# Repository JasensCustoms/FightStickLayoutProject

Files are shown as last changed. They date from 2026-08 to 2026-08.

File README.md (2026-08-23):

# Arcade Control Panel Layouts, SVG and DXF Cut Files

**Arcade control panel layouts as true scale vector cut files, ready for CAD and CAM.**

The founding set is converted from [slagcoin.com](https://www.slagcoin.com/joystick/layout.html). More layouts get added over time, from other sources and drawn fresh, and every one carries its own credit.






Everything is drawn 1:1 in millimeters, ready to send to a laser, router or CNC. Three groups:

- **[Lever Based Layouts](#lever-based-layouts)**, anything with a joystick. The 21 Slagcoin arrangements, each supplied at 3 different lever positions and in both 30 mm and 24 mm button sizes, plus panels taken from commercial sticks, real cabinets and the community.
- **[Leverless / All Button Layouts](#leverless--all-button-layouts)**, 8 panels with no joystick, drawn as designed with their native mix of 24 mm and 30 mm holes.
- **[WASD Layouts](#wasd-layouts)**, every one of those lever layouts again with a four button directional cluster where the joystick was. The action buttons do not move.

There is also a **[case](case/README.md)**: a laser cut acrylic enclosure with 3D printed corner and center supports, 451 x 303 mm inside a 62.2 mm stack, which has room for any layout here several times over. **The case files have not been physically validated yet**, so read the disclaimer at the top of that page before cutting.

And a folder of **[support hardware](support%20hardware/README.md)**: cut files for the hardware that goes around a panel rather than in it. Connectors, pass throughs and anything else that needs a hole in a case wall or a plate, drawn 1:1 in DXF and SVG on the same conventions as everything else, with the origin on the main bore so placing one is a single translation. Drop them straight into a case wall or a panel file.

Every one of those also ships in an **inner support** version, where each button hole is merged with a relief slot for Sanwa OBSF snap in button ears. That comes to 584 layouts per format, 1168 files.

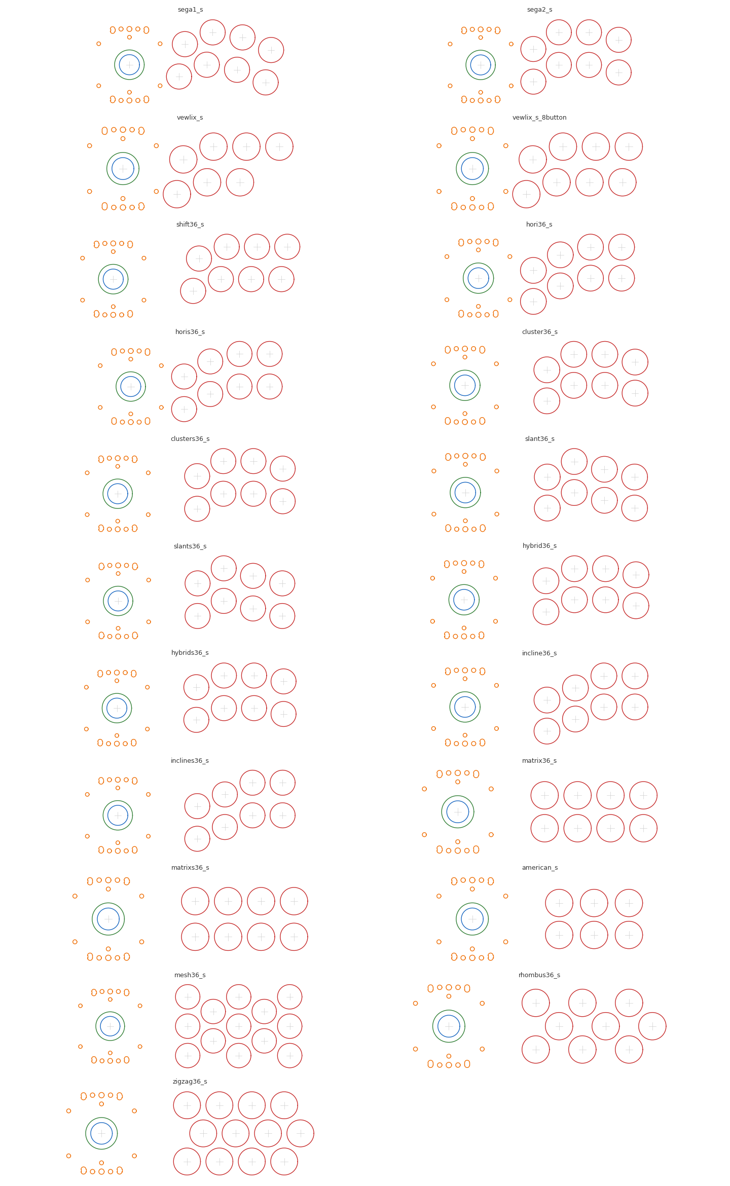
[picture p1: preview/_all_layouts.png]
The 21 Slagcoin joystick arrangements


*The 21 Slagcoin joystick arrangements at their stock lever position. Everything else, including the cabinet, commercial and community panels, is on the [contact sheets](preview/_sheet_lever_1.png) linked from each group below.*

---

## Credit where it belongs

> This repository started with **slagcoin.com**, and would not exist without it.
>
> That site has been the reference for arcade stick building for well over fifteen years. The panel layout page, the button and joystick measurement pages, the drilling and wiring guides. It is still the most careful and most useful writeup on the subject that anyone has put on the internet, and it was given away for free.
>
> Every layout in the founding set is traced from Slagcoin's own to scale diagrams, and each of those catalog entries quotes his description. If you build anything from these files, go read [the original pages](https://www.slagcoin.com/joystick/layout.html) first. There is a lot of reasoning there about *why* the layouts are shaped the way they are, and it will make you better at picking one.

The all button layouts come from a different place. They were created by [JasensCustoms.com](https://www.jasenscustoms.com) and members of the Panzer user community, and are credited in [their own section](#leverless--all-button-layouts). The S24, S30 and B30 layouts belong to [ASI](#asi-s24). The Mortal Kombat 3 panel, and its Japanese hardware variant, are traced from a dimensioned drawing by **Twistedsymphony**, hosted at [classicarcadecabinets.com](https://www.classicarcadecabinets.com/mortal-kombat-3.html). The Neo Geo MVS Type 1 panel comes from a drilling template by **Crowquilll**. The other four Neo Geo panels, Type 2, the Mini, the MVS-U4 and the SC19-4, were requested and researched by **KidGamer77** on [issue 3](https://github.com/JasensCustoms/FightStickLayoutProject/issues/3) and measured from the reference art found there. The two IST MakeStick layouts were requested by **lasagnasf** on [issue 4](https://github.com/JasensCustoms/FightStickLayoutProject/issues/4) and recreated from the product photographs supplied with it; the layout is IST Mall's.

**Where a layout came from is recorded with the layout.** Every catalog entry names its origin, and [NOTICE.md](NOTICE.md) is the full register of sources. Nothing in here silently claims someone else's design work.

---

## Contents

- [Quick start](#quick-start)
- [What is in the box](#what-is-in-the-box)
- [Reading the file names](#reading-the-file-names)
- [What is in every file](#what-is-in-every-file)
- [Joystick spacing](#joystick-spacing)
- [24 mm button versions](#24-mm-button-versions)
- [Inner support versions](#inner-support-versions)
- [Lever Based Layouts](#lever-based-layouts)
  - [Sega Astro City / Blast City P1](#sega-astro-city--blast-city-p1)
  - [Sega P2, non slanted](#sega-p2-non-slanted)
  - [Vewlix, 7 button as drawn](#vewlix-7-button-as-drawn)
  - [Vewlix 4+4, 8 button](#vewlix-44-8-button)
  - [Generic shift](#generic-shift)
  - [Hori transitioning](#hori-transitioning)
  - [Hori transitioning, spaced rows](#hori-transitioning-spaced-rows)
  - [Clustered arcade](#clustered-arcade)
  - [Clustered arcade, spaced rows](#clustered-arcade-spaced-rows)
  - [Direct slant](#direct-slant)
  - [Direct slant, spaced rows](#direct-slant-spaced-rows)
  - [Moderate / hybrid](#moderate--hybrid)
  - [Moderate / hybrid, spaced rows](#moderate--hybrid-spaced-rows)
  - [Straight incline](#straight-incline)
  - [Straight incline, spaced rows](#straight-incline-spaced-rows)
  - [Square grid](#square-grid)
  - [Square grid, spaced rows](#square-grid-spaced-rows)
  - [Capcom USA Street Fighter](#capcom-usa-street-fighter)
  - [Capcom USA Street Fighter, American Parts](#capcom-usa-street-fighter-american-parts)
  - [Mesh template](#mesh-template)
  - [Rhombus template](#rhombus-template)
  - [Zigzag template](#zigzag-template)
  - [ASI S24](#asi-s24)
  - [ASI S30](#asi-s30)
  - [JasensCustoms Sega 2P IMPACT](#jasenscustoms-sega-2p-impact)
  - [Mortal Kombat 3 / Ultimate MK3](#mortal-kombat-3--ultimate-mk3)
  - [Mortal Kombat 3, Japanese hardware](#mortal-kombat-3-japanese-hardware)
  - [Neo Geo MVS Type 1](#neo-geo-mvs-type-1)
  - [Neo Geo MVS Type 1, American hardware](#neo-geo-mvs-type-1-american-hardware)
  - [Neo Geo MVS Type 2](#neo-geo-mvs-type-2)
  - [Neo Geo MVS Type 2, American hardware](#neo-geo-mvs-type-2-american-hardware)
  - [Neo Geo Mini](#neo-geo-mini)
  - [Neo Geo Mini, American hardware](#neo-geo-mini-american-hardware)
  - [Neo Geo MVS-U4](#neo-geo-mvs-u4)
  - [Neo Geo SC19-4](#neo-geo-sc19-4)
  - [IST MakeStick Type 1](#ist-makestick-type-1)
  - [IST MakeStick Type 3](#ist-makestick-type-3)
  - [Vewlix 4+4 plus four, modern](#vewlix-44-plus-four-modern)
  - [Vewlix 10 button, two 30 mm](#vewlix-10-button-two-30-mm)
  - [Full index](#full-index)
- [Leverless / All Button Layouts](#leverless--all-button-layouts)
  - [Traditional](#traditional)
  - [Modern](#modern)
  - [Tomahawk](#tomahawk)
  - [Aegis](#aegis)
  - [Shiokenstar](#shiokenstar)
  - [Slab Split](#slab-split)
  - [Split Modern](#split-modern)
  - [ASI B30](#asi-b30)
  - [All button index](#all-button-index)
- [WASD Layouts](#wasd-layouts)
  - [WASD directional cluster](#wasd-directional-cluster)
  - [Sega Astro City / Blast City P1, WASD](#sega-astro-city--blast-city-p1-wasd)
  - [Sega P2, non slanted, WASD](#sega-p2-non-slanted-wasd)
  - [Vewlix, 7 button as drawn, WASD](#vewlix-7-button-as-drawn-wasd)
  - [Vewlix 4+4, 8 button, WASD](#vewlix-44-8-button-wasd)
  - [Generic shift, WASD](#generic-shift-wasd)
  - [Hori transitioning, WASD](#hori-transitioning-wasd)
  - [Hori transitioning, spaced rows, WASD](#hori-transitioning-spaced-rows-wasd)
  - [Clustered arcade, WASD](#clustered-arcade-wasd)
  - [Clustered arcade, spaced rows, WASD](#clustered-arcade-spaced-rows-wasd)
  - [Direct slant, WASD](#direct-slant-wasd)
  - [Direct slant, spaced rows, WASD](#direct-slant-spaced-rows-wasd)
  - [Moderate / hybrid, WASD](#moderate--hybrid-wasd)
  - [Moderate / hybrid, spaced rows, WASD](#moderate--hybrid-spaced-rows-wasd)
  - [Straight incline, WASD](#straight-incline-wasd)
  - [Straight incline, spaced rows, WASD](#straight-incline-spaced-rows-wasd)
  - [Square grid, WASD](#square-grid-wasd)
  - [Square grid, spaced rows, WASD](#square-grid-spaced-rows-wasd)
  - [Capcom USA Street Fighter, WASD](#capcom-usa-street-fighter-wasd)
  - [Mesh template, WASD](#mesh-template-wasd)
  - [Rhombus template, WASD](#rhombus-template-wasd)
  - [Zigzag template, WASD](#zigzag-template-wasd)
  - [ASI S24, WASD](#asi-s24-wasd)
  - [ASI S30, WASD](#asi-s30-wasd)
  - [JasensCustoms Sega 2P IMPACT, WASD](#jasenscustoms-sega-2p-impact-wasd)
  - [Mortal Kombat 3, Japanese hardware, WASD](#mortal-kombat-3-japanese-hardware-wasd)
  - [Neo Geo MVS Type 1, WASD](#neo-geo-mvs-type-1-wasd)
  - [Vewlix 4+4 plus four, modern, WASD](#vewlix-44-plus-four-modern-wasd)
  - [Vewlix 10 button, two 30 mm, WASD](#vewlix-10-button-two-30-mm-wasd)
  - [WASD index](#wasd-index)
- [Before you cut](#before-you-cut)
- [Screw in buttons and nut clearance](#screw-in-buttons-and-nut-clearance)
- [How these were made](#how-these-were-made)
- [License and attribution](#license-and-attribution)

---

## Quick start

**If you just want the popular one:** grab [`vewlix_s_8button.dxf`](dxf/vewlix_s_8button.dxf). That is the modern 8 button tournament layout, 30 mm buttons, at the stock Japanese lever position. Running 24 mm buttons? Take [`vewlix_s_8button_24mm_buttons.dxf`](dxf/vewlix_s_8button_24mm_buttons.dxf) instead.

**If you are not sure which layout suits you:** print a few SVGs at 100 percent scale, lay your hand on them, and pick the one that feels right. This costs a sheet of paper and will save you a ruined panel.

**Three things to do before sending anything to a machine:**

1. Delete whichever of the two joystick bore layers you are not using.
2. Delete the `REFERENCE` layer. Those crosshairs are alignment aids, not cuts.
3. Cut one in scrap first.

---

## What is in the box

```
dxf/        584 layouts as .dxf   (R2010, millimeters, $INSUNITS = 4)
svg/        the same 584 layouts as .svg  (1 user unit = 1 mm)
preview/    per layout PNG previews plus contact sheets and diagrams
case/       a laser cut acrylic case with 3D printed supports, DXF, STL and STEP
support hardware/   connector and pass through cutouts, DXF and SVG
README.md   this file
```

Joystick arrangements are built out to 6 files per format: 3 lever positions, each at 30 mm and 24 mm button sizes. The 21 of them come to 126 per format. All button layouts ship as a single file each, adding 7 more, manufacturer layouts likewise, adding 3, and the cabinet layouts add 4, two Mortal Kombat hardware sets and two Neo Geo MVS Type 1, for 140. The Capcom layout also ships an American Parts cut, and the Vewlix has two community variants at two lever spacings each, a twelve button and a ten button, making 145. The JasensCustoms Sega 2P IMPACT plate adds a 30 mm and a 24 mm cut, for 147, and the WASD directional cluster adds one more, for 148. Every one of the 136 Japanese Parts lever layouts then gets a WASD version, for 284. The four Neo Geo panels added from issue 3 bring six more files, two of them American Parts cuts, and the two IST MakeStick layouts bring two, for 292; none of those eight gets a WASD version, because none was asked for. Each of the 292 has an inner support twin, doubling the count to 584 per format and 1168 in total.

New layouts follow the same naming and layer conventions, so anything you script against the current set keeps working.

---

## Reading the file names

```
sega1_s                    the layout as Slagcoin drew it
       ^ "_s" is Slagcoin's own suffix for the 72 PPI source image

cluster36_s                the "36" means 36 mm button spacing

clusters36_s               the extra "s" before the "36" means Spaced rows.
                           Same layout, more gap between the two rows.
                           Standard rows sit 36 mm apart, spaced rows 39 mm.

vewlix_s_82mm_spacing      joystick moved to 82 mm from the first button column
vewlix_s_95mm_spacing      joystick moved to 95 mm from the first button column

vewlix_s_24mm_buttons                24 mm buttons instead of 30 mm
vewlix_s_82mm_spacing_24mm_buttons   both at once

traditional_all_button     a leverless layout. No lever, so no spacing or
                           button size variants, just the one file.

<name>_japanese_parts      GL mounting system, 30 mm or 24 mm snap in buttons,
                           inner support panel with ear relief tabs.

<name>_american_parts      IL Eurojoystick 2 lever, 1.125 in nut mount buttons,
                           inner support panel that is a plain copy.

                           Where a layout ships both fits, BOTH carry a suffix
                           and the button centers are identical between them.
                           One panel drilling pattern, two sets of hardware.
                           Anything without a parts suffix is Japanese Parts,
                           which is the default throughout the library.

inner_support_traditional_all_button       any file, with Sanwa OBSF ear
inner_support_vewlix_s_82mm_spacing        relief slots added on every button
```

The `inner_support_` prefix goes on the front. Every other suffix keeps its meaning and its order.

---

## What is in every file

Millimeters throughout. In the SVG, 1 user unit equals 1 mm and the width and height are declared in mm, so it imports at true size without scaling. The origin (0,0) is the center of the joystick shaft hole, with +X toward the buttons and +Y toward the back of the panel.

There is no text, no title block and no border. Cut geometry only.

### Layers

| Layer | DXF color | Contents |
|---|---|---|
| `BUTTONS` | 1, red | 30 mm button holes |
| `JOYSTICK_BORE_24` | 5, blue | 24 mm shaft clearance hole |
| `JOYSTICK_BORE_35.25` | 3, green | 35.25 mm bore matching the mounting plate |
| `GL_PLATE_HOLES` | 2, yellow | Lever mounting holes and slots |
| `REFERENCE` | 8, gray | Center crosshairs only, do not cut |

On inner support files the button layers carry closed profiles rather than plain circles. No extra layer is added.

All button layouts use a different set, since they have no lever and mix hole sizes: `BUTTONS_24`, `BUTTONS_30` and `REFERENCE`. See [Leverless / All Button Layouts](#leverless--all-button-layouts).

The Mortal Kombat cabinet panel runs different lever hardware again, so it carries `JOYSTICK_BORE_35` and `IL_PLATE_HOLES` in place of the two bores and `GL_PLATE_HOLES`. Its `_jp` twin uses the standard five layers like everything else. See [Mortal Kombat 3 / Ultimate MK3](#mortal-kombat-3--ultimate-mk3).

### The two joystick bores

They sit concentrically on top of each other. **Pick one and delete the other.**

| Bore | Use it when |
|---|---|
| **24 mm** | The mounting plate bolts flat to the underside of the panel and only the shaft comes through. This is the classic shaft clearance hole. |
| **35.25 mm** | You want a recess or pocket, or the plate sitting up inside the opening. Matches the bore of the universal mounting plate. |

### Lever mounting holes

`GL_PLATE_HOLES` carries the universal mounting plate pattern, so a single panel will accept a range of different levers. You get two ear holes and two slots at the top and bottom, a pair on the centerline, and four corner holes. Drill only the ones your lever actually needs and ignore the rest.

The plate runs tall rather than wide, so rotate that layer 90 degrees if your lever mounts sideways.

Button holes are 30 mm unless the file name says `_24mm_buttons`. See [24 mm button versions](#24-mm-button-versions).

---

## Joystick spacing

This section applies to the joystick layouts. All button layouts have no lever, so they have no spacing variants.

Slagcoin dimensions every diagram from the centerline of the first (left most) button column. That is the reference point. When the original drawings put "59mm / 63mm / 95mm" next to the stick, that is the horizontal distance from the stick center back to that column.

> A horizontal distance of about 5.9, 6.3, or 9.5 centimeters between the middle of the joystick and the middle of the leftmost button are common standards.
>
> *Slagcoin*

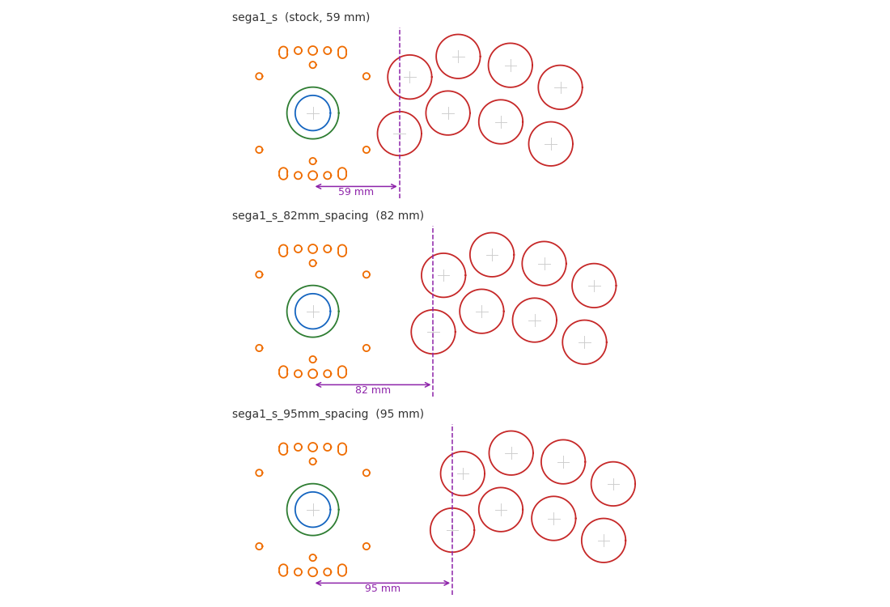
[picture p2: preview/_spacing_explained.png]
Joystick spacing explained


Every layout ships three times:

| Suffix | Joystick position |
|---|---|
| *(none)* | Exactly as Slagcoin drew it |
| `_82mm_spacing` | 82 mm from the first button column |
| `_95mm_spacing` | 95 mm from the first button column |

Only the horizontal distance changes. Everything vertical stays put, including how high the stick sits relative to the rows. The button cluster, both bores and the plate holes are identical across all three.

Stock spacing is not the same on every layout:

| Stock spacing | Layouts |
|---|---|
| 59 mm | `sega1_s`, `vewlix_s`, `vewlix_s_8button` |
| 63 mm | `sega2_s` |
| 63.75 mm | `hori36_s`, `horis36_s` |
| 95 mm | the other 15 |

### Which one do you want

| Spacing | Feel |
|---|---|
| **59 to 63 mm** | Japanese arcade standard. Hands close together, elbows fairly straight. This is what an Astro City or a Vewlix actually feels like. |
| **82 mm** | The middle ground. Good for big hands, a wider stance, or a bat top or tall shaft where your left hand needs more room. |
| **95 mm** | American and Capcom style roomy spacing. Also useful for a large lever, a Korean lever with a big plate, or clearing a taller dust washer. |

Two honest caveats:

1. Fifteen layouts are already drawn at 95 mm, so for those the `_95mm_spacing` file is identical to the stock file. It exists so the naming stays predictable across the whole set.
2. For those same fifteen, the `_82mm_spacing` file pulls the lever closer to the buttons rather than further away.

---

## 24 mm button versions

Every joystick layout also comes in a 24 mm button version, marked `_24mm_buttons` in the file name. All button layouts are drawn with their native mix of 24 mm and 30 mm holes and do not need this treatment.

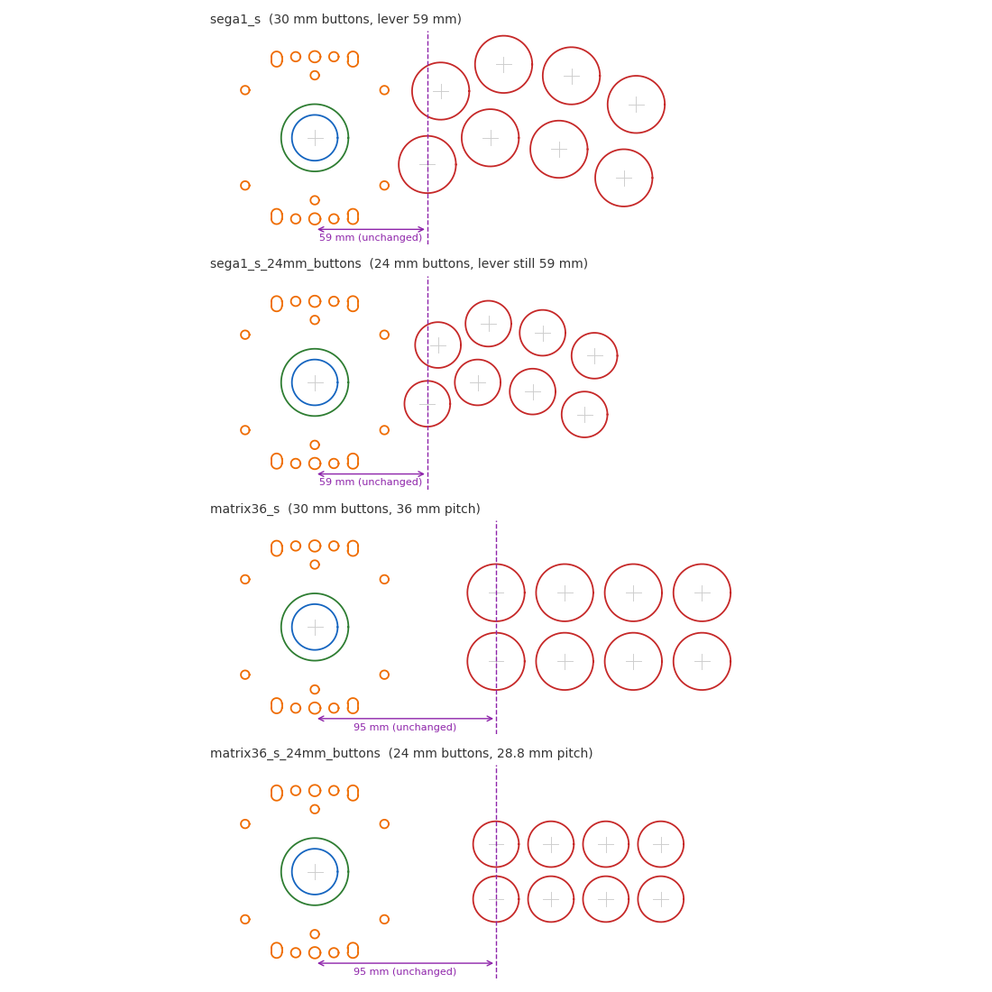
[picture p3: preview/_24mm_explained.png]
24 mm button versions


These are not simply the same drawing with smaller holes punched in it. The whole button cluster is scaled down by the same factor as the holes, so the layout keeps its proportions:

| | 30 mm files | 24 mm files |
|---|---|---|
| Button hole | 30.00 mm | 24.00 mm |
| Button to button spacing | as drawn | scaled by 0.8, horizontally and vertically |
| Typical pitch | 36 mm | 28.8 mm |
| Joystick position | unchanged | **unchanged** |
| Lever spacing (59 / 63 / 82 / 95 mm) | unchanged | **unchanged** |
| Mounting hardware | unchanged | **unchanged** |

**What stays fixed.** The joystick sits at the origin in both versions, the mounting plate holes and both bores are byte for byte identical, and the distance from the lever to the first button column does not move. A `_95mm_spacing_24mm_buttons` file still has its lever at exactly 95 mm.

**How the shrink is anchored.** Horizontally the cluster is scaled about the first button column, which is the datum the lever spacing is measured to, so that distance is preserved exactly. Vertically it is scaled about the joystick centerline, which is the datum Slagcoin's own vertical callouts use, so the lever keeps the same proportional position relative to the rows.

> **Check your button clearance before cutting.** A 36 mm pitch becomes 28.8 mm, and on the tighter layouts the closest pair lands around 28.4 mm. Snap in 24 mm buttons are usually fine at that spacing. Screw in 24 mm buttons have wider nuts and may not be, so measure yours first. Each layout below lists its closest pitch at both sizes.

---

## Inner support versions

Every layout in the repository has an inner support twin, named by putting `inner_support_` in front of the ordinary file name.

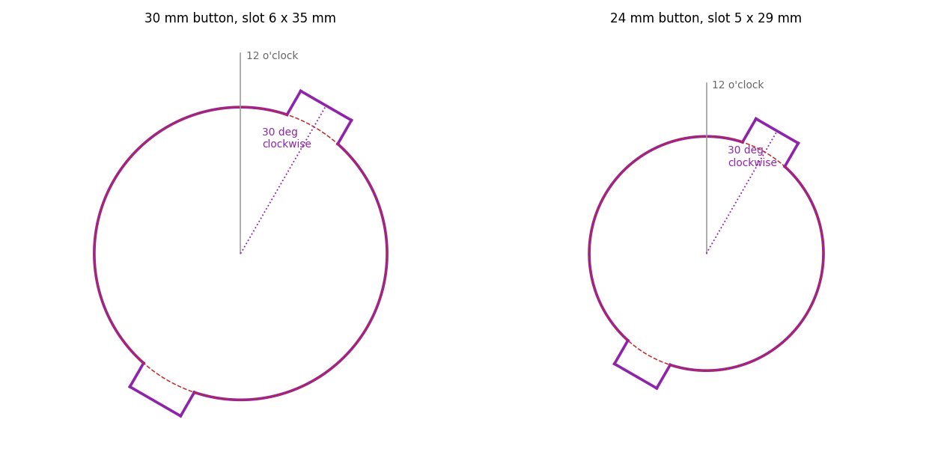
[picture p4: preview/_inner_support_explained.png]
Inner support ear slots


An inner support file is the complete original layout with every button hole replaced by a single closed profile: the hole unioned with a rectangular ear relief slot. The slot is centered on the hole and its long axis is rotated **30 degrees from vertical**, clockwise by default, so it runs from roughly 7 o'clock up to 1 o'clock.

| Button | Slot size | Sticks out past the hole |
|---|---|---|
| 30 mm | 6 mm wide x 35 mm long | 2.5 mm each end |
| 24 mm | 5 mm wide x 29 mm long | 2.5 mm each end |

**The slots are modeled on the retention ears of Sanwa OBSF snap in buttons.** Those buttons have a pair of sprung tabs on the body that need somewhere to sit. On a stacked panel the top sheet takes the plain hole and the sheet underneath, the inner support, needs the ear clearance cut into it as well.

**One profile per button.** The circle and the slot are boolean unioned into a single closed outline, so there is exactly one contour to cut per button and no overlapping shapes to clean up. In DXF it is a closed `LWPOLYLINE` with true arc segments carried as bulges, not a polygon approximation. In SVG it is a closed `path` using `A` arc commands.

**Slot direction is not uniform.** The default is 30 degrees clockwise from vertical, but on tightly packed layouts two neighboring buttons pointing their ears at each other leaves a dangerously thin web of material, and on the tightest layouts the two slots actually cut into one another. Where that happens the slot is turned to whichever direction opens the gap back up. Slots are allowed to sit at any multiple of 15 degrees, so a crowded button has eleven alternatives to the default rather than just its mirror image.

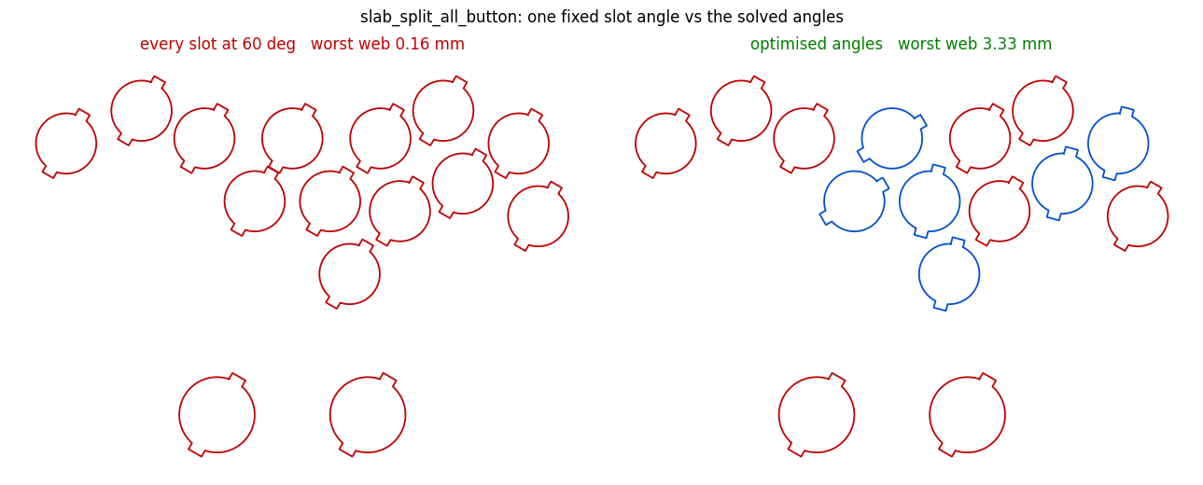
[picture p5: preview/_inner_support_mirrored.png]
One fixed slot angle versus the solved angles


The angles are solved per layout rather than picked by eye. For every pair of neighboring buttons the exact clearance between the two finished profiles is computed in closed form, for all 144 combinations of their angles. The solver then searches for the assignment that maximises the *smallest* web anywhere on the panel, and once it has found that maximum it makes a second pass pulling every button that can afford it back to the default angle. So a panel only carries a rotated slot where the rotation is actually buying material.

63 of the 136 layouts needed at least one rotated slot, 404 slots out of 1186 in total. 73 layouts are untouched at the default angle throughout.

The result across the whole library:

| | worst web on any layout | layouts under 2 mm | layouts with slots that overlap |
|---|---|---|---|
| Every slot at 30 deg clockwise | 0.00 mm | 10 | 3 |
| Solved angles | **3.33 mm** | **0** | **0** |

No layout now has a web under 3.3 mm. The tightest is `slab_split_all_button` at 3.33 mm; everything else is 3.83 mm or better. On 25 of the 52 distinct button patterns the slots stop being the limiting factor entirely, meaning the thinnest material on the panel is the plain hole to hole gap and adding the ear slots costs nothing at all.

**Buttons only.** Nothing is added to a joystick bore or to any mounting hole. The union is keyed off the button layers rather than off hole diameter, so the 24 mm `JOYSTICK_BORE_24` circle is never mistaken for a 24 mm button.

Profiles stay on the same layer their circle was on, and every other entity in the file is identical to its standard counterpart.

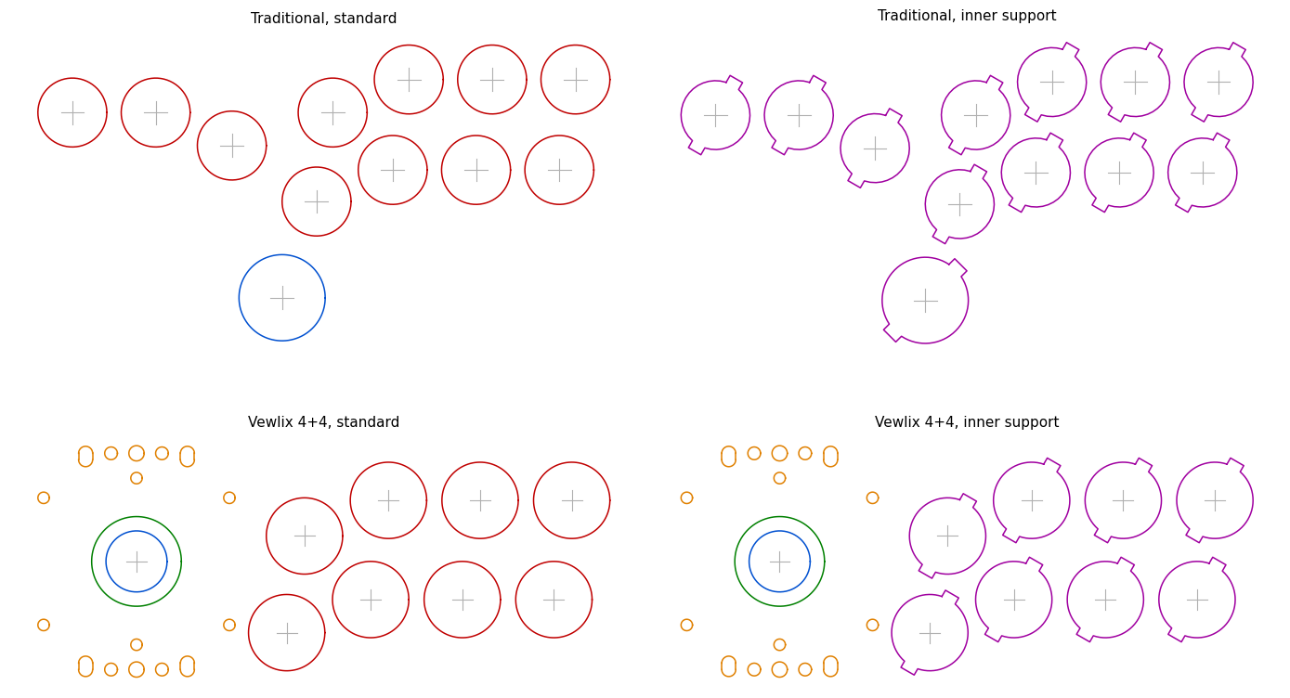
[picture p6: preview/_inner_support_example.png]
Standard versus inner support


Every layout has its own inner support preview in `preview/`, and each catalog entry below shows it beside the standard version. Contact sheets for the whole family:

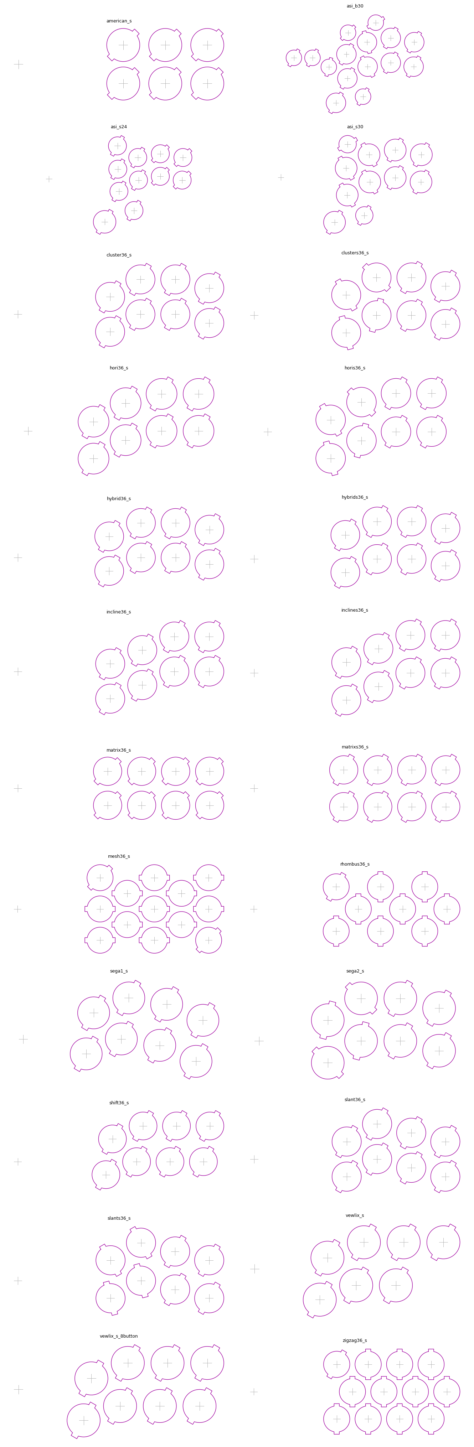
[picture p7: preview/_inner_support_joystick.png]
Inner support, joystick layouts


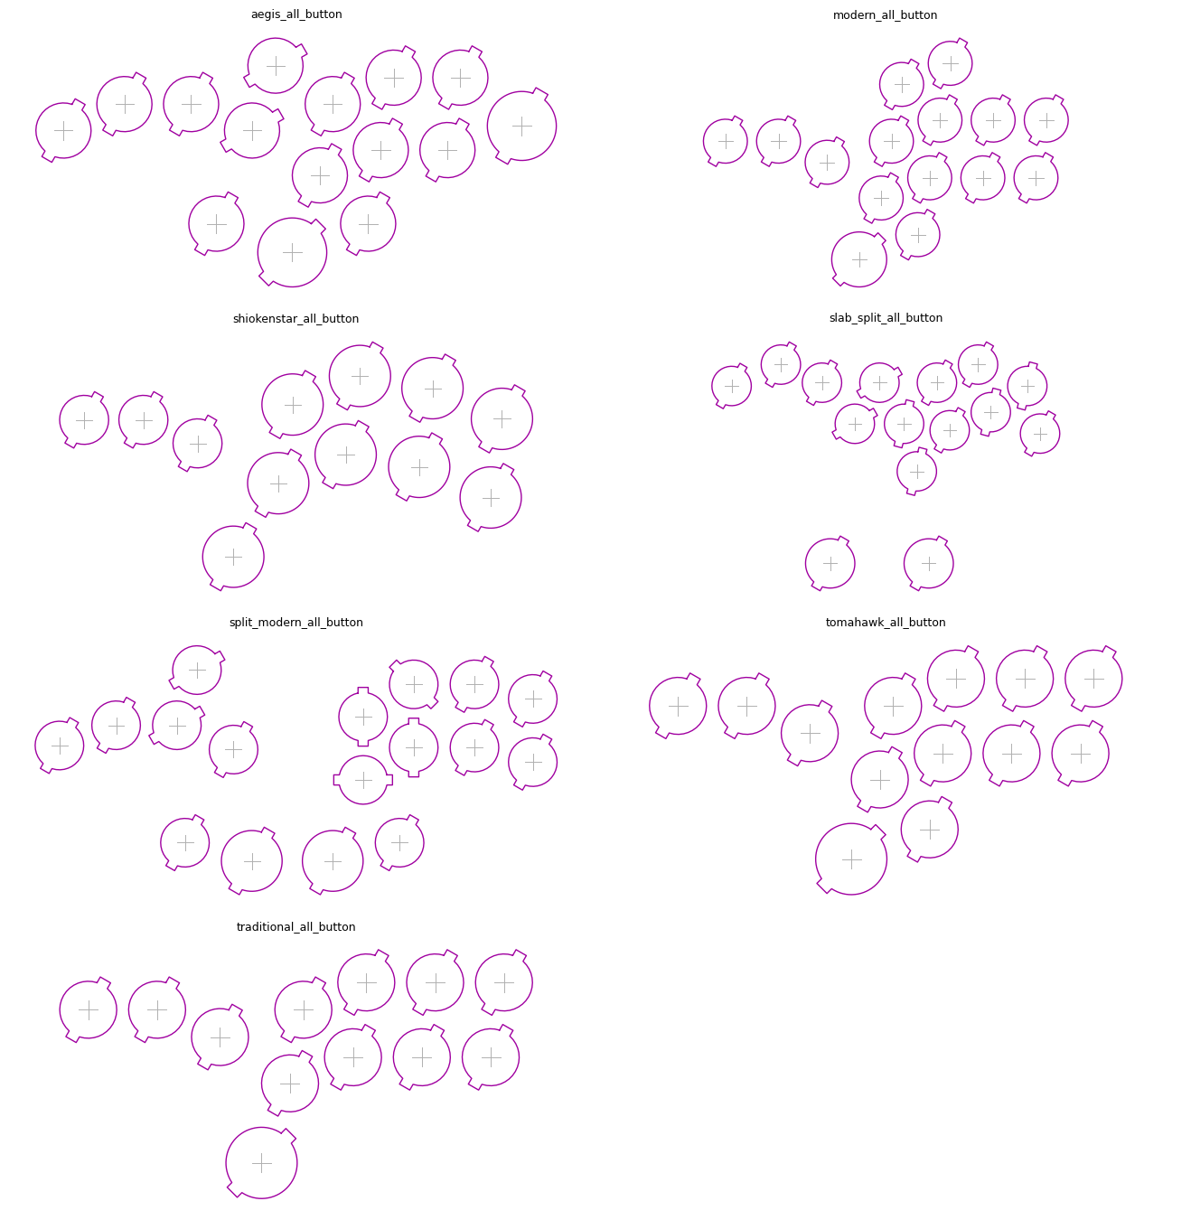
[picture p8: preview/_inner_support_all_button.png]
Inner support, all button layouts


> **Why a union rather than two shapes.** Overlapping closed profiles are handled differently by different CAM packages, and getting it wrong leaves a floating sliver where the slot crosses the hole edge. A single merged contour removes the question.

---

## Lever Based Layouts

Every panel here has a joystick. Leverless panels are in [Leverless / All Button Layouts](#leverless--all-button-layouts).

Previews show the stock lever position with 30 mm buttons. Red is button holes, green and blue are the two joystick bores, orange is the lever mounting pattern, gray is the non cutting reference layer.

The first 21 entries are converted from Slagcoin diagrams, so each one quotes his description of it. Everything after them comes from a commercial stick, a cabinet drawing or the community, and states its origin and its parts in its own entry.

**All 147 lever layouts on three sheets: [page 1](preview/_sheet_lever_1.png), [page 2](preview/_sheet_lever_2.png), [page 3](preview/_sheet_lever_3.png).** One family per row, its lever spacings and both button sizes across, every tile at the same scale so tile size means physical size. Standard files only, since the inner support twins are the same holes with a relief slot added.

---

**Japanese arcade standards.** The most used layouts on earth. Slanted rows that follow the natural arch of your fingers.

### Sega Astro City / Blast City P1

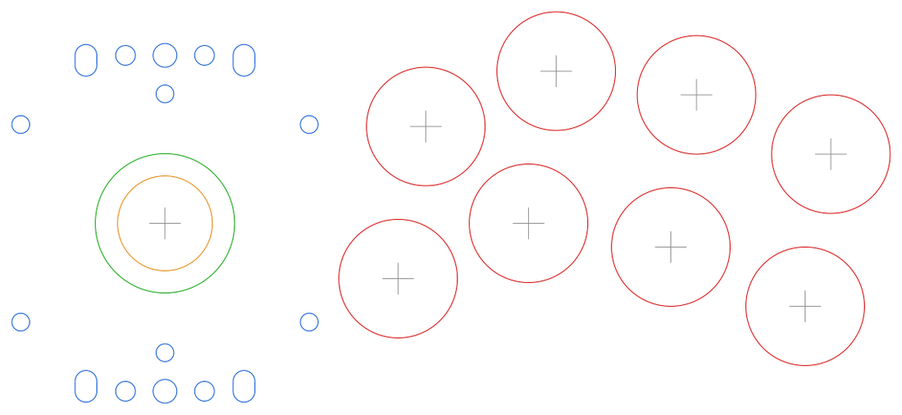
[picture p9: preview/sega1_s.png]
sega1_s
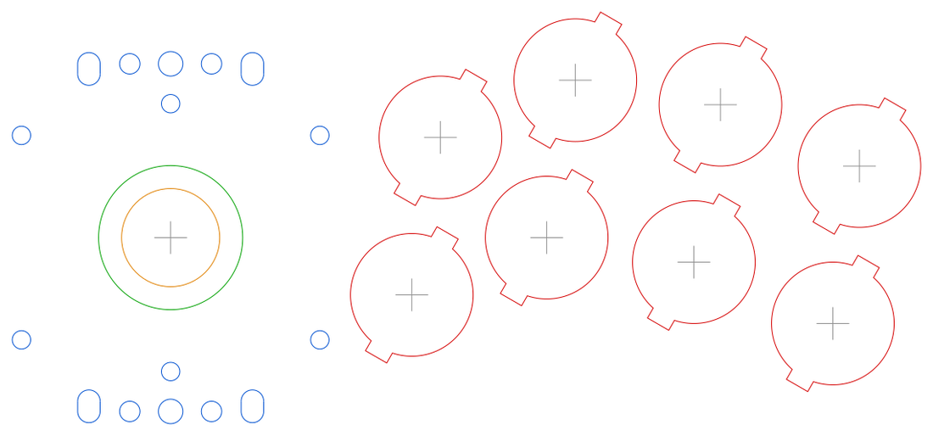
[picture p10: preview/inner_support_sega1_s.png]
inner_support_sega1_s
 

*Left: standard. Right: inner support, with the hole and its Sanwa OBSF ear relief merged into one profile.*

> A precise diagram of the Sega layout used in Astro City, Blast City, Net City, and Versus City cabinets for player 1 or single player. This layout (or an almost identical one) is used in most arcade machines and controllers in Japan. It is very appropriate for quick, comfortable, and precise play. If you have not used a slanted layout like this, feel it; it may surprise you.
>
> *Slagcoin*

If you have played on a Japanese candy cab, this is the muscle memory you already have. Every column is slanted, the top row sits a touch to the right of the bottom row, and the whole cluster arcs up and then back down.

> **Nut clearance:** the two closest buttons land just under 36 mm apart, so standard Sanwa screw in nuts can touch. Seimitsu nuts or snap ins solve it.

**8 buttons**  |  stock lever at **59 mm**  |  closest button pitch 35.7 mm at 30 mm, 28.6 mm at 24 mm  |  cut envelope 222 x 99 mm

More previews: [24 mm buttons](preview/sega1_s_24mm_buttons.png) &middot; [24 mm inner support](preview/inner_support_sega1_s_24mm_buttons.png)

| Version | 30 mm buttons | 24 mm buttons |
|---|---|---|
| Stock | [dxf](dxf/sega1_s.dxf) &middot; [svg](svg/sega1_s.svg) | [dxf](dxf/sega1_s_24mm_buttons.dxf) &middot; [svg](svg/sega1_s_24mm_buttons.svg) |
| Stock, inner support | [dxf](dxf/inner_support_sega1_s.dxf) &middot; [svg](svg/inner_support_sega1_s.svg) | [dxf](dxf/inner_support_sega1_s_24mm_buttons.dxf) &middot; [svg](svg/inner_support_sega1_s_24mm_buttons.svg) |
| 82 mm | [dxf](dxf/sega1_s_82mm_spacing.dxf) &middot; [svg](svg/sega1_s_82mm_spacing.svg) | [dxf](dxf/sega1_s_82mm_spacing_24mm_buttons.dxf) &middot; [svg](svg/sega1_s_82mm_spacing_24mm_buttons.svg) |
| 82 mm, inner support | [dxf](dxf/inner_support_sega1_s_82mm_spacing.dxf) &middot; [svg](svg/inner_support_sega1_s_82mm_spacing.svg) | [dxf](dxf/inner_support_sega1_s_82mm_spacing_24mm_buttons.dxf) &middot; [svg](svg/inner_support_sega1_s_82mm_spacing_24mm_buttons.svg) |
| 95 mm | [dxf](dxf/sega1_s_95mm_spacing.dxf) &middot; [svg](svg/sega1_s_95mm_spacing.svg) | [dxf](dxf/sega1_s_95mm_spacing_24mm_buttons.dxf) &middot; [svg](svg/sega1_s_95mm_spacing_24mm_buttons.svg) |
| 95 mm, inner support | [dxf](dxf/inner_support_sega1_s_95mm_spacing.dxf) &middot; [svg](svg/inner_support_sega1_s_95mm_spacing.svg) | [dxf](dxf/inner_support_sega1_s_95mm_spacing_24mm_buttons.dxf) &middot; [svg](svg/inner_support_sega1_s_95mm_spacing_24mm_buttons.svg) |

### Sega P2, non slanted

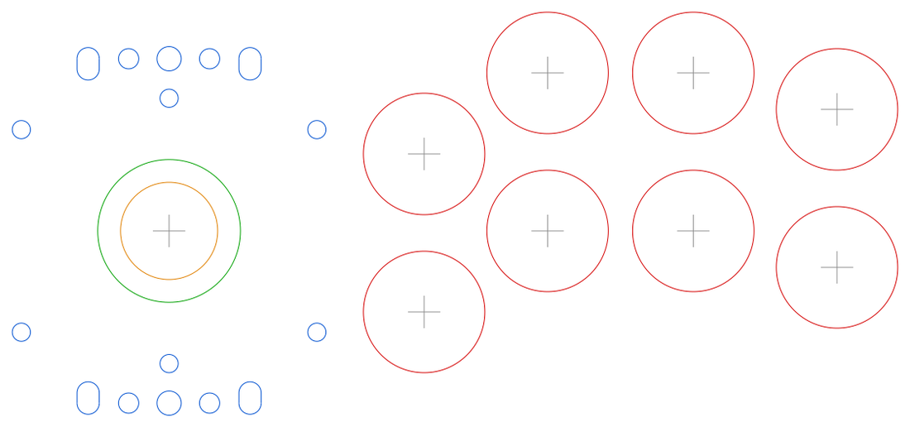
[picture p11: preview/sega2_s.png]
sega2_s
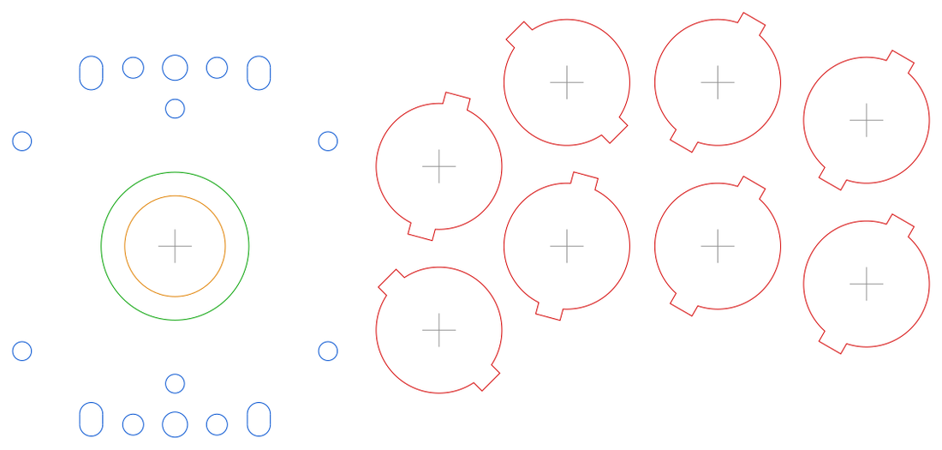
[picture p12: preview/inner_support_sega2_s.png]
inner_support_sega2_s
 

*Left: standard. Right: inner support, with the hole and its Sanwa OBSF ear relief merged into one profile.*

> A precise diagram of the Sega layout for player 2. It is very close to a non-slanted version of the player 1, but has a few differently proportioned buttons; it can be tilted to something similar to the player 1 layout. A few alternate placements of the pinky buttons are noted.
>
> *Slagcoin*

Straight columns instead of slanted ones. Easier to lay out, easier to fit in a rectangular panel, and plenty of people simply prefer it. Rows sit 39 mm apart and the pinky column steps down a little.

**8 buttons**  |  stock lever at **63 mm**  |  closest button pitch 35.9 mm at 30 mm, 28.7 mm at 24 mm  |  cut envelope 219 x 100 mm

More previews: [24 mm buttons](preview/sega2_s_24mm_buttons.png) &middot; [24 mm inner support](preview/inner_support_sega2_s_24mm_buttons.png)

| Version | 30 mm buttons | 24 mm buttons |
|---|---|---|
| Stock | [dxf](dxf/sega2_s.dxf) &middot; [svg](svg/sega2_s.svg) | [dxf](dxf/sega2_s_24mm_buttons.dxf) &middot; [svg](svg/sega2_s_24mm_buttons.svg) |
| Stock, inner support | [dxf](dxf/inner_support_sega2_s.dxf) &middot; [svg](svg/inner_support_sega2_s.svg) | [dxf](dxf/inner_support_sega2_s_24mm_buttons.dxf) &middot; [svg](svg/inner_support_sega2_s_24mm_buttons.svg) |
| 82 mm | [dxf](dxf/sega2_s_82mm_spacing.dxf) &middot; [svg](svg/sega2_s_82mm_spacing.svg) | [dxf](dxf/sega2_s_82mm_spacing_24mm_buttons.dxf) &middot; [svg](svg/sega2_s_82mm_spacing_24mm_buttons.svg) |
| 82 mm, inner support | [dxf](dxf/inner_support_sega2_s_82mm_spacing.dxf) &middot; [svg](svg/inner_support_sega2_s_82mm_spacing.svg) | [dxf](dxf/inner_support_sega2_s_82mm_spacing_24mm_buttons.dxf) &middot; [svg](svg/inner_support_sega2_s_82mm_spacing_24mm_buttons.svg) |
| 95 mm | [dxf](dxf/sega2_s_95mm_spacing.dxf) &middot; [svg](svg/sega2_s_95mm_spacing.svg) | [dxf](dxf/sega2_s_95mm_spacing_24mm_buttons.dxf) &middot; [svg](svg/sega2_s_95mm_spacing_24mm_buttons.svg) |
| 95 mm, inner support | [dxf](dxf/inner_support_sega2_s_95mm_spacing.dxf) &middot; [svg](svg/inner_support_sega2_s_95mm_spacing.svg) | [dxf](dxf/inner_support_sega2_s_95mm_spacing_24mm_buttons.dxf) &middot; [svg](svg/inner_support_sega2_s_95mm_spacing_24mm_buttons.svg) |

---

**Vewlix family.** The modern tournament standard. The top row is shifted right relative to the bottom row.

### Vewlix, 7 button as drawn

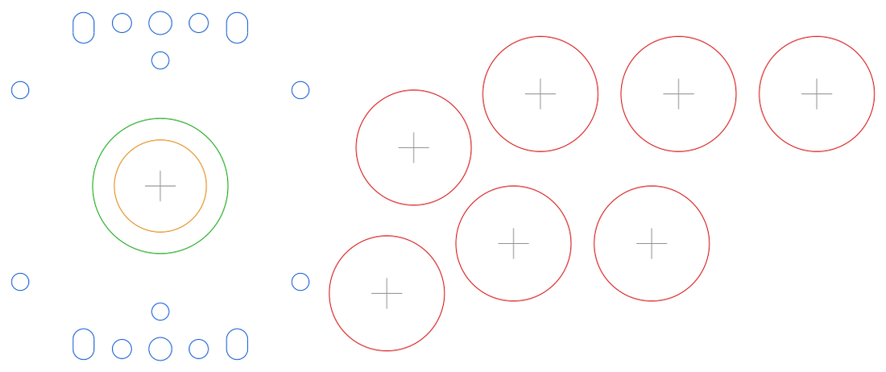
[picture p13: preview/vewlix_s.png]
vewlix_s
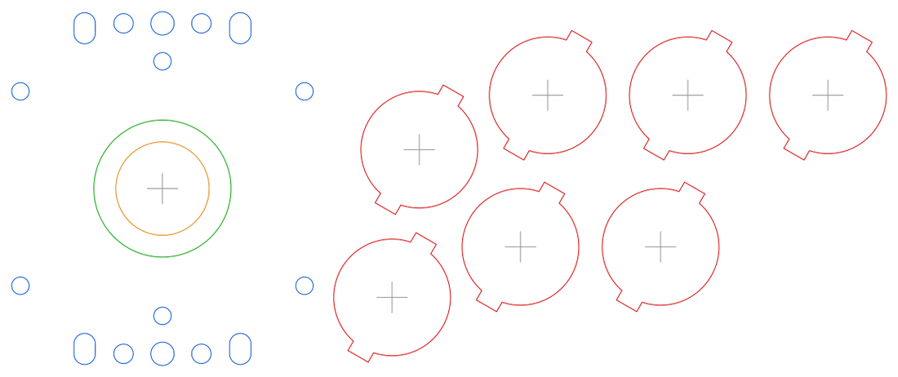
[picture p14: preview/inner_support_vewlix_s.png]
inner_support_vewlix_s
 

*Left: standard. Right: inner support, with the hole and its Sanwa OBSF ear relief merged into one profile.*

> This layout takes the arcade layout and shifts the top row a bit to the right. This is the precise layout used in Taito Vewlix cabinets. Note that the bottom index and middle finger buttons are closer than 36mm to one another; they will not work with nuts stocked with Sanwa screw-in buttons.
>
> *Slagcoin*

This is Slagcoin's diagram traced literally, and the original only draws 7 holes. The 8th position is marked on the source as a small optional dot rather than a real hole, so it lives in its own file below.

> **Nut clearance, and this one is real:** the closest button pair sits about 35.5 mm apart center to center. Standard Sanwa screw in nuts are roughly 35 to 36 mm across and they will fight each other. Use the thinner Seimitsu nuts, use snap in buttons, or plan on filing a nut flat.

**7 buttons**  |  stock lever at **59 mm**  |  closest button pitch 35.5 mm at 30 mm, 28.4 mm at 24 mm  |  cut envelope 225 x 91 mm

More previews: [24 mm buttons](preview/vewlix_s_24mm_buttons.png) &middot; [24 mm inner support](preview/inner_support_vewlix_s_24mm_buttons.png)

| Version | 30 mm buttons | 24 mm buttons |
|---|---|---|
| Stock | [dxf](dxf/vewlix_s.dxf) &middot; [svg](svg/vewlix_s.svg) | [dxf](dxf/vewlix_s_24mm_buttons.dxf) &middot; [svg](svg/vewlix_s_24mm_buttons.svg) |
| Stock, inner support | [dxf](dxf/inner_support_vewlix_s.dxf) &middot; [svg](svg/inner_support_vewlix_s.svg) | [dxf](dxf/inner_support_vewlix_s_24mm_buttons.dxf) &middot; [svg](svg/inner_support_vewlix_s_24mm_buttons.svg) |
| 82 mm | [dxf](dxf/vewlix_s_82mm_spacing.dxf) &middot; [svg](svg/vewlix_s_82mm_spacing.svg) | [dxf](dxf/vewlix_s_82mm_spacing_24mm_buttons.dxf) &middot; [svg](svg/vewlix_s_82mm_spacing_24mm_buttons.svg) |
| 82 mm, inner support | [dxf](dxf/inner_support_vewlix_s_82mm_spacing.dxf) &middot; [svg](svg/inner_support_vewlix_s_82mm_spacing.svg) | [dxf](dxf/inner_support_vewlix_s_82mm_spacing_24mm_buttons.dxf) &middot; [svg](svg/inner_support_vewlix_s_82mm_spacing_24mm_buttons.svg) |
| 95 mm | [dxf](dxf/vewlix_s_95mm_spacing.dxf) &middot; [svg](svg/vewlix_s_95mm_spacing.svg) | [dxf](dxf/vewlix_s_95mm_spacing_24mm_buttons.dxf) &middot; [svg](svg/vewlix_s_95mm_spacing_24mm_buttons.svg) |
| 95 mm, inner support | [dxf](dxf/inner_support_vewlix_s_95mm_spacing.dxf) &middot; [svg](svg/inner_support_vewlix_s_95mm_spacing.svg) | [dxf](dxf/inner_support_vewlix_s_95mm_spacing_24mm_buttons.dxf) &middot; [svg](svg/inner_support_vewlix_s_95mm_spacing_24mm_buttons.svg) |

### Vewlix 4+4, 8 button

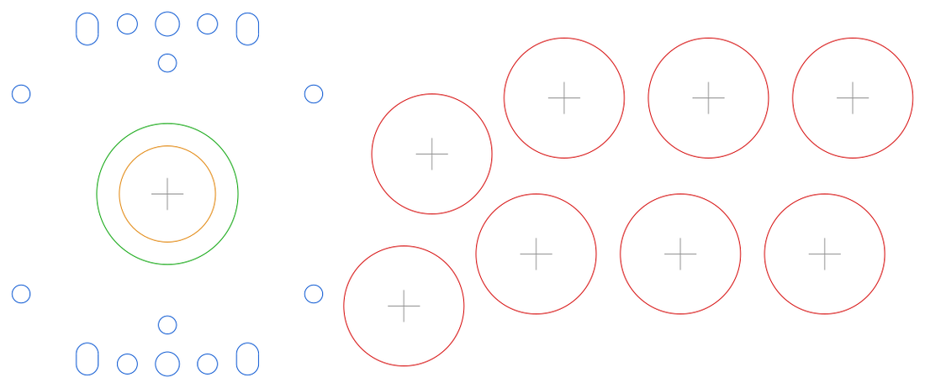
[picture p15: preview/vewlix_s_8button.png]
vewlix_s_8button
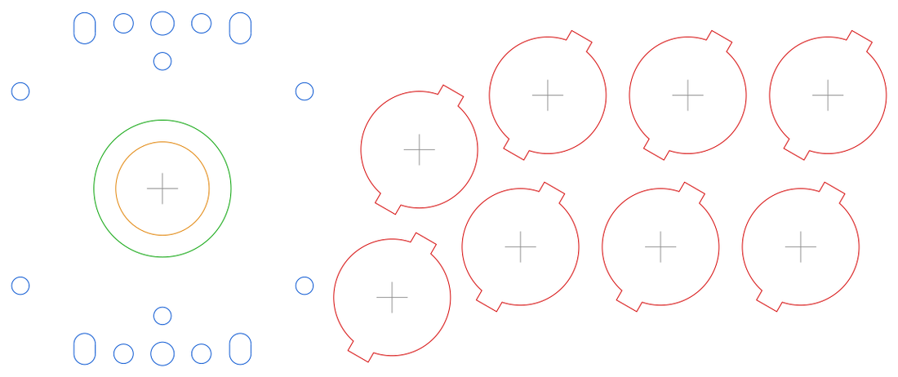
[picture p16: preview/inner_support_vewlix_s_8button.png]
inner_support_vewlix_s_8button
 

*Left: standard. Right: inner support, with the hole and its Sanwa OBSF ear relief merged into one profile.*

> The added isolated small dots in the images represent alternate places for joysticks and buttons.
>
> *Slagcoin*

Same layout as `vewlix_s` with the 8th hole added at the optional position Slagcoin marks with a dot. That completes a clean 4 top and 4 bottom grid, where each upper button sits slightly right of and well above its lower partner.

**This is the one most people actually want.** If you are building a modern 8 button stick and someone says "Vewlix layout", they mean this.

> Same nut clearance warning as `vewlix_s`.

**8 buttons**  |  stock lever at **59 mm**  |  closest button pitch 35.5 mm at 30 mm, 28.4 mm at 24 mm  |  cut envelope 225 x 91 mm

More previews: [24 mm buttons](preview/vewlix_s_8button_24mm_buttons.png) &middot; [24 mm inner support](preview/inner_support_vewlix_s_8button_24mm_buttons.png)

| Version | 30 mm buttons | 24 mm buttons |
|---|---|---|
| Stock | [dxf](dxf/vewlix_s_8button.dxf) &middot; [svg](svg/vewlix_s_8button.svg) | [dxf](dxf/vewlix_s_8button_24mm_buttons.dxf) &middot; [svg](svg/vewlix_s_8button_24mm_buttons.svg) |
| Stock, inner support | [dxf](dxf/inner_support_vewlix_s_8button.dxf) &middot; [svg](svg/inner_support_vewlix_s_8button.svg) | [dxf](dxf/inner_support_vewlix_s_8button_24mm_buttons.dxf) &middot; [svg](svg/inner_support_vewlix_s_8button_24mm_buttons.svg) |
| 82 mm | [dxf](dxf/vewlix_s_8button_82mm_spacing.dxf) &middot; [svg](svg/vewlix_s_8button_82mm_spacing.svg) | [dxf](dxf/vewlix_s_8button_82mm_spacing_24mm_buttons.dxf) &middot; [svg](svg/vewlix_s_8button_82mm_spacing_24mm_buttons.svg) |
| 82 mm, inner support | [dxf](dxf/inner_support_vewlix_s_8button_82mm_spacing.dxf) &middot; [svg](svg/inner_support_vewlix_s_8button_82mm_spacing.svg) | [dxf](dxf/inner_support_vewlix_s_8button_82mm_spacing_24mm_buttons.dxf) &middot; [svg](svg/inner_support_vewlix_s_8button_82mm_spacing_24mm_buttons.svg) |
| 95 mm | [dxf](dxf/vewlix_s_8button_95mm_spacing.dxf) &middot; [svg](svg/vewlix_s_8button_95mm_spacing.svg) | [dxf](dxf/vewlix_s_8button_95mm_spacing_24mm_buttons.dxf) &middot; [svg](svg/vewlix_s_8button_95mm_spacing_24mm_buttons.svg) |
| 95 mm, inner support | [dxf](dxf/inner_support_vewlix_s_8button_95mm_spacing.dxf) &middot; [svg](svg/inner_support_vewlix_s_8button_95mm_spacing.svg) | [dxf](dxf/inner_support_vewlix_s_8button_95mm_spacing_24mm_buttons.dxf) &middot; [svg](svg/inner_support_vewlix_s_8button_95mm_spacing_24mm_buttons.svg) |

### Generic shift

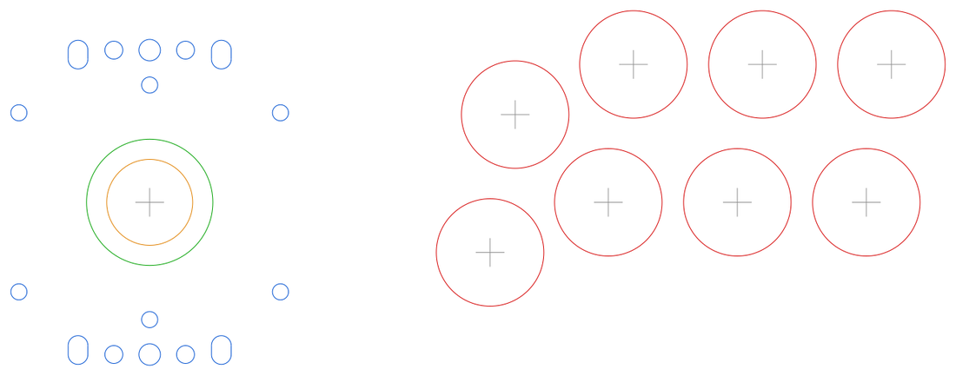
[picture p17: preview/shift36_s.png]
shift36_s
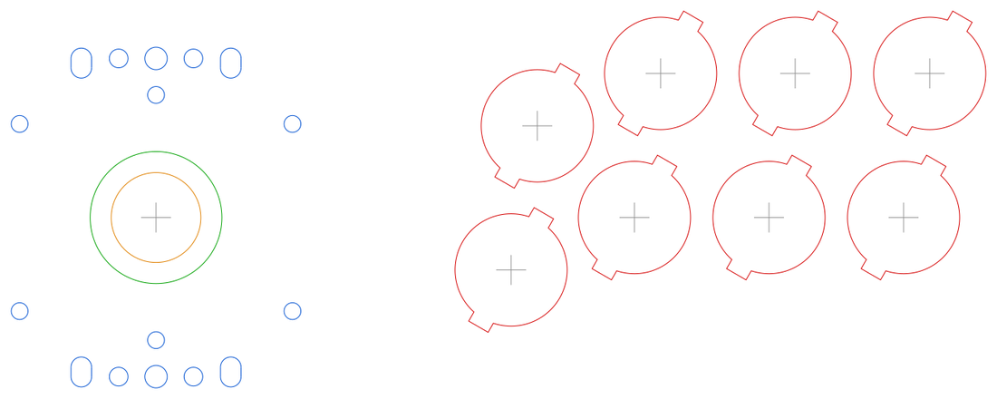
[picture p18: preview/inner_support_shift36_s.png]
inner_support_shift36_s
 

*Left: standard. Right: inner support, with the hole and its Sanwa OBSF ear relief merged into one profile.*

> This is a generic version of the Vewlix shifted layout. Note the top index and bottom middle finger buttons are closer together than the standard spacing and will not work with Sanwa nuts.
>
> *Slagcoin*

The same shift concept, tidied up into round numbers, with a flat 36 mm column pitch and a consistent step up and to the right from the bottom row to the top.

> Same nut clearance caution as Vewlix, for the same reason.

**8 buttons**  |  stock lever at **95 mm**  |  closest button pitch 35.7 mm at 30 mm, 28.6 mm at 24 mm  |  cut envelope 261 x 99 mm

More previews: [24 mm buttons](preview/shift36_s_24mm_buttons.png) &middot; [24 mm inner support](preview/inner_support_shift36_s_24mm_buttons.png)

| Version | 30 mm buttons | 24 mm buttons |
|---|---|---|
| Stock | [dxf](dxf/shift36_s.dxf) &middot; [svg](svg/shift36_s.svg) | [dxf](dxf/shift36_s_24mm_buttons.dxf) &middot; [svg](svg/shift36_s_24mm_buttons.svg) |
| Stock, inner support | [dxf](dxf/inner_support_shift36_s.dxf) &middot; [svg](svg/inner_support_shift36_s.svg) | [dxf](dxf/inner_support_shift36_s_24mm_buttons.dxf) &middot; [svg](svg/inner_support_shift36_s_24mm_buttons.svg) |
| 82 mm | [dxf](dxf/shift36_s_82mm_spacing.dxf) &middot; [svg](svg/shift36_s_82mm_spacing.svg) | [dxf](dxf/shift36_s_82mm_spacing_24mm_buttons.dxf) &middot; [svg](svg/shift36_s_82mm_spacing_24mm_buttons.svg) |
| 82 mm, inner support | [dxf](dxf/inner_support_shift36_s_82mm_spacing.dxf) &middot; [svg](svg/inner_support_shift36_s_82mm_spacing.svg) | [dxf](dxf/inner_support_shift36_s_82mm_spacing_24mm_buttons.dxf) &middot; [svg](svg/inner_support_shift36_s_82mm_spacing_24mm_buttons.svg) |
| 95 mm | [dxf](dxf/shift36_s_95mm_spacing.dxf) &middot; [svg](svg/shift36_s_95mm_spacing.svg) | [dxf](dxf/shift36_s_95mm_spacing_24mm_buttons.dxf) &middot; [svg](svg/shift36_s_95mm_spacing_24mm_buttons.svg) |
| 95 mm, inner support | [dxf](dxf/inner_support_shift36_s_95mm_spacing.dxf) &middot; [svg](svg/inner_support_shift36_s_95mm_spacing.svg) | [dxf](dxf/inner_support_shift36_s_95mm_spacing_24mm_buttons.dxf) &middot; [svg](svg/inner_support_shift36_s_95mm_spacing_24mm_buttons.svg) |

---

### Hori transitioning

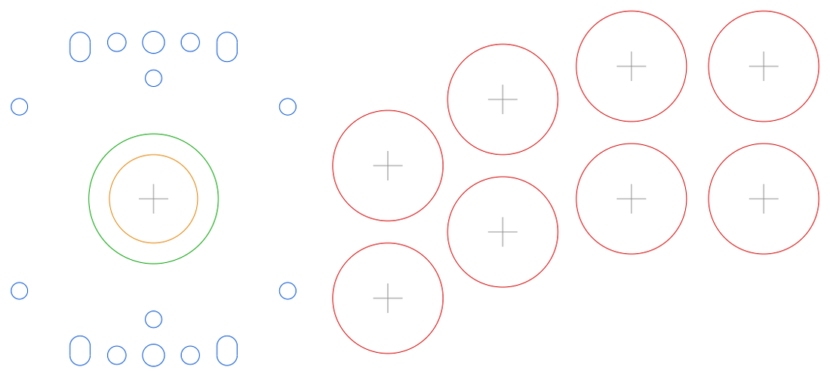
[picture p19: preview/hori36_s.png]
hori36_s
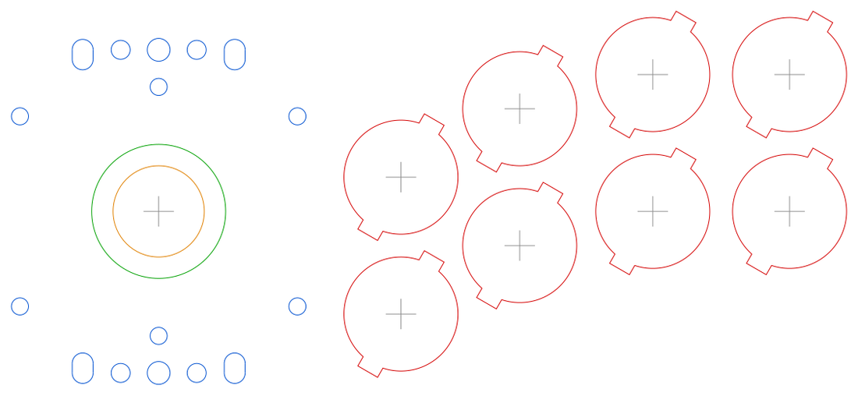
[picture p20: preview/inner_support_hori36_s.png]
inner_support_hori36_s
 

*Left: standard. Right: inner support, with the hole and its Sanwa OBSF ear relief merged into one profile.*

> This is a transitioning layout used by Hori in some of their joysticks. Some dots are added to show where to put the joystick if only using the right six buttons. In most of their joysticks, they use the standard Japanese arcade layout.
>
> *Slagcoin*

Starts stepped on the left and flattens out into a straight pair of rows on the right. A nice compromise if a full slant feels like too much but a flat grid feels too square.

> **About that 63.75 mm.** It looks like a typo but it is not. Slagcoin drew the stick where it belongs if you only use the right six buttons, which puts it exactly 95 mm from the second column. The `_82mm` and `_95mm` files measure from the first column like everything else in this repository.

**8 buttons**  |  stock lever at **63.75 mm**  |  closest button pitch 36.0 mm at 30 mm, 28.8 mm at 24 mm  |  cut envelope 220 x 96 mm

More previews: [24 mm buttons](preview/hori36_s_24mm_buttons.png) &middot; [24 mm inner support](preview/inner_support_hori36_s_24mm_buttons.png)

| Version | 30 mm buttons | 24 mm buttons |
|---|---|---|
| Stock | [dxf](dxf/hori36_s.dxf) &middot; [svg](svg/hori36_s.svg) | [dxf](dxf/hori36_s_24mm_buttons.dxf) &middot; [svg](svg/hori36_s_24mm_buttons.svg) |
| Stock, inner support | [dxf](dxf/inner_support_hori36_s.dxf) &middot; [svg](svg/inner_support_hori36_s.svg) | [dxf](dxf/inner_support_hori36_s_24mm_buttons.dxf) &middot; [svg](svg/inner_support_hori36_s_24mm_buttons.svg) |
| 82 mm | [dxf](dxf/hori36_s_82mm_spacing.dxf) &middot; [svg](svg/hori36_s_82mm_spacing.svg) | [dxf](dxf/hori36_s_82mm_spacing_24mm_buttons.dxf) &middot; [svg](svg/hori36_s_82mm_spacing_24mm_buttons.svg) |
| 82 mm, inner support | [dxf](dxf/inner_support_hori36_s_82mm_spacing.dxf) &middot; [svg](svg/inner_support_hori36_s_82mm_spacing.svg) | [dxf](dxf/inner_support_hori36_s_82mm_spacing_24mm_buttons.dxf) &middot; [svg](svg/inner_support_hori36_s_82mm_spacing_24mm_buttons.svg) |
| 95 mm | [dxf](dxf/hori36_s_95mm_spacing.dxf) &middot; [svg](svg/hori36_s_95mm_spacing.svg) | [dxf](dxf/hori36_s_95mm_spacing_24mm_buttons.dxf) &middot; [svg](svg/hori36_s_95mm_spacing_24mm_buttons.svg) |
| 95 mm, inner support | [dxf](dxf/inner_support_hori36_s_95mm_spacing.dxf) &middot; [svg](svg/inner_support_hori36_s_95mm_spacing.svg) | [dxf](dxf/inner_support_hori36_s_95mm_spacing_24mm_buttons.dxf) &middot; [svg](svg/inner_support_hori36_s_95mm_spacing_24mm_buttons.svg) |

### Hori transitioning, spaced rows

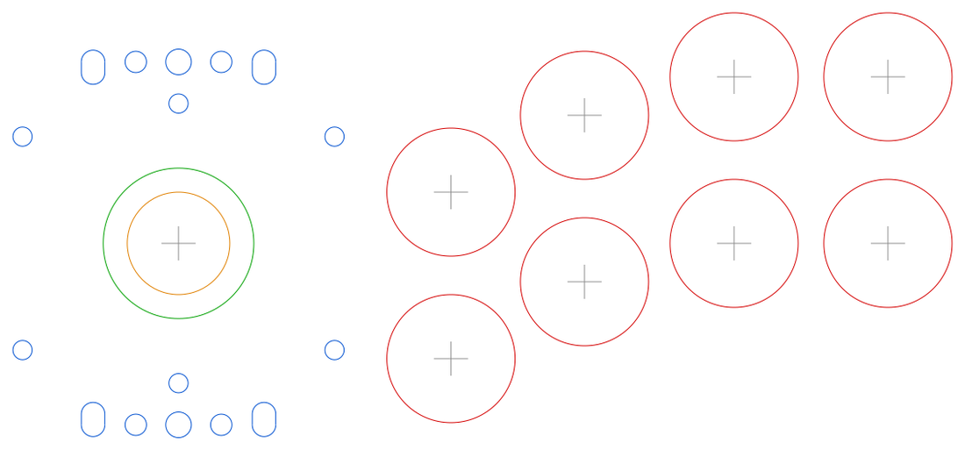
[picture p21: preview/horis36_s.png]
horis36_s
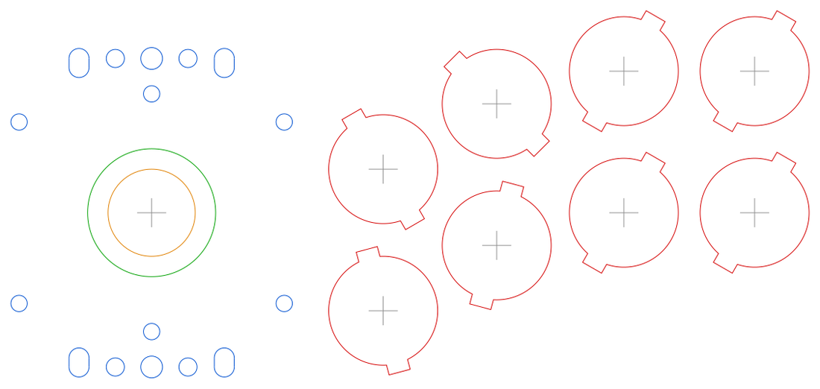
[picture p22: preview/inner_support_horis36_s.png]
inner_support_horis36_s
 

*Left: standard. Right: inner support, with the hole and its Sanwa OBSF ear relief merged into one profile.*

> Same as the previous layout, but space is added between rows.
>
> *Slagcoin*

Identical to `hori36_s` with the rows opened from 36 mm to 39 mm.

**8 buttons**  |  stock lever at **63.75 mm**  |  closest button pitch 36.0 mm at 30 mm, 28.8 mm at 24 mm  |  cut envelope 220 x 100 mm

More previews: [24 mm buttons](preview/horis36_s_24mm_buttons.png) &middot; [24 mm inner support](preview/inner_support_horis36_s_24mm_buttons.png)

| Version | 30 mm buttons | 24 mm buttons |
|---|---|---|
| Stock | [dxf](dxf/horis36_s.dxf) &middot; [svg](svg/horis36_s.svg) | [dxf](dxf/horis36_s_24mm_buttons.dxf) &middot; [svg](svg/horis36_s_24mm_buttons.svg) |
| Stock, inner support | [dxf](dxf/inner_support_horis36_s.dxf) &middot; [svg](svg/inner_support_horis36_s.svg) | [dxf](dxf/inner_support_horis36_s_24mm_buttons.dxf) &middot; [svg](svg/inner_support_horis36_s_24mm_buttons.svg) |
| 82 mm | [dxf](dxf/horis36_s_82mm_spacing.dxf) &middot; [svg](svg/horis36_s_82mm_spacing.svg) | [dxf](dxf/horis36_s_82mm_spacing_24mm_buttons.dxf) &middot; [svg](svg/horis36_s_82mm_spacing_24mm_buttons.svg) |
| 82 mm, inner support | [dxf](dxf/inner_support_horis36_s_82mm_spacing.dxf) &middot; [svg](svg/inner_support_horis36_s_82mm_spacing.svg) | [dxf](dxf/inner_support_horis36_s_82mm_spacing_24mm_buttons.dxf) &middot; [svg](svg/inner_support_horis36_s_82mm_spacing_24mm_buttons.svg) |
| 95 mm | [dxf](dxf/horis36_s_95mm_spacing.dxf) &middot; [svg](svg/horis36_s_95mm_spacing.svg) | [dxf](dxf/horis36_s_95mm_spacing_24mm_buttons.dxf) &middot; [svg](svg/horis36_s_95mm_spacing_24mm_buttons.svg) |
| 95 mm, inner support | [dxf](dxf/inner_support_horis36_s_95mm_spacing.dxf) &middot; [svg](svg/inner_support_horis36_s_95mm_spacing.svg) | [dxf](dxf/inner_support_horis36_s_95mm_spacing_24mm_buttons.dxf) &middot; [svg](svg/inner_support_horis36_s_95mm_spacing_24mm_buttons.svg) |

---

### Clustered arcade

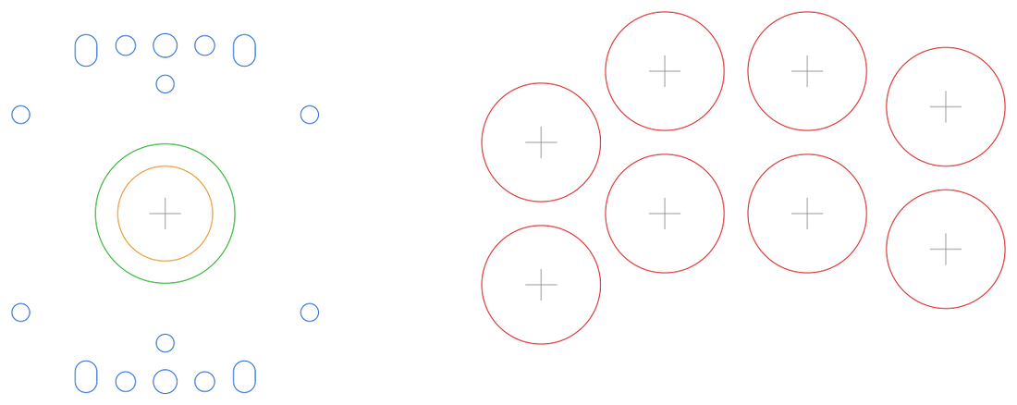
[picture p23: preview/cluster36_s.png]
cluster36_s
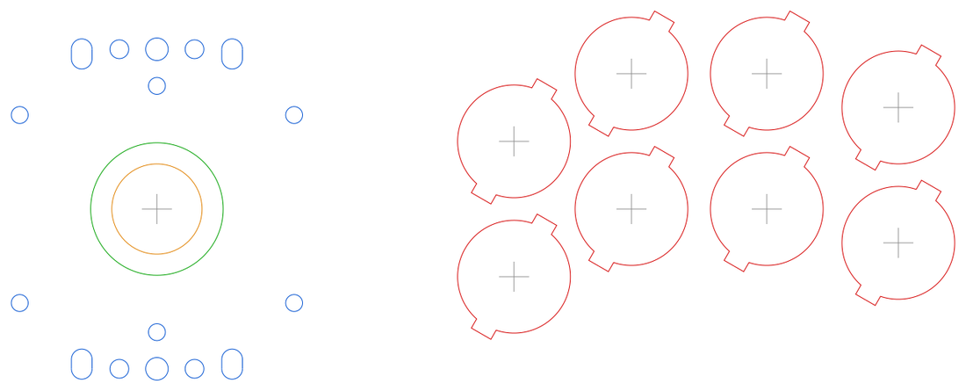
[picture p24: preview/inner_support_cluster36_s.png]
inner_support_cluster36_s
 

*Left: standard. Right: inner support, with the hole and its Sanwa OBSF ear relief merged into one profile.*

> This layout uses the standard Japanese arcade design, but the proportions are set so the buttons fit together more evenly and closely. The buttons form equilateral triangles and a square.
>
> *Slagcoin*

The Japanese arcade feel, but rationalised. The geometry is built out of equilateral triangles, so neighboring buttons all sit a consistent 36 mm apart in every direction. This is the tightest and most packed of the slanted family.

**8 buttons**  |  stock lever at **95 mm**  |  closest button pitch 36.0 mm at 30 mm, 28.8 mm at 24 mm  |  cut envelope 251 x 96 mm

More previews: [24 mm buttons](preview/cluster36_s_24mm_buttons.png) &middot; [24 mm inner support](preview/inner_support_cluster36_s_24mm_buttons.png)

| Version | 30 mm buttons | 24 mm buttons |
|---|---|---|
| Stock | [dxf](dxf/cluster36_s.dxf) &middot; [svg](svg/cluster36_s.svg) | [dxf](dxf/cluster36_s_24mm_buttons.dxf) &middot; [svg](svg/cluster36_s_24mm_buttons.svg) |
| Stock, inner support | [dxf](dxf/inner_support_cluster36_s.dxf) &middot; [svg](svg/inner_support_cluster36_s.svg) | [dxf](dxf/inner_support_cluster36_s_24mm_buttons.dxf) &middot; [svg](svg/inner_support_cluster36_s_24mm_buttons.svg) |
| 82 mm | [dxf](dxf/cluster36_s_82mm_spacing.dxf) &middot; [svg](svg/cluster36_s_82mm_spacing.svg) | [dxf](dxf/cluster36_s_82mm_spacing_24mm_buttons.dxf) &middot; [svg](svg/cluster36_s_82mm_spacing_24mm_buttons.svg) |
| 82 mm, inner support | [dxf](dxf/inner_support_cluster36_s_82mm_spacing.dxf) &middot; [svg](svg/inner_support_cluster36_s_82mm_spacing.svg) | [dxf](dxf/inner_support_cluster36_s_82mm_spacing_24mm_buttons.dxf) &middot; [svg](svg/inner_support_cluster36_s_82mm_spacing_24mm_buttons.svg) |
| 95 mm | [dxf](dxf/cluster36_s_95mm_spacing.dxf) &middot; [svg](svg/cluster36_s_95mm_spacing.svg) | [dxf](dxf/cluster36_s_95mm_spacing_24mm_buttons.dxf) &middot; [svg](svg/cluster36_s_95mm_spacing_24mm_buttons.svg) |
| 95 mm, inner support | [dxf](dxf/inner_support_cluster36_s_95mm_spacing.dxf) &middot; [svg](svg/inner_support_cluster36_s_95mm_spacing.svg) | [dxf](dxf/inner_support_cluster36_s_95mm_spacing_24mm_buttons.dxf) &middot; [svg](svg/inner_support_cluster36_s_95mm_spacing_24mm_buttons.svg) |

### Clustered arcade, spaced rows

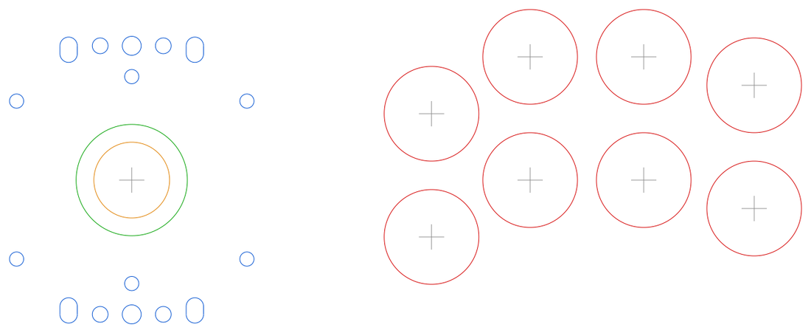
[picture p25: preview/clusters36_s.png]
clusters36_s
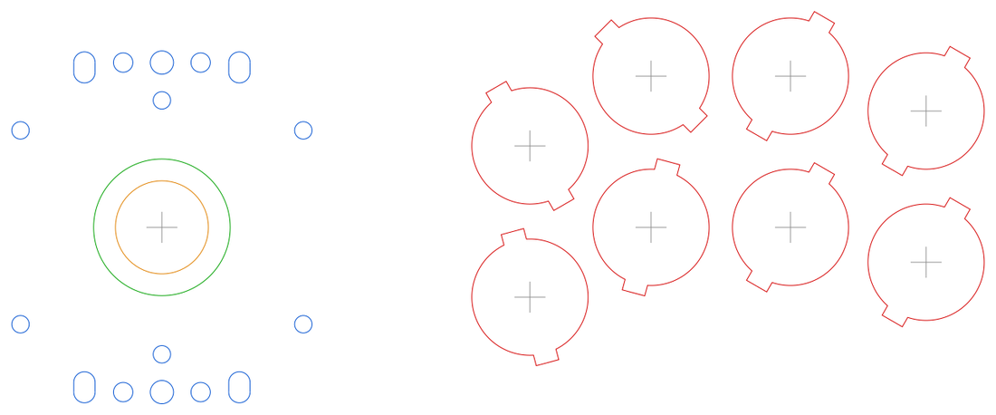
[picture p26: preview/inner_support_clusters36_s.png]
inner_support_clusters36_s
 

*Left: standard. Right: inner support, with the hole and its Sanwa OBSF ear relief merged into one profile.*

> Same as the previous layout, but space is added between the rows.
>
> *Slagcoin*

Identical to `cluster36_s` with the rows opened from 36 mm to 39 mm.

**8 buttons**  |  stock lever at **95 mm**  |  closest button pitch 36.0 mm at 30 mm, 28.8 mm at 24 mm  |  cut envelope 251 x 100 mm

More previews: [24 mm buttons](preview/clusters36_s_24mm_buttons.png) &middot; [24 mm inner support](preview/inner_support_clusters36_s_24mm_buttons.png)

| Version | 30 mm buttons | 24 mm buttons |
|---|---|---|
| Stock | [dxf](dxf/clusters36_s.dxf) &middot; [svg](svg/clusters36_s.svg) | [dxf](dxf/clusters36_s_24mm_buttons.dxf) &middot; [svg](svg/clusters36_s_24mm_buttons.svg) |
| Stock, inner support | [dxf](dxf/inner_support_clusters36_s.dxf) &middot; [svg](svg/inner_support_clusters36_s.svg) | [dxf](dxf/inner_support_clusters36_s_24mm_buttons.dxf) &middot; [svg](svg/inner_support_clusters36_s_24mm_buttons.svg) |
| 82 mm | [dxf](dxf/clusters36_s_82mm_spacing.dxf) &middot; [svg](svg/clusters36_s_82mm_spacing.svg) | [dxf](dxf/clusters36_s_82mm_spacing_24mm_buttons.dxf) &middot; [svg](svg/clusters36_s_82mm_spacing_24mm_buttons.svg) |
| 82 mm, inner support | [dxf](dxf/inner_support_clusters36_s_82mm_spacing.dxf) &middot; [svg](svg/inner_support_clusters36_s_82mm_spacing.svg) | [dxf](dxf/inner_support_clusters36_s_82mm_spacing_24mm_buttons.dxf) &middot; [svg](svg/inner_support_clusters36_s_82mm_spacing_24mm_buttons.svg) |
| 95 mm | [dxf](dxf/clusters36_s_95mm_spacing.dxf) &middot; [svg](svg/clusters36_s_95mm_spacing.svg) | [dxf](dxf/clusters36_s_95mm_spacing_24mm_buttons.dxf) &middot; [svg](svg/clusters36_s_95mm_spacing_24mm_buttons.svg) |
| 95 mm, inner support | [dxf](dxf/inner_support_clusters36_s_95mm_spacing.dxf) &middot; [svg](svg/inner_support_clusters36_s_95mm_spacing.svg) | [dxf](dxf/inner_support_clusters36_s_95mm_spacing_24mm_buttons.dxf) &middot; [svg](svg/inner_support_clusters36_s_95mm_spacing_24mm_buttons.svg) |

---

### Direct slant

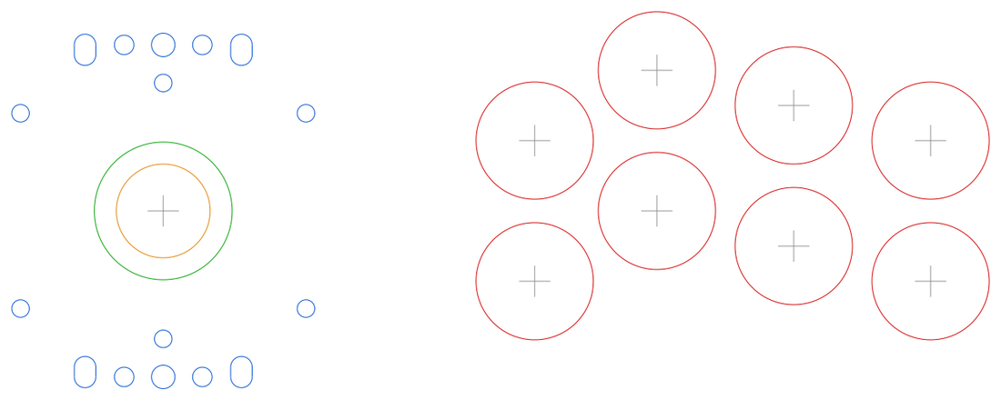
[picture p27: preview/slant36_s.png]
slant36_s
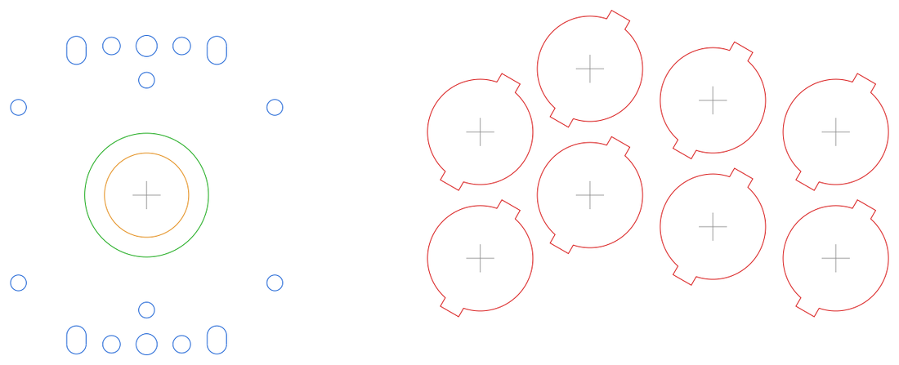
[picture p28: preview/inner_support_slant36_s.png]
inner_support_slant36_s
 

*Left: standard. Right: inner support, with the hole and its Sanwa OBSF ear relief merged into one profile.*

> The layout does a direct build of the slanted layout. It uses half-steps like those in the Hori layout.
>
> *Slagcoin*

A clean, deliberate arch. It climbs to the middle finger column and then comes back down in half steps for the ring and pinky, which follows where your fingertips actually land. The half steps keep it from feeling as steep as the incline layouts.

**8 buttons**  |  stock lever at **95 mm**  |  closest button pitch 36.0 mm at 30 mm, 28.8 mm at 24 mm  |  cut envelope 250 x 96 mm

More previews: [24 mm buttons](preview/slant36_s_24mm_buttons.png) &middot; [24 mm inner support](preview/inner_support_slant36_s_24mm_buttons.png)

| Version | 30 mm buttons | 24 mm buttons |
|---|---|---|
| Stock | [dxf](dxf/slant36_s.dxf) &middot; [svg](svg/slant36_s.svg) | [dxf](dxf/slant36_s_24mm_buttons.dxf) &middot; [svg](svg/slant36_s_24mm_buttons.svg) |
| Stock, inner support | [dxf](dxf/inner_support_slant36_s.dxf) &middot; [svg](svg/inner_support_slant36_s.svg) | [dxf](dxf/inner_support_slant36_s_24mm_buttons.dxf) &middot; [svg](svg/inner_support_slant36_s_24mm_buttons.svg) |
| 82 mm | [dxf](dxf/slant36_s_82mm_spacing.dxf) &middot; [svg](svg/slant36_s_82mm_spacing.svg) | [dxf](dxf/slant36_s_82mm_spacing_24mm_buttons.dxf) &middot; [svg](svg/slant36_s_82mm_spacing_24mm_buttons.svg) |
| 82 mm, inner support | [dxf](dxf/inner_support_slant36_s_82mm_spacing.dxf) &middot; [svg](svg/inner_support_slant36_s_82mm_spacing.svg) | [dxf](dxf/inner_support_slant36_s_82mm_spacing_24mm_buttons.dxf) &middot; [svg](svg/inner_support_slant36_s_82mm_spacing_24mm_buttons.svg) |
| 95 mm | [dxf](dxf/slant36_s_95mm_spacing.dxf) &middot; [svg](svg/slant36_s_95mm_spacing.svg) | [dxf](dxf/slant36_s_95mm_spacing_24mm_buttons.dxf) &middot; [svg](svg/slant36_s_95mm_spacing_24mm_buttons.svg) |
| 95 mm, inner support | [dxf](dxf/inner_support_slant36_s_95mm_spacing.dxf) &middot; [svg](svg/inner_support_slant36_s_95mm_spacing.svg) | [dxf](dxf/inner_support_slant36_s_95mm_spacing_24mm_buttons.dxf) &middot; [svg](svg/inner_support_slant36_s_95mm_spacing_24mm_buttons.svg) |

### Direct slant, spaced rows

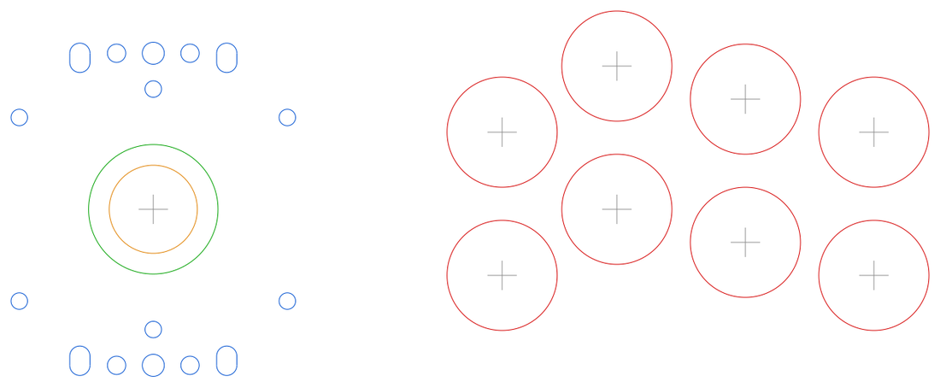
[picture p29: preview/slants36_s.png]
slants36_s
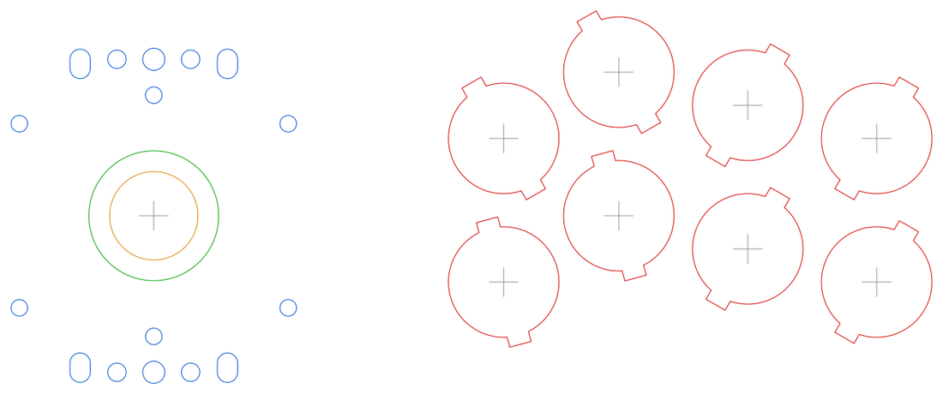
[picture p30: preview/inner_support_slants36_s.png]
inner_support_slants36_s
 

*Left: standard. Right: inner support, with the hole and its Sanwa OBSF ear relief merged into one profile.*

> Same as the previous layout, but space is added between rows.
>
> *Slagcoin*

Identical to `slant36_s` with the rows opened from 36 mm to 39 mm.

**8 buttons**  |  stock lever at **95 mm**  |  closest button pitch 36.1 mm at 30 mm, 28.9 mm at 24 mm  |  cut envelope 250 x 100 mm

More previews: [24 mm buttons](preview/slants36_s_24mm_buttons.png) &middot; [24 mm inner support](preview/inner_support_slants36_s_24mm_buttons.png)

| Version | 30 mm buttons | 24 mm buttons |
|---|---|---|
| Stock | [dxf](dxf/slants36_s.dxf) &middot; [svg](svg/slants36_s.svg) | [dxf](dxf/slants36_s_24mm_buttons.dxf) &middot; [svg](svg/slants36_s_24mm_buttons.svg) |
| Stock, inner support | [dxf](dxf/inner_support_slants36_s.dxf) &middot; [svg](svg/inner_support_slants36_s.svg) | [dxf](dxf/inner_support_slants36_s_24mm_buttons.dxf) &middot; [svg](svg/inner_support_slants36_s_24mm_buttons.svg) |
| 82 mm | [dxf](dxf/slants36_s_82mm_spacing.dxf) &middot; [svg](svg/slants36_s_82mm_spacing.svg) | [dxf](dxf/slants36_s_82mm_spacing_24mm_buttons.dxf) &middot; [svg](svg/slants36_s_82mm_spacing_24mm_buttons.svg) |
| 82 mm, inner support | [dxf](dxf/inner_support_slants36_s_82mm_spacing.dxf) &middot; [svg](svg/inner_support_slants36_s_82mm_spacing.svg) | [dxf](dxf/inner_support_slants36_s_82mm_spacing_24mm_buttons.dxf) &middot; [svg](svg/inner_support_slants36_s_82mm_spacing_24mm_buttons.svg) |
| 95 mm | [dxf](dxf/slants36_s_95mm_spacing.dxf) &middot; [svg](svg/slants36_s_95mm_spacing.svg) | [dxf](dxf/slants36_s_95mm_spacing_24mm_buttons.dxf) &middot; [svg](svg/slants36_s_95mm_spacing_24mm_buttons.svg) |
| 95 mm, inner support | [dxf](dxf/inner_support_slants36_s_95mm_spacing.dxf) &middot; [svg](svg/inner_support_slants36_s_95mm_spacing.svg) | [dxf](dxf/inner_support_slants36_s_95mm_spacing_24mm_buttons.dxf) &middot; [svg](svg/inner_support_slants36_s_95mm_spacing_24mm_buttons.svg) |

---

### Moderate / hybrid

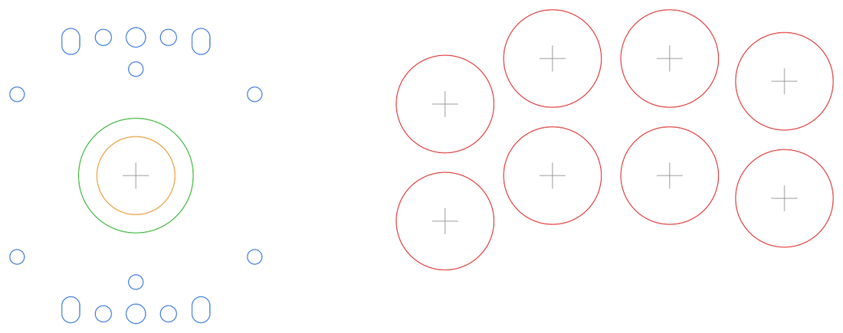
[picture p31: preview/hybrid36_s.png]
hybrid36_s
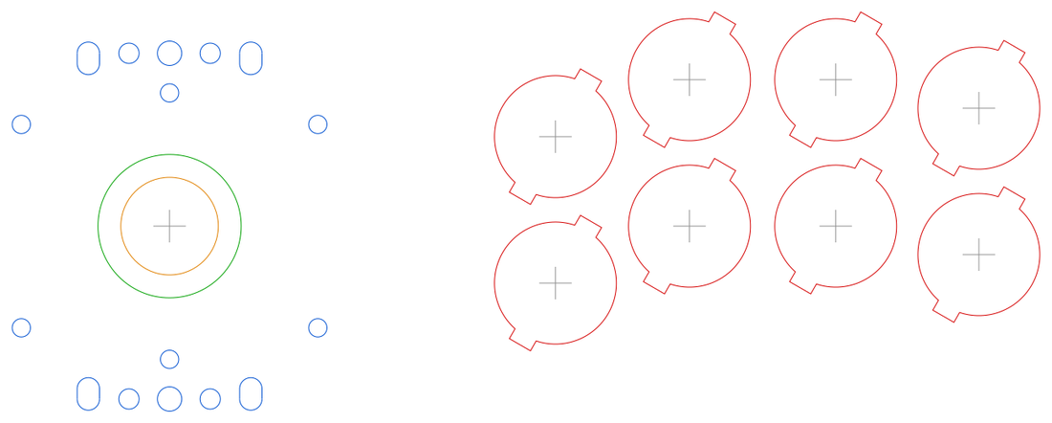
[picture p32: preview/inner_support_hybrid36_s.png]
inner_support_hybrid36_s
 

*Left: standard. Right: inner support, with the hole and its Sanwa OBSF ear relief merged into one profile.*

> This layout is somewhat of a mix between the standard player 1 and player 2 layouts. The curvature is not as defined.
>
> *Slagcoin*

Halfway between the slanted P1 and the flat P2. A gentle step up on the index column, flat through the middle, and a small drop for the pinky.

**A good default if you cannot decide.** It is forgiving of a lot of hand shapes without committing hard to a slant.

**8 buttons**  |  stock lever at **95 mm**  |  closest button pitch 35.8 mm at 30 mm, 28.7 mm at 24 mm  |  cut envelope 253 x 96 mm

More previews: [24 mm buttons](preview/hybrid36_s_24mm_buttons.png) &middot; [24 mm inner support](preview/inner_support_hybrid36_s_24mm_buttons.png)

| Version | 30 mm buttons | 24 mm buttons |
|---|---|---|
| Stock | [dxf](dxf/hybrid36_s.dxf) &middot; [svg](svg/hybrid36_s.svg) | [dxf](dxf/hybrid36_s_24mm_buttons.dxf) &middot; [svg](svg/hybrid36_s_24mm_buttons.svg) |
| Stock, inner support | [dxf](dxf/inner_support_hybrid36_s.dxf) &middot; [svg](svg/inner_support_hybrid36_s.svg) | [dxf](dxf/inner_support_hybrid36_s_24mm_buttons.dxf) &middot; [svg](svg/inner_support_hybrid36_s_24mm_buttons.svg) |
| 82 mm | [dxf](dxf/hybrid36_s_82mm_spacing.dxf) &middot; [svg](svg/hybrid36_s_82mm_spacing.svg) | [dxf](dxf/hybrid36_s_82mm_spacing_24mm_buttons.dxf) &middot; [svg](svg/hybrid36_s_82mm_spacing_24mm_buttons.svg) |
| 82 mm, inner support | [dxf](dxf/inner_support_hybrid36_s_82mm_spacing.dxf) &middot; [svg](svg/inner_support_hybrid36_s_82mm_spacing.svg) | [dxf](dxf/inner_support_hybrid36_s_82mm_spacing_24mm_buttons.dxf) &middot; [svg](svg/inner_support_hybrid36_s_82mm_spacing_24mm_buttons.svg) |
| 95 mm | [dxf](dxf/hybrid36_s_95mm_spacing.dxf) &middot; [svg](svg/hybrid36_s_95mm_spacing.svg) | [dxf](dxf/hybrid36_s_95mm_spacing_24mm_buttons.dxf) &middot; [svg](svg/hybrid36_s_95mm_spacing_24mm_buttons.svg) |
| 95 mm, inner support | [dxf](dxf/inner_support_hybrid36_s_95mm_spacing.dxf) &middot; [svg](svg/inner_support_hybrid36_s_95mm_spacing.svg) | [dxf](dxf/inner_support_hybrid36_s_95mm_spacing_24mm_buttons.dxf) &middot; [svg](svg/inner_support_hybrid36_s_95mm_spacing_24mm_buttons.svg) |

### Moderate / hybrid, spaced rows

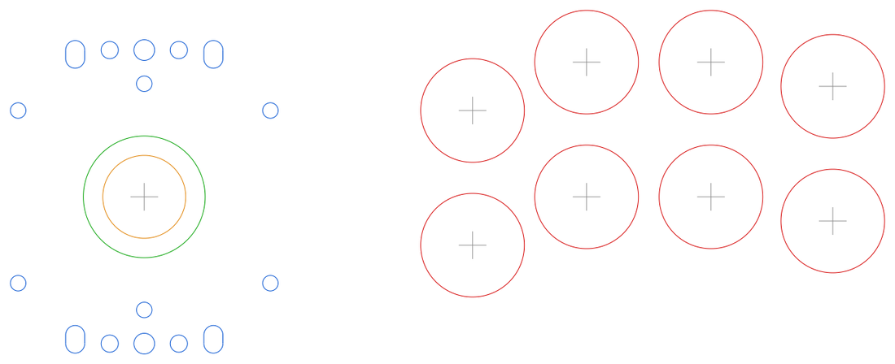
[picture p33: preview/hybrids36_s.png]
hybrids36_s
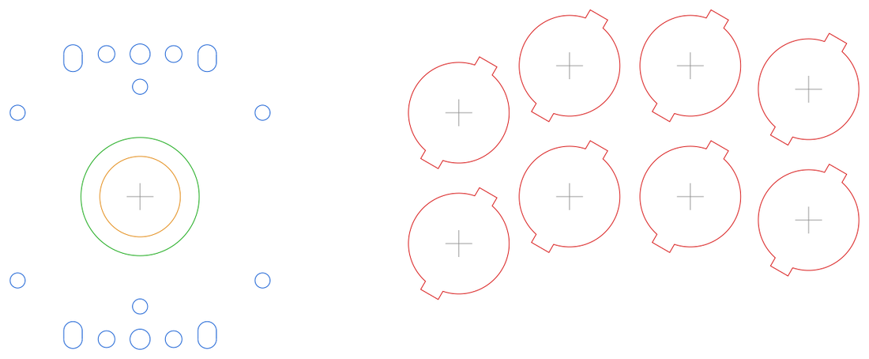
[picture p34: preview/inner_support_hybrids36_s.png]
inner_support_hybrids36_s
 

*Left: standard. Right: inner support, with the hole and its Sanwa OBSF ear relief merged into one profile.*

> Same as the previous layout, but space is added between rows.
>
> *Slagcoin*

Identical to `hybrid36_s` with the rows opened from 36 mm to 39 mm.

**8 buttons**  |  stock lever at **95 mm**  |  closest button pitch 35.8 mm at 30 mm, 28.7 mm at 24 mm  |  cut envelope 253 x 100 mm

More previews: [24 mm buttons](preview/hybrids36_s_24mm_buttons.png) &middot; [24 mm inner support](preview/inner_support_hybrids36_s_24mm_buttons.png)

| Version | 30 mm buttons | 24 mm buttons |
|---|---|---|
| Stock | [dxf](dxf/hybrids36_s.dxf) &middot; [svg](svg/hybrids36_s.svg) | [dxf](dxf/hybrids36_s_24mm_buttons.dxf) &middot; [svg](svg/hybrids36_s_24mm_buttons.svg) |
| Stock, inner support | [dxf](dxf/inner_support_hybrids36_s.dxf) &middot; [svg](svg/inner_support_hybrids36_s.svg) | [dxf](dxf/inner_support_hybrids36_s_24mm_buttons.dxf) &middot; [svg](svg/inner_support_hybrids36_s_24mm_buttons.svg) |
| 82 mm | [dxf](dxf/hybrids36_s_82mm_spacing.dxf) &middot; [svg](svg/hybrids36_s_82mm_spacing.svg) | [dxf](dxf/hybrids36_s_82mm_spacing_24mm_buttons.dxf) &middot; [svg](svg/hybrids36_s_82mm_spacing_24mm_buttons.svg) |
| 82 mm, inner support | [dxf](dxf/inner_support_hybrids36_s_82mm_spacing.dxf) &middot; [svg](svg/inner_support_hybrids36_s_82mm_spacing.svg) | [dxf](dxf/inner_support_hybrids36_s_82mm_spacing_24mm_buttons.dxf) &middot; [svg](svg/inner_support_hybrids36_s_82mm_spacing_24mm_buttons.svg) |
| 95 mm | [dxf](dxf/hybrids36_s_95mm_spacing.dxf) &middot; [svg](svg/hybrids36_s_95mm_spacing.svg) | [dxf](dxf/hybrids36_s_95mm_spacing_24mm_buttons.dxf) &middot; [svg](svg/hybrids36_s_95mm_spacing_24mm_buttons.svg) |
| 95 mm, inner support | [dxf](dxf/inner_support_hybrids36_s_95mm_spacing.dxf) &middot; [svg](svg/inner_support_hybrids36_s_95mm_spacing.svg) | [dxf](dxf/inner_support_hybrids36_s_95mm_spacing_24mm_buttons.dxf) &middot; [svg](svg/inner_support_hybrids36_s_95mm_spacing_24mm_buttons.svg) |

---

### Straight incline

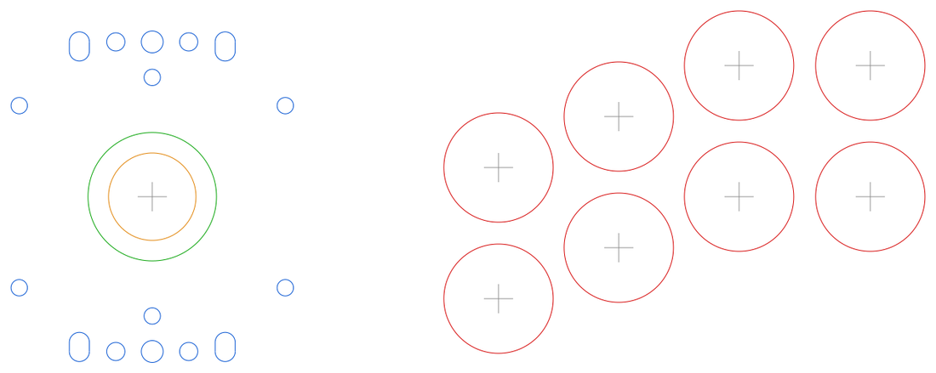
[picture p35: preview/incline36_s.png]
incline36_s
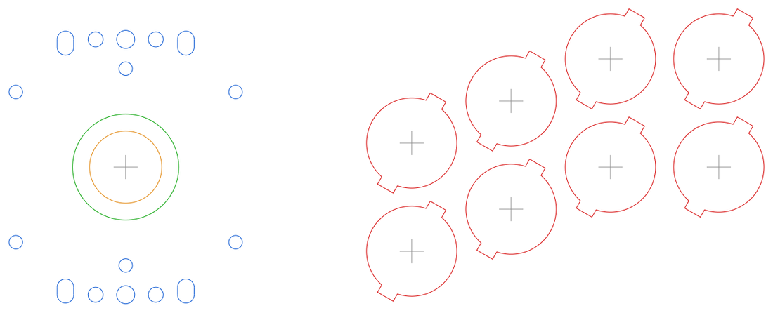
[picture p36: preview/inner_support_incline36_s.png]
inner_support_incline36_s
 

*Left: standard. Right: inner support, with the hole and its Sanwa OBSF ear relief merged into one profile.*

> This layout inclines straight until the pinky buttons.
>
> *Slagcoin*

The most aggressive slant in the set. It climbs steadily column by column and then levels off for the pinky. If you play with a strongly angled hand, or your ring and pinky sit noticeably lower than your index finger, this is the one worth printing and feeling before anything else.

**8 buttons**  |  stock lever at **95 mm**  |  closest button pitch 35.8 mm at 30 mm, 28.7 mm at 24 mm  |  cut envelope 251 x 96 mm

More previews: [24 mm buttons](preview/incline36_s_24mm_buttons.png) &middot; [24 mm inner support](preview/inner_support_incline36_s_24mm_buttons.png)

| Version | 30 mm buttons | 24 mm buttons |
|---|---|---|
| Stock | [dxf](dxf/incline36_s.dxf) &middot; [svg](svg/incline36_s.svg) | [dxf](dxf/incline36_s_24mm_buttons.dxf) &middot; [svg](svg/incline36_s_24mm_buttons.svg) |
| Stock, inner support | [dxf](dxf/inner_support_incline36_s.dxf) &middot; [svg](svg/inner_support_incline36_s.svg) | [dxf](dxf/inner_support_incline36_s_24mm_buttons.dxf) &middot; [svg](svg/inner_support_incline36_s_24mm_buttons.svg) |
| 82 mm | [dxf](dxf/incline36_s_82mm_spacing.dxf) &middot; [svg](svg/incline36_s_82mm_spacing.svg) | [dxf](dxf/incline36_s_82mm_spacing_24mm_buttons.dxf) &middot; [svg](svg/incline36_s_82mm_spacing_24mm_buttons.svg) |
| 82 mm, inner support | [dxf](dxf/inner_support_incline36_s_82mm_spacing.dxf) &middot; [svg](svg/inner_support_incline36_s_82mm_spacing.svg) | [dxf](dxf/inner_support_incline36_s_82mm_spacing_24mm_buttons.dxf) &middot; [svg](svg/inner_support_incline36_s_82mm_spacing_24mm_buttons.svg) |
| 95 mm | [dxf](dxf/incline36_s_95mm_spacing.dxf) &middot; [svg](svg/incline36_s_95mm_spacing.svg) | [dxf](dxf/incline36_s_95mm_spacing_24mm_buttons.dxf) &middot; [svg](svg/incline36_s_95mm_spacing_24mm_buttons.svg) |
| 95 mm, inner support | [dxf](dxf/inner_support_incline36_s_95mm_spacing.dxf) &middot; [svg](svg/inner_support_incline36_s_95mm_spacing.svg) | [dxf](dxf/inner_support_incline36_s_95mm_spacing_24mm_buttons.dxf) &middot; [svg](svg/inner_support_incline36_s_95mm_spacing_24mm_buttons.svg) |

### Straight incline, spaced rows

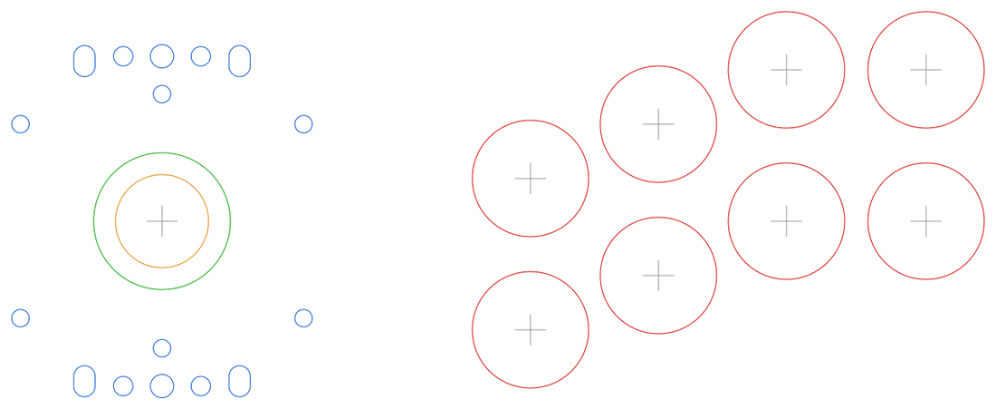
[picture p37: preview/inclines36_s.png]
inclines36_s
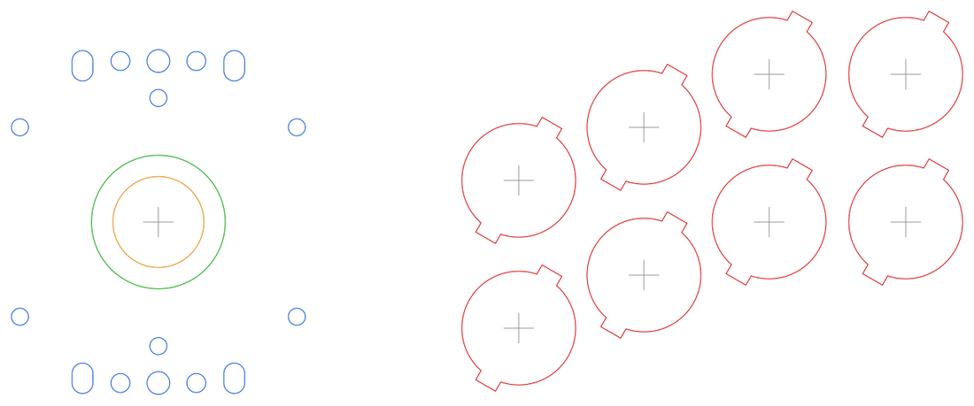
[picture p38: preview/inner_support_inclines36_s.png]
inner_support_inclines36_s
 

*Left: standard. Right: inner support, with the hole and its Sanwa OBSF ear relief merged into one profile.*

> Same as the previous layout, but space is added between rows.
>
> *Slagcoin*

Identical to `incline36_s` with the rows opened from 36 mm to 39 mm.

**8 buttons**  |  stock lever at **95 mm**  |  closest button pitch 35.8 mm at 30 mm, 28.7 mm at 24 mm  |  cut envelope 251 x 100 mm

More previews: [24 mm buttons](preview/inclines36_s_24mm_buttons.png) &middot; [24 mm inner support](preview/inner_support_inclines36_s_24mm_buttons.png)

| Version | 30 mm buttons | 24 mm buttons |
|---|---|---|
| Stock | [dxf](dxf/inclines36_s.dxf) &middot; [svg](svg/inclines36_s.svg) | [dxf](dxf/inclines36_s_24mm_buttons.dxf) &middot; [svg](svg/inclines36_s_24mm_buttons.svg) |
| Stock, inner support | [dxf](dxf/inner_support_inclines36_s.dxf) &middot; [svg](svg/inner_support_inclines36_s.svg) | [dxf](dxf/inner_support_inclines36_s_24mm_buttons.dxf) &middot; [svg](svg/inner_support_inclines36_s_24mm_buttons.svg) |
| 82 mm | [dxf](dxf/inclines36_s_82mm_spacing.dxf) &middot; [svg](svg/inclines36_s_82mm_spacing.svg) | [dxf](dxf/inclines36_s_82mm_spacing_24mm_buttons.dxf) &middot; [svg](svg/inclines36_s_82mm_spacing_24mm_buttons.svg) |
| 82 mm, inner support | [dxf](dxf/inner_support_inclines36_s_82mm_spacing.dxf) &middot; [svg](svg/inner_support_inclines36_s_82mm_spacing.svg) | [dxf](dxf/inner_support_inclines36_s_82mm_spacing_24mm_buttons.dxf) &middot; [svg](svg/inner_support_inclines36_s_82mm_spacing_24mm_buttons.svg) |
| 95 mm | [dxf](dxf/inclines36_s_95mm_spacing.dxf) &middot; [svg](svg/inclines36_s_95mm_spacing.svg) | [dxf](dxf/inclines36_s_95mm_spacing_24mm_buttons.dxf) &middot; [svg](svg/inclines36_s_95mm_spacing_24mm_buttons.svg) |
| 95 mm, inner support | [dxf](dxf/inner_support_inclines36_s_95mm_spacing.dxf) &middot; [svg](svg/inner_support_inclines36_s_95mm_spacing.svg) | [dxf](dxf/inner_support_inclines36_s_95mm_spacing_24mm_buttons.dxf) &middot; [svg](svg/inner_support_inclines36_s_95mm_spacing_24mm_buttons.svg) |

---

**Grids and squares.** Slagcoin is openly not a fan of these, but they are historically important and some people genuinely like them.

### Square grid

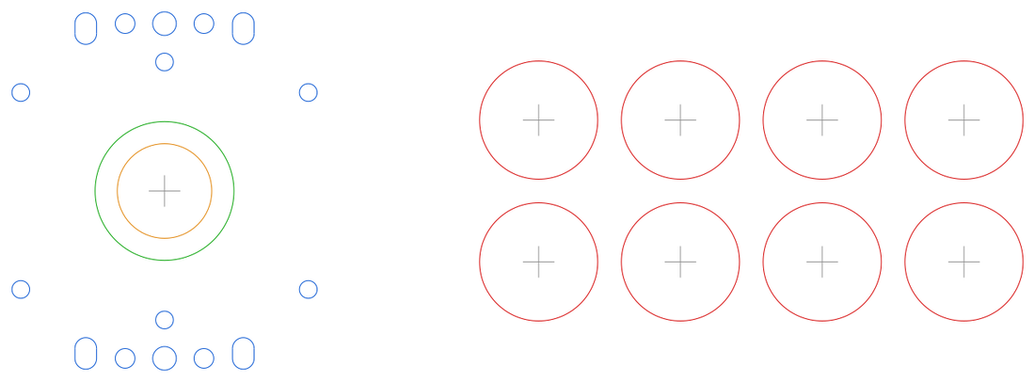
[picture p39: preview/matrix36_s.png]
matrix36_s
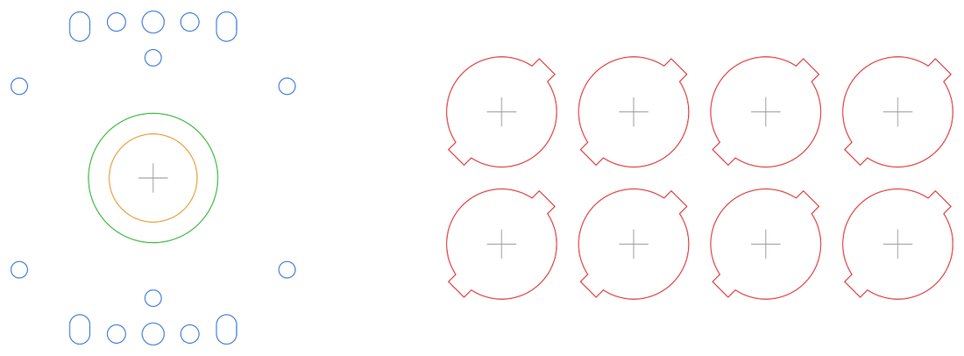
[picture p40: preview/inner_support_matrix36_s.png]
inner_support_matrix36_s
 

*Left: standard. Right: inner support, with the hole and its Sanwa OBSF ear relief merged into one profile.*

> This is a clustered grid layout. It has more of an appropriate spacing, but the squareness still does not suit the human hand very well. Additional dots are there for making a Neo Geo layout which is more appropriate for the human hand.
>
> *Slagcoin*

A perfectly square 4 by 2 grid on a 36 mm pitch. Dead simple to drill, dead simple to explain, and the usual starting point for a Neo Geo arrangement.

**8 buttons**  |  stock lever at **95 mm**  |  closest button pitch 36.0 mm at 30 mm, 28.8 mm at 24 mm  |  cut envelope 257 x 91 mm

More previews: [24 mm buttons](preview/matrix36_s_24mm_buttons.png) &middot; [24 mm inner support](preview/inner_support_matrix36_s_24mm_buttons.png)

| Version | 30 mm buttons | 24 mm buttons |
|---|---|---|
| Stock | [dxf](dxf/matrix36_s.dxf) &middot; [svg](svg/matrix36_s.svg) | [dxf](dxf/matrix36_s_24mm_buttons.dxf) &middot; [svg](svg/matrix36_s_24mm_buttons.svg) |
| Stock, inner support | [dxf](dxf/inner_support_matrix36_s.dxf) &middot; [svg](svg/inner_support_matrix36_s.svg) | [dxf](dxf/inner_support_matrix36_s_24mm_buttons.dxf) &middot; [svg](svg/inner_support_matrix36_s_24mm_buttons.svg) |
| 82 mm | [dxf](dxf/matrix36_s_82mm_spacing.dxf) &middot; [svg](svg/matrix36_s_82mm_spacing.svg) | [dxf](dxf/matrix36_s_82mm_spacing_24mm_buttons.dxf) &middot; [svg](svg/matrix36_s_82mm_spacing_24mm_buttons.svg) |
| 82 mm, inner support | [dxf](dxf/inner_support_matrix36_s_82mm_spacing.dxf) &middot; [svg](svg/inner_support_matrix36_s_82mm_spacing.svg) | [dxf](dxf/inner_support_matrix36_s_82mm_spacing_24mm_buttons.dxf) &middot; [svg](svg/inner_support_matrix36_s_82mm_spacing_24mm_buttons.svg) |
| 95 mm | [dxf](dxf/matrix36_s_95mm_spacing.dxf) &middot; [svg](svg/matrix36_s_95mm_spacing.svg) | [dxf](dxf/matrix36_s_95mm_spacing_24mm_buttons.dxf) &middot; [svg](svg/matrix36_s_95mm_spacing_24mm_buttons.svg) |
| 95 mm, inner support | [dxf](dxf/inner_support_matrix36_s_95mm_spacing.dxf) &middot; [svg](svg/inner_support_matrix36_s_95mm_spacing.svg) | [dxf](dxf/inner_support_matrix36_s_95mm_spacing_24mm_buttons.dxf) &middot; [svg](svg/inner_support_matrix36_s_95mm_spacing_24mm_buttons.svg) |

### Square grid, spaced rows

matrixs36_s inner_support_matrixs36_s

*Left: standard. Right: inner support, with the hole and its Sanwa OBSF ear relief merged into one profile.*

> Same as the previous layout, but space is added between the rows.
>
> *Slagcoin*

Identical to `matrix36_s` with the rows opened from 36 mm to 39 mm.

**8 buttons**  |  stock lever at **95 mm**  |  closest button pitch 36.0 mm at 30 mm, 28.8 mm at 24 mm  |  cut envelope 257 x 91 mm

More previews: [24 mm buttons](preview/matrixs36_s_24mm_buttons.png) &middot; [24 mm inner support](preview/inner_support_matrixs36_s_24mm_buttons.png)

| Version | 30 mm buttons | 24 mm buttons |
|---|---|---|
| Stock | [dxf](dxf/matrixs36_s.dxf) &middot; [svg](svg/matrixs36_s.svg) | [dxf](dxf/matrixs36_s_24mm_buttons.dxf) &middot; [svg](svg/matrixs36_s_24mm_buttons.svg) |
| Stock, inner support | [dxf](dxf/inner_support_matrixs36_s.dxf) &middot; [svg](svg/inner_support_matrixs36_s.svg) | [dxf](dxf/inner_support_matrixs36_s_24mm_buttons.dxf) &middot; [svg](svg/inner_support_matrixs36_s_24mm_buttons.svg) |
| 82 mm | [dxf](dxf/matrixs36_s_82mm_spacing.dxf) &middot; [svg](svg/matrixs36_s_82mm_spacing.svg) | [dxf](dxf/matrixs36_s_82mm_spacing_24mm_buttons.dxf) &middot; [svg](svg/matrixs36_s_82mm_spacing_24mm_buttons.svg) |
| 82 mm, inner support | [dxf](dxf/inner_support_matrixs36_s_82mm_spacing.dxf) &middot; [svg](svg/inner_support_matrixs36_s_82mm_spacing.svg) | [dxf](dxf/inner_support_matrixs36_s_82mm_spacing_24mm_buttons.dxf) &middot; [svg](svg/inner_support_matrixs36_s_82mm_spacing_24mm_buttons.svg) |
| 95 mm | [dxf](dxf/matrixs36_s_95mm_spacing.dxf) &middot; [svg](svg/matrixs36_s_95mm_spacing.svg) | [dxf](dxf/matrixs36_s_95mm_spacing_24mm_buttons.dxf) &middot; [svg](svg/matrixs36_s_95mm_spacing_24mm_buttons.svg) |
| 95 mm, inner support | [dxf](dxf/inner_support_matrixs36_s_95mm_spacing.dxf) &middot; [svg](svg/inner_support_matrixs36_s_95mm_spacing.svg) | [dxf](dxf/inner_support_matrixs36_s_95mm_spacing_24mm_buttons.dxf) &middot; [svg](svg/inner_support_matrixs36_s_95mm_spacing_24mm_buttons.svg) |

### Capcom USA Street Fighter

american_s inner_support_american_s

*Left: standard. Right: inner support, with the hole and its Sanwa OBSF ear relief merged into one profile.*

> This is the American Street Fighter layout given by Capcom USA. It has some strange wide-spacing and does not suit the structure of the human hand. I do not advocate squared layouts like this one and others.
>
> *Slagcoin*

The classic US cab 6 button block. This is the only layout in the set that was dimensioned in inches rather than millimeters, an inch and a half between columns and an inch and three eighths between rows, so the metric numbers look odd because they are exact conversions rather than rounded values.

Slagcoin does not recommend it. It is here because it is history, and because if you are restoring an American cabinet you need it to be right.

**6 buttons**  |  stock lever at **95 mm**  |  closest button pitch 34.9 mm at 30 mm, 27.9 mm at 24 mm  |  cut envelope 225 x 91 mm

More previews: [24 mm buttons](preview/american_s_24mm_buttons.png) &middot; [24 mm inner support](preview/inner_support_american_s_24mm_buttons.png)

**Parts: Japanese** | 30 mm or 24 mm snap in buttons | GL mounting system | 24 and 35.25 mm bores, alternatives

For the hardware these cabinets actually shipped with, see [Capcom USA Street Fighter, American Parts](#capcom-usa-street-fighter-american-parts).

| Version | 30 mm buttons | 24 mm buttons |
|---|---|---|
| Stock | [dxf](dxf/american_s.dxf) &middot; [svg](svg/american_s.svg) | [dxf](dxf/american_s_24mm_buttons.dxf) &middot; [svg](svg/american_s_24mm_buttons.svg) |
| Stock, inner support | [dxf](dxf/inner_support_american_s.dxf) &middot; [svg](svg/inner_support_american_s.svg) | [dxf](dxf/inner_support_american_s_24mm_buttons.dxf) &middot; [svg](svg/inner_support_american_s_24mm_buttons.svg) |
| 82 mm | [dxf](dxf/american_s_82mm_spacing.dxf) &middot; [svg](svg/american_s_82mm_spacing.svg) | [dxf](dxf/american_s_82mm_spacing_24mm_buttons.dxf) &middot; [svg](svg/american_s_82mm_spacing_24mm_buttons.svg) |
| 82 mm, inner support | [dxf](dxf/inner_support_american_s_82mm_spacing.dxf) &middot; [svg](svg/inner_support_american_s_82mm_spacing.svg) | [dxf](dxf/inner_support_american_s_82mm_spacing_24mm_buttons.dxf) &middot; [svg](svg/inner_support_american_s_82mm_spacing_24mm_buttons.svg) |
| 95 mm | [dxf](dxf/american_s_95mm_spacing.dxf) &middot; [svg](svg/american_s_95mm_spacing.svg) | [dxf](dxf/american_s_95mm_spacing_24mm_buttons.dxf) &middot; [svg](svg/american_s_95mm_spacing_24mm_buttons.svg) |
| 95 mm, inner support | [dxf](dxf/inner_support_american_s_95mm_spacing.dxf) &middot; [svg](svg/inner_support_american_s_95mm_spacing.svg) | [dxf](dxf/inner_support_american_s_95mm_spacing_24mm_buttons.dxf) &middot; [svg](svg/inner_support_american_s_95mm_spacing_24mm_buttons.svg) |

### Capcom USA Street Fighter, American Parts

american_s_american_parts inner_support_american_s_american_parts

*Left: standard. Right: inner support, which on this layout is an identical copy. See below.*

The Capcom block cut for the hardware the cabinets actually shipped with. **Every button center is identical to [the standard file](#capcom-usa-street-fighter)**, which is the whole point: one panel drilling pattern, two sets of hardware.

**Parts: American** | 1.125 in (28.575 mm) buttons, nut mount | IL Eurojoystick 2 | 35 mm bore | 4 x 5.9 mm on 65.6 x 75.9 mm

**6 buttons** | closest pitch 34.9 mm | cut envelope 221 x 82 mm

**Two senses of the word American are in play here**, and the file names invite confusion, so it is worth stating plainly. `american_s` is American because the *layout* is: it is the arrangement Capcom USA specified. `_american_parts` is about the *hardware*. So this file is the American layout with American hardware, where the base file is the American layout with Japanese hardware, which is what most people building one of these today actually fit.

**It is the roomier of the two.** Dropping from 30 mm to 1.125 in holes on the same centers gains 1.4 mm of material: closest pair goes from 4.92 mm edge to edge up to **6.35 mm**. That matters on this layout, because the Capcom block is not generously spaced to begin with.

**The inner support file is a plain copy.** American buttons bolt in with a nut and have no snap-in retention ears, so there is nothing for a relief slot to relieve. It ships so the naming stays consistent, but its geometry is identical to the standard file, and that is intentional rather than an oversight.

**No spacing or 24 mm variants.** Those belong to the Japanese Parts side, where the button size scales. American Parts is one hole size by definition, and the lever spacing variants remain available on the standard file if you need them.

| Version | DXF | SVG |
|---|---|---|
| Standard | [`american_s_american_parts.dxf`](dxf/american_s_american_parts.dxf) | [`american_s_american_parts.svg`](svg/american_s_american_parts.svg) |
| Inner support | [`inner_support_american_s_american_parts.dxf`](dxf/inner_support_american_s_american_parts.dxf) | [`inner_support_american_s_american_parts.svg`](svg/inner_support_american_s_american_parts.svg) |

---

**Templates.** These are not layouts to cut as they are. They are grids of candidate positions on a consistent 36 mm pitch. Cut only the holes you want, or use them to design something custom. They carry the most holes of anything in the repository, so read them as a menu rather than a finished panel.

### Mesh template

mesh36_s inner_support_mesh36_s

*Left: standard. Right: inner support, with the hole and its Sanwa OBSF ear relief merged into one profile.*

> Mesh template from which various layouts can be made.
>
> *Slagcoin*

A honeycomb style offset grid. Columns alternate between three high and two high, and everything sits a consistent 36 mm from its neighbors. Almost any slanted or arched layout can be carved out of this one.

**13 buttons**  |  stock lever at **95 mm**  |  closest button pitch 36.0 mm at 30 mm, 28.8 mm at 24 mm  |  cut envelope 274 x 102 mm

More previews: [24 mm buttons](preview/mesh36_s_24mm_buttons.png) &middot; [24 mm inner support](preview/inner_support_mesh36_s_24mm_buttons.png)

| Version | 30 mm buttons | 24 mm buttons |
|---|---|---|
| Stock | [dxf](dxf/mesh36_s.dxf) &middot; [svg](svg/mesh36_s.svg) | [dxf](dxf/mesh36_s_24mm_buttons.dxf) &middot; [svg](svg/mesh36_s_24mm_buttons.svg) |
| Stock, inner support | [dxf](dxf/inner_support_mesh36_s.dxf) &middot; [svg](svg/inner_support_mesh36_s.svg) | [dxf](dxf/inner_support_mesh36_s_24mm_buttons.dxf) &middot; [svg](svg/inner_support_mesh36_s_24mm_buttons.svg) |
| 82 mm | [dxf](dxf/mesh36_s_82mm_spacing.dxf) &middot; [svg](svg/mesh36_s_82mm_spacing.svg) | [dxf](dxf/mesh36_s_82mm_spacing_24mm_buttons.dxf) &middot; [svg](svg/mesh36_s_82mm_spacing_24mm_buttons.svg) |
| 82 mm, inner support | [dxf](dxf/inner_support_mesh36_s_82mm_spacing.dxf) &middot; [svg](svg/inner_support_mesh36_s_82mm_spacing.svg) | [dxf](dxf/inner_support_mesh36_s_82mm_spacing_24mm_buttons.dxf) &middot; [svg](svg/inner_support_mesh36_s_82mm_spacing_24mm_buttons.svg) |
| 95 mm | [dxf](dxf/mesh36_s_95mm_spacing.dxf) &middot; [svg](svg/mesh36_s_95mm_spacing.svg) | [dxf](dxf/mesh36_s_95mm_spacing_24mm_buttons.dxf) &middot; [svg](svg/mesh36_s_95mm_spacing_24mm_buttons.svg) |
| 95 mm, inner support | [dxf](dxf/inner_support_mesh36_s_95mm_spacing.dxf) &middot; [svg](svg/inner_support_mesh36_s_95mm_spacing.svg) | [dxf](dxf/inner_support_mesh36_s_95mm_spacing_24mm_buttons.dxf) &middot; [svg](svg/inner_support_mesh36_s_95mm_spacing_24mm_buttons.svg) |

### Rhombus template

rhombus36_s inner_support_rhombus36_s

*Left: standard. Right: inner support, with the hole and its Sanwa OBSF ear relief merged into one profile.*

> Diagonal square template from which various layouts can be made.
>
> *Slagcoin*

A square lattice turned 45 degrees, with pairs above and below the centerline alternating with singles on it. Good for diamond shapes and Neo Geo style arrangements.

**9 buttons**  |  stock lever at **95 mm**  |  closest button pitch 36.1 mm at 30 mm, 28.8 mm at 24 mm  |  cut envelope 276 x 91 mm

More previews: [24 mm buttons](preview/rhombus36_s_24mm_buttons.png) &middot; [24 mm inner support](preview/inner_support_rhombus36_s_24mm_buttons.png)

| Version | 30 mm buttons | 24 mm buttons |
|---|---|---|
| Stock | [dxf](dxf/rhombus36_s.dxf) &middot; [svg](svg/rhombus36_s.svg) | [dxf](dxf/rhombus36_s_24mm_buttons.dxf) &middot; [svg](svg/rhombus36_s_24mm_buttons.svg) |
| Stock, inner support | [dxf](dxf/inner_support_rhombus36_s.dxf) &middot; [svg](svg/inner_support_rhombus36_s.svg) | [dxf](dxf/inner_support_rhombus36_s_24mm_buttons.dxf) &middot; [svg](svg/inner_support_rhombus36_s_24mm_buttons.svg) |
| 82 mm | [dxf](dxf/rhombus36_s_82mm_spacing.dxf) &middot; [svg](svg/rhombus36_s_82mm_spacing.svg) | [dxf](dxf/rhombus36_s_82mm_spacing_24mm_buttons.dxf) &middot; [svg](svg/rhombus36_s_82mm_spacing_24mm_buttons.svg) |
| 82 mm, inner support | [dxf](dxf/inner_support_rhombus36_s_82mm_spacing.dxf) &middot; [svg](svg/inner_support_rhombus36_s_82mm_spacing.svg) | [dxf](dxf/inner_support_rhombus36_s_82mm_spacing_24mm_buttons.dxf) &middot; [svg](svg/inner_support_rhombus36_s_82mm_spacing_24mm_buttons.svg) |
| 95 mm | [dxf](dxf/rhombus36_s_95mm_spacing.dxf) &middot; [svg](svg/rhombus36_s_95mm_spacing.svg) | [dxf](dxf/rhombus36_s_95mm_spacing_24mm_buttons.dxf) &middot; [svg](svg/rhombus36_s_95mm_spacing_24mm_buttons.svg) |
| 95 mm, inner support | [dxf](dxf/inner_support_rhombus36_s_95mm_spacing.dxf) &middot; [svg](svg/inner_support_rhombus36_s_95mm_spacing.svg) | [dxf](dxf/inner_support_rhombus36_s_95mm_spacing_24mm_buttons.dxf) &middot; [svg](svg/inner_support_rhombus36_s_95mm_spacing_24mm_buttons.svg) |

### Zigzag template

zigzag36_s inner_support_zigzag36_s

*Left: standard. Right: inner support, with the hole and its Sanwa OBSF ear relief merged into one profile.*

> Zigzag template from which various layouts can be made.
>
> *Slagcoin*

Alternating high and low on a tight horizontal step. The widest template of the three, and the most useful for exploring staggered or wave shaped arrangements.

**12 buttons**  |  stock lever at **95 mm**  |  closest button pitch 36.0 mm at 30 mm, 28.8 mm at 24 mm  |  cut envelope 275 x 92 mm

More previews: [24 mm buttons](preview/zigzag36_s_24mm_buttons.png) &middot; [24 mm inner support](preview/inner_support_zigzag36_s_24mm_buttons.png)

| Version | 30 mm buttons | 24 mm buttons |
|---|---|---|
| Stock | [dxf](dxf/zigzag36_s.dxf) &middot; [svg](svg/zigzag36_s.svg) | [dxf](dxf/zigzag36_s_24mm_buttons.dxf) &middot; [svg](svg/zigzag36_s_24mm_buttons.svg) |
| Stock, inner support | [dxf](dxf/inner_support_zigzag36_s.dxf) &middot; [svg](svg/inner_support_zigzag36_s.svg) | [dxf](dxf/inner_support_zigzag36_s_24mm_buttons.dxf) &middot; [svg](svg/inner_support_zigzag36_s_24mm_buttons.svg) |
| 82 mm | [dxf](dxf/zigzag36_s_82mm_spacing.dxf) &middot; [svg](svg/zigzag36_s_82mm_spacing.svg) | [dxf](dxf/zigzag36_s_82mm_spacing_24mm_buttons.dxf) &middot; [svg](svg/zigzag36_s_82mm_spacing_24mm_buttons.svg) |
| 82 mm, inner support | [dxf](dxf/inner_support_zigzag36_s_82mm_spacing.dxf) &middot; [svg](svg/inner_support_zigzag36_s_82mm_spacing.svg) | [dxf](dxf/inner_support_zigzag36_s_82mm_spacing_24mm_buttons.dxf) &middot; [svg](svg/inner_support_zigzag36_s_82mm_spacing_24mm_buttons.svg) |
| 95 mm | [dxf](dxf/zigzag36_s_95mm_spacing.dxf) &middot; [svg](svg/zigzag36_s_95mm_spacing.svg) | [dxf](dxf/zigzag36_s_95mm_spacing_24mm_buttons.dxf) &middot; [svg](svg/zigzag36_s_95mm_spacing_24mm_buttons.svg) |
| 95 mm, inner support | [dxf](dxf/inner_support_zigzag36_s_95mm_spacing.dxf) &middot; [svg](svg/inner_support_zigzag36_s_95mm_spacing.svg) | [dxf](dxf/inner_support_zigzag36_s_95mm_spacing_24mm_buttons.dxf) &middot; [svg](svg/inner_support_zigzag36_s_95mm_spacing_24mm_buttons.svg) |

---

**From commercial arcade sticks.** Each one names its maker and says how it was obtained. ASI's third layout, the B30, is leverless and lives in [Leverless / All Button Layouts](#leverless--all-button-layouts) instead.

### ASI S24

asi_s24 inner_support_asi_s24

*Left: standard. Right: inner support.*

The S24 layout from **ASI**. A lever on the left, ten 24 mm buttons in two arcs of four with a pair dropping down to the left, and a single 30 mm button below the cluster.

**11 buttons**  |  10 x 24 mm and 1 x 30 mm  |  closest pitch 29.4 mm  |  lever to nearest button 74 mm  |  cut envelope 229 x 128 mm

> **This one was measured from a render, not supplied as a file.** Everything else in this repository comes from a dimensioned drawing or a vector source. This layout was recovered by circle fitting ASI's published product render, so treat it as accurate to roughly a third of a millimeter rather than exact. Print it and check it against a real S24 before cutting anything expensive.

ASI S24 verification

**Positions are snapped to a 0.5 mm grid.** Real panel layouts are laid out on whole or half millimeter spacings, so the raw measured decimals are measurement noise rather than design intent. Every hole was moved to the nearest 0.5 mm node, which shifted each one by at most 0.22 mm. All horizontal and vertical spacings between holes are now exact multiples of 0.5 mm.

Worth being straight about what that does and does not buy. My measurement scatter is around 0.12 mm per coordinate, which is not fine enough to *detect* a 0.5 mm grid on its own: the residuals before snapping sit at 0.122 mm against the 0.144 mm you would expect from no grid at all. So the snap rests on how these panels are actually designed, not on the render proving it. If the grid holds, most coordinates are now exactly right instead of slightly off. A small number sitting near a midpoint could have landed one 0.5 mm step away, and the render cannot tell me which. The scale itself was **not** adjusted to fit the grid, since doing so pushed the measured hole diameters away from nominal.

How it was measured. The ten 24 mm holes came out 101.30 px across with a standard deviation of 0.17 px, which says the render is effectively orthographic and gives the scale at 4.221 px per mm. That scale is corroborated independently by the lever plate bore, which then measures 60.13 mm and is almost certainly a true 60 mm. Every generated hole was projected back onto the render and checked against the drawn edge.

**Lever treatment.** The render shows ASI's own mounting plate with roughly a 60 mm bore. These files instead carry the repository's standard treatment: concentric 24 mm and 35.25 mm bores plus the universal plate pattern. If you are fitting ASI's actual plate you will want their bore, not either of these.

The 30 mm button sits on its own sub plate in the render, a 46 mm disc with a tab below it. That sub plate and its screw are not included, in keeping with how every other layout here drops panel outlines and mounting hardware.

| Version | DXF | SVG |
|---|---|---|
| Standard | [`asi_s24.dxf`](dxf/asi_s24.dxf) | [`asi_s24.svg`](svg/asi_s24.svg) |
| Inner support | [`inner_support_asi_s24.dxf`](dxf/inner_support_asi_s24.dxf) | [`inner_support_asi_s24.svg`](svg/inner_support_asi_s24.svg) |

### ASI S30

asi_s30 inner_support_asi_s30

*Left: standard. Right: inner support.*

The S30 from **ASI**, the 30 mm sibling of the S24. Same overall shape, scaled up for full size buttons: eight 30 mm in two arcs of four, a 24 mm at the top of the cluster and another below it, and a 30 mm on its own sub plate at the bottom left.

**11 buttons**  |  9 x 30 mm and 2 x 24 mm  |  closest pitch 32.9 mm  |  lever to nearest button 74 mm  |  cut envelope 247 x 134 mm

> **Measured from a render, same as the S24.** Accurate to roughly a third of a millimeter rather than exact. Print it and check it against a real S30 before cutting.

ASI S30 verification

**Positions are snapped to a 0.5 mm grid.** Real panel layouts are laid out on whole or half millimeter spacings, so the raw measured decimals are measurement noise rather than design intent. Every hole was moved to the nearest 0.5 mm node, which shifted each one by at most 0.20 mm. All horizontal and vertical spacings between holes are now exact multiples of 0.5 mm.

Worth being straight about what that does and does not buy. My measurement scatter is around 0.12 mm per coordinate, which is not fine enough to *detect* a 0.5 mm grid on its own: the residuals before snapping sit at 0.124 mm against the 0.144 mm you would expect from no grid at all. So the snap rests on how these panels are actually designed, not on the render proving it. If the grid holds, most coordinates are now exactly right instead of slightly off. A small number sitting near a midpoint could have landed one 0.5 mm step away, and the render cannot tell me which. The scale itself was **not** adjusted to fit the grid, since doing so pushed the measured hole diameters away from nominal.

This one carries an unusually strong internal check. Calibrating the scale on the eight 30 mm holes alone makes two other features fall out correctly without being fitted to: the pair of small buttons measure **23.98 mm** and the lever bore measures **60.09 mm**. Three independent features agreeing at that level means the render is orthographic and the scale is right. Every hole then measured within 0.1 mm of its nominal size before being normalized.

Same lever treatment and the same dropped sub plate as the S24 above.

| Version | DXF | SVG |
|---|---|---|
| Standard | [`asi_s30.dxf`](dxf/asi_s30.dxf) | [`asi_s30.svg`](svg/asi_s30.svg) |
| Inner support | [`inner_support_asi_s30.dxf`](dxf/inner_support_asi_s30.dxf) | [`inner_support_asi_s30.svg`](svg/inner_support_asi_s30.svg) |

### JasensCustoms Sega 2P IMPACT

jasenscustoms_sega2p_impact inner_support_jasenscustoms_sega2p_impact

*Left: standard. Right: inner support.*

The Sega 2P non slanted cluster at 82 mm lever spacing with one extra 24 mm button tucked below and left of it, between the lever and the first column. Taken from [JasensCustoms.com](https://www.jasenscustoms.com)' cut file `jasenscustoms-pfs4-mczte-sega2p-IMPACT-withbezel.svg` for the IMPACT plate, which fits the Panzer Fight Stick 4 and the Mad Catz TE. The extra button is the part that does not already exist anywhere else in this library.

**Parts: Japanese** | 8 x 30 mm and 1 x 24 mm snap in buttons | GL mounting system | 24 and 35.25 mm bores, alternatives

**9 buttons** | 8 x 30 mm, 1 x 24 mm | closest pitch 35.9 mm | **82 mm lever spacing only** | cut envelope 238 x 116 mm

**The plate itself is deliberately not here.** The source draws a complete 322.968 x 176.777 mm panel with 8.894 mm corner radii, six 3/16 in mounting screw holes and a 90.35 x 28.19 mm control strip window at the top left. All of that is specific to that plate and to the two sticks it bolts into. This library ships drilling patterns rather than panels, so the file carries the holes only and drops into any panel like everything else here. If you want the plate, get it from JasensCustoms.

**The eight main centers come from this library, not from the SVG.** Seven of the eight matched [`sega2_s_82mm_spacing`](#sega-p2-non-slanted) to within 0.03 mm. The eighth, the upper right, was drawn at x = 184.499 while its own column partner sat at 184.002, so the source is 0.5 mm out on that one hole. That reads as a drafting slip rather than intent, so this file inherits the library's exact centers and the two columns line up again. The 24 mm button is kept exactly as drawn, at **(61.9795, -50.0309)** from the lever center, because there is nothing in the library to check it against.

**Holes are cut nominal.** The source draws every hole 0.25 mm over: buttons at 30.245 mm, the two 24 mm holes at 30.249 and 24.256. That is a cutting clearance and it belongs to whoever is cutting rather than to the drawing, so this file carries 30.000, 24.000 and the two standard bores. The ear relief tab sizes assume nominal holes, which is the other reason.

**One lever spacing, 82 mm**, because that is where the plate puts it. The Sega 2P cluster at other spacings already ships as [`sega2_s`](#sega-p2-non-slanted); what is new here is the extra button, and its position is only known at 82 mm.

**Screw in nuts:** no. The 30 mm cluster is 0.066 mm short at its tightest pair and the 24 mm version is 0.753 mm short, both inherited from the Sega 2P spacing. The added 24 mm button is not the problem: it clears by 9.108 mm at 30 mm and by 4.868 mm at 24 mm. See [Screw in buttons and nut clearance](#screw-in-buttons-and-nut-clearance).

The **24 mm version** scales the cluster by the usual 0.8 about the first button column and the joystick centerline, which lands the eight exactly on `sega2_s_82mm_spacing_24mm_buttons` and carries the added button to (65.9836, -40.0247). All nine holes are then 24 mm, so they share a single `BUTTONS` layer rather than the split pair.

| Version | 30 mm | 24 mm |
|---|---|---|
| Standard | [dxf](dxf/jasenscustoms_sega2p_impact.dxf) &middot; [svg](svg/jasenscustoms_sega2p_impact.svg) | [dxf](dxf/jasenscustoms_sega2p_impact_24mm_buttons.dxf) &middot; [svg](svg/jasenscustoms_sega2p_impact_24mm_buttons.svg) |
| Inner support | [dxf](dxf/inner_support_jasenscustoms_sega2p_impact.dxf) &middot; [svg](svg/inner_support_jasenscustoms_sega2p_impact.svg) | [dxf](dxf/inner_support_jasenscustoms_sega2p_impact_24mm_buttons.dxf) &middot; [svg](svg/inner_support_jasenscustoms_sega2p_impact_24mm_buttons.svg) |

More previews: [24 mm](preview/jasenscustoms_sega2p_impact_24mm_buttons.png) &middot; [24 mm inner support](preview/inner_support_jasenscustoms_sega2p_impact_24mm_buttons.png)

---

**From real cabinets.** Traced from published drawings rather than from a stick. Cabinet only features, meaning second player halves and Start buttons, are left out so the layouts drop straight into a single player stick.

### Mortal Kombat 3 / Ultimate MK3

mk3_umk3_dedicated_american_parts inner_support_mk3_umk3_dedicated_american_parts

*Left: standard. Right: inner support, which on this layout is an identical copy. See below.*

One player's worth of the control panel from the dedicated **Mortal Kombat 3 / Ultimate Mortal Kombat 3** cabinet, from the dimensioned drawing by **Twistedsymphony** on [classicarcadecabinets.com](https://www.classicarcadecabinets.com/mortal-kombat-3.html).

A lever and six buttons: the classic five button Mortal Kombat block, meaning two columns of two with Block sitting between them on the lever centerline, plus Run down at the front left.

**6 buttons**  |  1.125 in (28.575 mm)  |  closest pitch 48.5 mm  |  lever to nearest button 77.5 mm  |  cut envelope 215 x 119 mm

**Two things on the cabinet drawing are not built here**, because neither belongs on a stick. The original is a two player panel, so the mirrored second half, 11.625 in to the right, is dropped. So is the seventh button per player, which sits well away from the cluster at 1.500 across and 3.750 back and is the cabinet Start button.

> ### This layout is imperial
>
> **Everything about it is designed in inches.** The panel, the button spacing and the hole size are all whole sixteenths: 1.125 in holes on a grid of 1.000, 1.500, 1.625, 2.500 and 3.250 in. Nothing here was conceived in millimeters, and it is the only layout in the repository like that.
>
> The files themselves are still millimeters, because every file here is, and DXF has no way to say "this drawing thinks in inches" that CAM software reliably honors. So the coordinates convert exactly: **1 in = 25.4 mm**, no rounding anywhere. What that means in practice is that the metric numbers look wrong when they are right. Buttons sit at 44.45, 82.55, 123.825 and 165.10 mm across and at 25.40, 0 and -63.50 mm up and down. Holes are 28.575 mm, not 28.6 and not 28.5.
>
> **If you are editing this file, switch your CAD to inches.** Every dimension becomes a clean number and stays that way. Work in millimeters and you will be tempted to round 123.825 to 123.8, which is a real 0.025 mm error introduced for no reason. Nothing in this file should ever be rounded to a tidier millimeter value.
>
> The one exception is the lever, which is genuinely metric because the hardware is. See [Lever hardware](#mortal-kombat-3--ultimate-mk3) below: 35 mm bore, 5.9 mm holes, 65.6 by 75.9 mm. Those are IL's numbers and they are not derived from anything on the MK3 drawing. So this file honestly mixes both systems, imperial for the panel and metric for the lever, which is exactly what building this panel with an IL stick involves.

> **This one is exact, not measured.** Every coordinate below is a printed dimension from the drawing, converted by a factor of exactly 25.4. Nothing is snapped, rounded or inferred. Sub pixel circle fitting on the source drawing was used only to *confirm* the reading: every built hole lands within **0.07 mm** of its fitted center, and all 16 holes on the drawing are accounted for, 7 built and 9 deliberately left out.

Hole positions in inches from the player one lever center, which is the origin:

| X | Y | Position | Likely function |
|---|---|---|---|
| 3.250 | 1.000 | first column, upper | High punch |
| 3.250 | -1.000 | first column, lower | Low punch |
| 4.875 | 0.000 | midway between the columns, on the centerline | Block |
| 6.500 | 1.000 | second column, upper | High kick |
| 6.500 | -1.000 | second column, lower | Low kick |
| 1.750 | -2.500 | front, inboard of the lever | Run |

+Y is toward the back, away from the player. The millimeter equivalents are in the imperial note above.

The five in the block are certain, since two columns with Block in the middle is the Mortal Kombat signature. The sixth is an inference, since the drawing labels nothing: it sits 1.5 by 1.5 in off the low punch corner, close enough to read as part of the cluster, which is where Run goes. Wire them however you like.

**Lever hardware is IL, not GL.** This panel is built for an **Industrias Lorenzo Eurojoystick 2**, so it does not carry the universal plate pattern the rest of the repository uses. From IL's own panel mounting drawing:

| Feature | Size | Position |
|---|---|---|
| Bore | 35 mm | on the lever center |
| Screw holes | 4 x 5.9 mm | 65.6 mm across by 75.9 mm front to back |

> **The bore deliberately disagrees with the source drawing.** Twistedsymphony calls the lever hole 1.1875 in, which is the Happ and American shaft size the cabinet originally shipped with. An IL boss will not pass through 30.16 mm, so these files carry IL's 35 mm instead. If you are fitting an American lever, change that one circle back to 30.1625 mm and leave everything else alone.
>
> IL also shows a second set of four 9.9 mm reliefs on a 46.3 by 77.4 mm rectangle, for the bosses on the underside of the joystick. Those are not included. On a normal thickness panel the bosses clear; on a thick panel you may want them.

**The inner support file is a plain copy.** These are 1.125 in American style buttons. They bolt in with a nut and have no snap-in retention ears, so there is nothing for an ear relief slot to relieve. The `inner_support_` file is provided so the naming stays consistent across the library, but its geometry is identical to the standard file.

**Panel outline is not included**, in keeping with every other layout here. For reference, the cabinet panel is 26.625 by 13.125 in, with the player one lever 5.000 in from the left edge and 6.875 in up from the front edge. That is enough to rebuild the full two player panel from these coordinates if you ever want it.

| Version | DXF | SVG |
|---|---|---|
| Standard | [`mk3_umk3_dedicated_american_parts.dxf`](dxf/mk3_umk3_dedicated_american_parts.dxf) | [`mk3_umk3_dedicated_american_parts.svg`](svg/mk3_umk3_dedicated_american_parts.svg) |
| Inner support | [`inner_support_mk3_umk3_dedicated_american_parts.dxf`](dxf/inner_support_mk3_umk3_dedicated_american_parts.dxf) | [`inner_support_mk3_umk3_dedicated_american_parts.svg`](svg/inner_support_mk3_umk3_dedicated_american_parts.svg) |

Want this spacing with Sanwa parts instead? See [Mortal Kombat 3, Japanese hardware](#mortal-kombat-3-japanese-hardware).

### Mortal Kombat 3, Japanese hardware

mk3_umk3_dedicated_japanese_parts inner_support_mk3_umk3_dedicated_japanese_parts

*Left: standard. Right: inner support, with real ear relief slots on this one.*

The same Mortal Kombat spacing, built for Japanese parts. **Every button center is identical to the imperial file above, down to the last decimal.** What changes is the hardware that goes in the holes.

| | `mk3_umk3_dedicated_american_parts` | `mk3_umk3_dedicated_japanese_parts` |
|---|---|---|
| Button hole | 1.125 in (28.575 mm) | **30 mm** |
| Button style | American, nut mount | **Sanwa OBSF snap in** |
| Lever | IL Eurojoystick 2 | **Universal GL plate** |
| Bore | 35 mm | **24 mm and 35.25 mm, pick one** |
| Lever mounting | 4 x 5.9 mm on 65.6 x 75.9 mm | **the full GL pattern** |
| Inner support | plain copy, no ears to relieve | **real ear relief slots** |
| Button centers | identical | identical |

**6 buttons**  |  30 mm  |  closest pitch 48.5 mm  |  lever to nearest button 77.5 mm  |  cut envelope 219 x 124 mm

**Why it fits comfortably.** MK spacing is generous by modern standards, so going up from 28.575 to 30 mm costs almost nothing. The closest pair of holes still leaves **18.5 mm** of material between them, against 19.9 mm on the imperial file. There is no crowding anywhere on this panel.

**The ear slots do not fight each other.** Buttons here sit 48.5 mm apart at the closest, and a 35 mm slot only reaches 17.5 mm from its own center, so no two slots come near each other. Every slot on this layout stays at the default 30 degrees clockwise from vertical, and the thinnest web of material is **17.1 mm**. That is the widest margin of any inner support file in the repository, and by a long way. Nothing had to be rotated. See [Inner support versions](#inner-support-versions) for what that machinery does on the tighter layouts.

**The lever hardware clears everything.** The GL plate is physically larger than the IL cut it replaces, so it is worth stating the numbers: the closest GL feature to any button edge is **14.5 mm**, and to the tip of an ear slot **12.0 mm**. The 35.25 mm bore sits **44.9 mm** clear of the nearest button.

**This file is still imperial underneath.** The centers come straight from the Twistedsymphony drawing, so 44.45, 82.55, 123.825 and 165.10 mm still apply and still should not be rounded. Only the hole diameter is a round metric number. Everything in the imperial note above applies here too.

| Version | DXF | SVG |
|---|---|---|
| Standard | [`mk3_umk3_dedicated_japanese_parts.dxf`](dxf/mk3_umk3_dedicated_japanese_parts.dxf) | [`mk3_umk3_dedicated_japanese_parts.svg`](svg/mk3_umk3_dedicated_japanese_parts.svg) |
| Inner support | [`inner_support_mk3_umk3_dedicated_japanese_parts.dxf`](dxf/inner_support_mk3_umk3_dedicated_japanese_parts.dxf) | [`inner_support_mk3_umk3_dedicated_japanese_parts.svg`](svg/inner_support_mk3_umk3_dedicated_japanese_parts.svg) |

### Neo Geo MVS Type 1

neogeo_mvs_type1_japanese_parts inner_support_neogeo_mvs_type1_japanese_parts

*Left: standard. Right: inner support.*

The curved four button layout from the dedicated **Neo Geo MVS** cabinet, from the `MVS CPO CURVED template` drilling templates by **Crowquilll**, dated 7/07 and traced from a scan of the control panel overlay of a dedicated 2-25 cabinet.

Four buttons sweeping up and to the right in a shallow curve, which is what makes this layout distinctive: it is not two rows, and it is not a straight line. The holes sit on a **150 mm radius arc** at a consistent 15.8 degrees apart, so your fingers follow one continuous curve rather than stepping between rows.

**4 buttons**  |  30 mm  |  closest pitch 41.0 mm  |  lever to nearest button 80.4 mm  |  cut envelope 246 x 91 mm

**Japanese hardware, not what the cabinet shipped with.** The template calls for 1.1875 in button holes and a 1.875 in lever hole, which are the American drill sizes for the parts SNK fitted to these cabinets. This file carries 30 mm holes and the repository's standard GL lever treatment instead, so it takes Sanwa or Seimitsu parts.

**Read out of the artwork, not measured off pixels.** Both templates are true scale vector PDFs, so the hole centers come straight from the page geometry. The 2P sheet is exactly 1710 by 630 points, which is precisely the 23.75 by 8.75 in the artwork states, so no scale calibration was needed at all.

> **One layout, not two.** There is a 1P sheet and a 2P sheet, and it is worth being clear that they describe the same cluster. Player two is not mirrored, it is player one translated to the right, and the two sheets agree with each other to 0.001 points. One file cuts either side. To lay out the full two player panel, place this file twice **288.0 mm** apart.
>
> That spacing is worth a note. The raw trace gives 288.102 mm, but snapping both clusters to the grid together lands all five matching pairs on exactly 288.0 mm, which is what the panel was almost certainly drawn to. Use 288.0.

**Positions are snapped to the 0.5 mm grid.** The template is a trace of a scan, so the raw decimals are tracing noise rather than design intent. One global phase was fitted across all five holes and every hole moved to its nearest 0.5 mm node, the largest single move being 0.27 mm, well inside the 0.354 mm the grid allows.

Three things say this snap is recovering the design rather than inventing one. The chord spacing between neighboring buttons gets *tighter*, from a spread of 0.62 mm down to 0.43 mm. The exactly equal height of the last two holes, which the tracer clearly intended, survives. And snapping both player clusters together lands the player two offset on exactly 288.0 mm across all five matching pairs, from a raw 288.102, which is a clean design number falling out of a fit that was not aiming at it. Every horizontal and vertical gap between holes is now an exact multiple of 0.5 mm.

> **One hole is genuinely a coin toss, and you should know which.** The front button's raw height is 22.768 mm below the centerline, which sits 0.018 mm from the exact midpoint between the 22.5 and 23.0 grid nodes. The phase fit puts it at **23.0** and that is what these files carry, but the source cannot really distinguish the two. If you have a physical panel to measure, that is the one hole worth checking. Every other hole sits comfortably nearer one node than the other.

**The ear slots need one rotation.** At 41 mm centers, two 35 mm slots pointed at each other leave only 9.9 mm of material. Turning the two lower buttons to 75 degrees lifts that to **11.0 mm**, which is the circle to circle limit, so on this layout the slots stop being the constraint entirely.

**Not included, as asked:** the three lone buttons along the top of the CPO. The artwork labels them itself, as 1P Start, 2P Start and Select Game.

| Version | DXF | SVG |
|---|---|---|
| Standard | [`neogeo_mvs_type1_japanese_parts.dxf`](dxf/neogeo_mvs_type1_japanese_parts.dxf) | [`neogeo_mvs_type1_japanese_parts.svg`](svg/neogeo_mvs_type1_japanese_parts.svg) |
| Inner support | [`inner_support_neogeo_mvs_type1_japanese_parts.dxf`](dxf/inner_support_neogeo_mvs_type1_japanese_parts.dxf) | [`inner_support_neogeo_mvs_type1_japanese_parts.svg`](svg/inner_support_neogeo_mvs_type1_japanese_parts.svg) |

Want this with American parts instead? See [Neo Geo MVS Type 1, American hardware](#neo-geo-mvs-type-1-american-hardware).

### Neo Geo MVS Type 1, American hardware

neogeo_mvs_type1_american_parts inner_support_neogeo_mvs_type1_american_parts

*Left: standard. Right: inner support, which on this layout is an identical copy. See below.*

The same Neo Geo curve cut for American parts, using the hole sizes the template itself calls for. **Every button center is identical to the Japanese file above.**

| | `neogeo_mvs_type1_japanese_parts` | `neogeo_mvs_type1_american_parts` |
|---|---|---|
| Button hole | 30 mm | **1.1875 in (30.1625 mm)** |
| Button style | Sanwa OBSF snap in | **American, nut mount** |
| Lever | Universal GL plate | **IL Eurojoystick 2** |
| Bore | 24 mm and 35.25 mm, pick one | **35 mm** |
| Lever mounting | the full GL pattern | **4 x 5.9 mm on 65.6 x 75.9 mm** |
| Inner support | real ear relief slots | plain copy, no ears to relieve |
| Button centers | identical | identical |

**4 buttons**  |  1.1875 in  |  closest pitch 41.0 mm  |  lever to nearest button 80.4 mm  |  cut envelope 243 x 82 mm

**Why the centers are shared rather than re-derived in inches.** The obvious thing to try was snapping the trace to an imperial grid instead of the metric one, since the source is a PDF measured in points. It fits distinctly worse. On a 1/16 in grid the largest hole has to move **0.72 mm** to reach a node, against **0.26 mm** on the 0.5 mm grid, and the rms more than doubles, 0.239 mm against 0.105 mm. SNK laid this panel out in millimeters. The imperial numbers belong to the American hardware that was bolted into it, not to the design, so this file changes the holes and leaves their positions alone.

**The hole size is the template's own.** 1.1875 in is what Crowquilll drew, and it is a real Happ and IL drill size. Worth knowing before you cut: a lot of American pushbuttons want **1.125 in** instead, and at this pitch there is plenty of room to drop to that if your buttons need it. Nothing else in the file would change.

**The lever bore is IL's, not the template's.** The template calls for a 1.875 in lever hole, 47.625 mm, which is the American stick the cabinet shipped with. An IL Eurojoystick 2 wants 35 mm and its own screw pattern, so that is what this file carries. If you are fitting an American lever instead, open that circle back up to 47.625 mm and use your own mounting pattern.

**The inner support file is a plain copy.** American buttons bolt in with a nut and have no snap-in retention ears, so there is nothing for a relief slot to relieve. It exists so the naming stays consistent, but its geometry is identical to the standard file. Same as the [Mortal Kombat American file](#mortal-kombat-3--ultimate-mk3).

Everything else, the 150 mm radius arc, the 0.5 mm snap and the reasoning behind it, the excluded top buttons and the 288.0 mm player two spacing, is covered in [Neo Geo MVS Type 1](#neo-geo-mvs-type-1) above and applies here unchanged.

| Version | DXF | SVG |
|---|---|---|
| Standard | [`neogeo_mvs_type1_american_parts.dxf`](dxf/neogeo_mvs_type1_american_parts.dxf) | [`neogeo_mvs_type1_american_parts.svg`](svg/neogeo_mvs_type1_american_parts.svg) |
| Inner support | [`inner_support_neogeo_mvs_type1_american_parts.dxf`](dxf/inner_support_neogeo_mvs_type1_american_parts.dxf) | [`inner_support_neogeo_mvs_type1_american_parts.svg`](svg/inner_support_neogeo_mvs_type1_american_parts.svg) |

### Neo Geo MVS Type 2

neogeo_mvs_type2_japanese_parts inner_support_neogeo_mvs_type2_japanese_parts

*Left: standard. Right: inner support.*

The **Neo Geo MVS Type 2** panel, the one that was everywhere in the United States from the 1990s into the 2000s. A sits low and to the left, and B, C and D run in a **straight horizontal line**. That line is the whole difference from [Type 1](#neo-geo-mvs-type-1), whose four holes follow one continuous arc.

Requested on [issue 3](https://github.com/JasensCustoms/FightStickLayoutProject/issues/3) by **KidGamer77**, who also found the reference art.

**4 buttons**  |  30 mm  |  closest pitch 41.0 mm  |  lever to nearest button 69.5 mm  |  cut envelope 242 x 105 mm

**This one has an independent ruler, and it is the reason the other three can be trusted.** The source is a Phoenix Arcade screen printed reproduction CPO photographed flat and square on, and their listing states the panel is **9.25 by 23.625 inches**. The measured aspect ratio of the panel in the photograph comes out within **0.013 percent** of that, and the two axes then give scales 0.013 percent apart, so the stated size is real and the image is undistorted. Two further checks fall out for free: lever to lever lands **287.83 mm** against the 288.10 mm the Type 1 vector template gives, a difference of 0.27 mm across 288, and the panel's two clusters put B, C and D at the same height as each other to within 0.21 mm.

**Both player clusters were measured and averaged.** They are a screen printed physical panel rather than a drawing, so their holes differ from each other by up to a millimeter and a half. Averaging the pair is the closest thing to the drawing that made them.

**Positions are snapped to the 0.5 mm grid**, the same treatment Type 1 got. Largest move 0.21 mm in x and 0.16 mm in y. The metric grid fits three times better than 1/16 in and roughly one and a half times better than 1/32 in, which says the same thing the Type 1 trace said: SNK laid this out in millimeters.

| | mm from the lever center |
|---|---|
| A | (69.5, 1.0) |
| B | (105.5, 44.0) |
| C | (146.5, 44.0) |
| D | (188.0, 44.0) |

B to C is 41.0 mm and C to D is 41.5 mm, which is the same slightly irregular pitch Type 1 carries. A sits 56.1 mm from B, well clear of everything.

**The art hole is not the drill size.** The button holes in this overlay measure 31.22 mm, because a CPO is cut a little over so the artwork is not pinched by the button flange. These files carry 30.00 mm, which is what the part needs.

| Version | DXF | SVG |
|---|---|---|
| Standard | [`neogeo_mvs_type2_japanese_parts.dxf`](dxf/neogeo_mvs_type2_japanese_parts.dxf) | [`neogeo_mvs_type2_japanese_parts.svg`](svg/neogeo_mvs_type2_japanese_parts.svg) |
| Inner support | [`inner_support_neogeo_mvs_type2_japanese_parts.dxf`](dxf/inner_support_neogeo_mvs_type2_japanese_parts.dxf) | [`inner_support_neogeo_mvs_type2_japanese_parts.svg`](svg/inner_support_neogeo_mvs_type2_japanese_parts.svg) |

Want this with American parts instead? See [Neo Geo MVS Type 2, American hardware](#neo-geo-mvs-type-2-american-hardware).

### Neo Geo MVS Type 2, American hardware

neogeo_mvs_type2_american_parts inner_support_neogeo_mvs_type2_american_parts

*Left: standard. Right: inner support, which on this layout is an identical copy.*

The same Type 2 arrangement cut for American parts. **Every button center is identical to the Japanese file above.** 1.125 in buttons and an IL Eurojoystick 2 lever, which is what American Parts means everywhere in this repository.

The reference panel was screen printed for cabinets fitted with Industrias Lorenzo buttons, so this is arguably the more period correct of the two cuts.

**4 buttons**  |  1.125 in (28.575 mm)  |  closest pitch 41.0 mm  |  lever to nearest button 69.5 mm  |  cut envelope 238 x 99 mm

The inner support file is a plain copy. American buttons bolt in with a nut and have no snap in retention ears, so there is nothing for a relief slot to relieve. Same as the [Type 1 American file](#neo-geo-mvs-type-1-american-hardware).

| Version | DXF | SVG |
|---|---|---|
| Standard | [`neogeo_mvs_type2_american_parts.dxf`](dxf/neogeo_mvs_type2_american_parts.dxf) | [`neogeo_mvs_type2_american_parts.svg`](svg/neogeo_mvs_type2_american_parts.svg) |
| Inner support | [`inner_support_neogeo_mvs_type2_american_parts.dxf`](dxf/inner_support_neogeo_mvs_type2_american_parts.dxf) | [`inner_support_neogeo_mvs_type2_american_parts.svg`](svg/inner_support_neogeo_mvs_type2_american_parts.svg) |

### Neo Geo Mini

neogeo_mini_japanese_parts inner_support_neogeo_mini_japanese_parts

*Left: standard. Right: inner support.*

The aggressively curved Neo Geo arrangement, the one whose arc resembles the **AES** pad rather than the shallow sweep of [Type 1](#neo-geo-mvs-type-1). It is sold as a Neo Geo mini CPO. Type 1 climbs 34 mm from A to D across 116 mm of width. This one climbs **65 mm** across 96 mm, so it is both steeper and shorter, and your hand rolls up the curve rather than reaching along it.

Requested on [issue 3](https://github.com/JasensCustoms/FightStickLayoutProject/issues/3) by **KidGamer77**.

**4 buttons**  |  30 mm  |  closest pitch 39.9 mm  |  lever to nearest button 73.8 mm  |  cut envelope 222 x 113 mm

| | mm from the lever center |
|---|---|
| A | (72.5, -13.5) |
| B | (97.0, 20.0) |
| C | (129.5, 43.5) |
| D | (168.5, 52.0) |

**The source photograph had real perspective in it, and it was corrected rather than ignored.** The overlay was photographed lying on a stone worktop, slightly off to one side, and the right hand cluster's holes came out **7 percent larger** than the left hand cluster's. Measuring that as it stood would have been worthless. The correction uses only facts about the panel: every button hole is the same size, every lever hole is the same size, and the panel carries the same cluster twice as a sideways translation rather than a mirror, which the Type 1 vector template proves to within a thousandth of a point. Fitting one transformation against both constraints at once brings the cluster size disagreement down to 2 percent and lands the five player one to player two offsets within **0.3 percent** of each other. After that, the two clusters agree hole for hole to **0.6 mm**, and to 0.3 mm on three of the four.

**This panel is smaller than a full size MVS CPO.** With the button holes set to 30 mm, its lever to lever spacing comes out **228 mm** rather than the 288 mm of the Type 1 and Type 2 panels. The artwork is the full size art, but the panel it is printed on is not, which is what the word mini in the product name is doing. If you are laying out a two player panel from this file, use 228 mm, not 288.

**Positions are snapped to the 0.5 mm grid**, largest move 0.24 mm on both axes, and again the metric grid beats 1/16 in by a factor of three.

| Version | DXF | SVG |
|---|---|---|
| Standard | [`neogeo_mini_japanese_parts.dxf`](dxf/neogeo_mini_japanese_parts.dxf) | [`neogeo_mini_japanese_parts.svg`](svg/neogeo_mini_japanese_parts.svg) |
| Inner support | [`inner_support_neogeo_mini_japanese_parts.dxf`](dxf/inner_support_neogeo_mini_japanese_parts.dxf) | [`inner_support_neogeo_mini_japanese_parts.svg`](svg/inner_support_neogeo_mini_japanese_parts.svg) |

Want this with American parts instead? See [Neo Geo Mini, American hardware](#neo-geo-mini-american-hardware).

### Neo Geo Mini, American hardware

neogeo_mini_american_parts inner_support_neogeo_mini_american_parts

*Left: standard. Right: inner support, which on this layout is an identical copy.*

The same steep Neo Geo curve cut for American parts. **Every button center is identical to the Japanese file above.**

**4 buttons**  |  1.125 in (28.575 mm)  |  closest pitch 39.9 mm  |  lever to nearest button 73.8 mm  |  cut envelope 219 x 107 mm

The inner support file is a plain copy, for the same reason as every other American Parts file here.

| Version | DXF | SVG |
|---|---|---|
| Standard | [`neogeo_mini_american_parts.dxf`](dxf/neogeo_mini_american_parts.dxf) | [`neogeo_mini_american_parts.svg`](svg/neogeo_mini_american_parts.svg) |
| Inner support | [`inner_support_neogeo_mini_american_parts.dxf`](dxf/inner_support_neogeo_mini_american_parts.dxf) | [`inner_support_neogeo_mini_american_parts.svg`](svg/inner_support_neogeo_mini_american_parts.svg) |

### Neo Geo MVS-U4

neogeo_mvs_u4_japanese_parts inner_support_neogeo_mvs_u4_japanese_parts

*Left: standard. Right: inner support.*

The **SNK MVS-U4 25** panel. Same idea as [Type 2](#neo-geo-mvs-type-2), A low and left with B, C and D level, but the whole cluster is drawn much tighter: **36 mm** between neighbors instead of 41, and the lever sits only 56 mm from the first button. It is the most compact Neo Geo arrangement here by a wide margin.

Requested on [issue 3](https://github.com/JasensCustoms/FightStickLayoutProject/issues/3) by **KidGamer77**, who supplied the panel name and a flat photograph of a reproduction overlay.

**4 buttons**  |  30 mm  |  closest pitch 36.0 mm  |  lever to nearest button 56.1 mm  |  cut envelope 216 x 91 mm

| | mm from the lever center |
|---|---|
| A | (56.0, -3.5) |
| B | (90.0, 10.5) |
| C | (126.0, 10.5) |
| D | (162.5, 10.5) |

**36.0 mm is exactly the screw in nut limit.** Two 30 mm nuts are 36.0 mm across, so B, C and D sit nut edge to nut edge with nothing to spare. Screw in buttons will physically fit and will not tighten comfortably. Treat this layout as snap in, or open the pitch yourself if you need nuts. See [Screw in buttons and nut clearance](#screw-in-buttons-and-nut-clearance).

**Japanese parts only, and the artwork agrees.** The round opening beside each cluster measures **19.8 mm**, far too small for an American lever bore. That is a joystick shaft opening for a lever that mounts underneath the panel, which is how Japanese sticks are built. This file carries the repository's standard GL lever treatment; the 19.8 mm opening is recorded here rather than cut.

**Positions are snapped to the 0.5 mm grid**, largest move 0.18 mm in x and 0.12 mm in y, and the metric grid beats 1/16 in by more than four to one on this panel.

| Version | DXF | SVG |
|---|---|---|
| Standard | [`neogeo_mvs_u4_japanese_parts.dxf`](dxf/neogeo_mvs_u4_japanese_parts.dxf) | [`neogeo_mvs_u4_japanese_parts.svg`](svg/neogeo_mvs_u4_japanese_parts.svg) |
| Inner support | [`inner_support_neogeo_mvs_u4_japanese_parts.dxf`](dxf/inner_support_neogeo_mvs_u4_japanese_parts.dxf) | [`inner_support_neogeo_mvs_u4_japanese_parts.svg`](svg/inner_support_neogeo_mvs_u4_japanese_parts.svg) |
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

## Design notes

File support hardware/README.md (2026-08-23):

# Support hardware

Cut files for the hardware that goes **around** a panel rather than in it: connectors, pass throughs, and anything else that needs a hole in a case wall or a plate.

Everything here is drawn 1:1 in millimeters, in DXF and SVG, on the same conventions as the rest of the repository. Drop one into a case wall or a panel file, move it where you want it, and cut. The origin of each file is the center of its main bore, so positioning is a single translation.

These are **panel cutouts, not parts**. Nothing here draws the connector itself, the wall it sits in, or the outline of anything. Each file is exactly the set of holes that one piece of hardware needs.

---

## Contents

| Hardware | Cutout | Files |
|---|---|---|
| [Neutrik D-shape USB pass through](#neutrik-d-shape-usb-pass-through) | 24.0 mm bore, 4 mounting holes | [`NeutrikCutout.DXF`](NeutrikCutout.DXF) &middot; [`NeutrikCutout.SVG`](NeutrikCutout.SVG) &middot; [`NeutrikCutout.SLDPRT`](NeutrikCutout.SLDPRT) |
| [E-Switch RR1 round rocker switch](#e-switch-rr1-round-rocker-switch) | 20.0 mm bore, 4 notches | [`ESwitchRR1SeriesCutout.DXF`](ESwitchRR1SeriesCutout.DXF) &middot; [`ESwitchRR1SeriesCutout.SVG`](ESwitchRR1SeriesCutout.SVG) &middot; [`ESwitchRR1SeriesCutout.SLDPRT`](ESwitchRR1SeriesCutout.SLDPRT) |

---

## Neutrik D-shape USB pass through

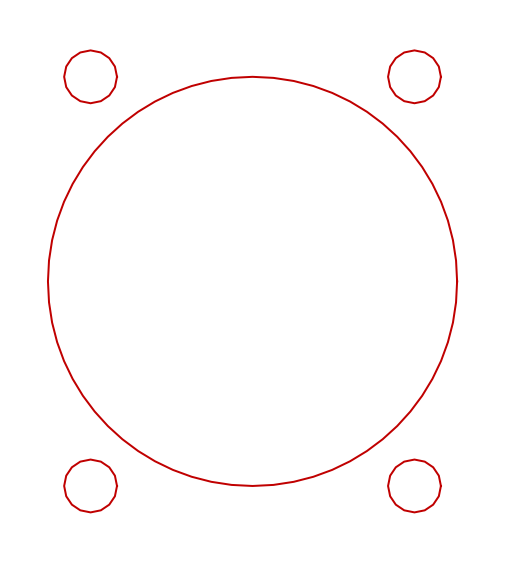
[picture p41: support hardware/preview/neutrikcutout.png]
Neutrik D-shape panel cutout


*The cutout as it is drawn: one 24 mm bore and four 3.1 mm mounting holes.*

The panel cutout for a **Neutrik D-shape USB pass through**, the part most people put in the back of a stick so the cable plugs into the case instead of into the board. Neutrik's own name for that part is a gender changer: it takes USB in one side and out the other, so the board keeps a short internal cable and the outside of the case takes the wear.

> "Reversible USB 2.0 gender changer (type A and B), Nickel D-housing"
>
> "Universally accepted standard D-shape housing"
>
> *Neutrik, [NAUSB-W product page](https://www.neutrik.com/en/product/nausb-w)*

### This cutout is not Neutrik specific

**The D-shape is a de facto industry standard, and that is the point of this file.** Neutrik calls the housing "universally accepted" above, and states the cutout size plainly in its D series chassis connector data:

> "Standardized D sized 24 mm panel cutout"
>
> *Neutrik, [NC3MD-L-1 datasheet](https://www.neutrik.com/en/product/nc3md-l-1.pdf)*

So **any pass through built to the D-shape standard will fit this hole**, whatever the brand and whatever passes through it. The same 24 mm cutout takes D-shape USB, XLR, Ethercon, HDMI, 3.5 mm, and the blanking plates, from Neutrik and from everyone who builds to the same shell. If you decide later that you want Ethernet instead of USB, the hole does not change.

The D series is described by Neutrik as a "Unified D-size shell for male and female" with "Countersunk mounting holes to accept M3 bolts or rivets", for a "Panel thickness 1 - 3 mm" ([D Series](https://www.neutrik.com/en/neutrik/products/xlr-connectors/xlr-chassis-connectors/d-series)). The panel thickness range is worth checking against your own build: the case in this repository laminates a 5.6 mm inner layer and a 3.0 mm outer layer, so a D-shape part goes in a **side wall**, not through the full stack.

### What is in the file

| Feature | Size | Position from the bore center |
|---|---:|---|
| Main bore | 24.0 mm | (0, 0) |
| Mounting hole | 3.1 mm | (-9.5, +12.0) |
| Mounting hole | 3.1 mm | (+9.5, +12.0) |
| Mounting hole | 3.1 mm | (+9.5, -12.0) |
| Mounting hole | 3.1 mm | (-9.5, -12.0) |

The four mounting holes sit on the corners of a **19.0 by 24.0 mm rectangle**. Overall extent is 24.0 by 27.1 mm. The 3.1 mm holes are sized for **M3** hardware, which is what the D series calls for.

### Why four mounting holes when the standard uses two

**A D-shape part is held by two screws on a diagonal, not four.** This file draws all four corners anyway, and that is deliberate.

Which diagonal a given part uses depends on how it is built and which way round it is fitted. Parts exist with the pair reversed, and a pass through that can be installed either way up is exactly the sort of thing that ends up rotated 180 degrees on the bench. Cutting one diagonal means committing to an orientation before you have the part in your hand.

Cutting all four takes both diagonals, so:

- **any D-shape part fits, either diagonal, either way up**
- you can rotate the part after the panel is cut, for cable clearance or for how the logo sits
- the two holes you do not use are 3.1 mm and hidden behind the connector flange

The cost is two extra small holes in a piece of acrylic that nobody will ever see. That is a trade worth making for a file meant to be universal.

If you would rather cut only the two you need, delete the other pair before sending the file. Everything is on one layer and each hole is a separate circle.

---

## E-Switch RR1 round rocker switch

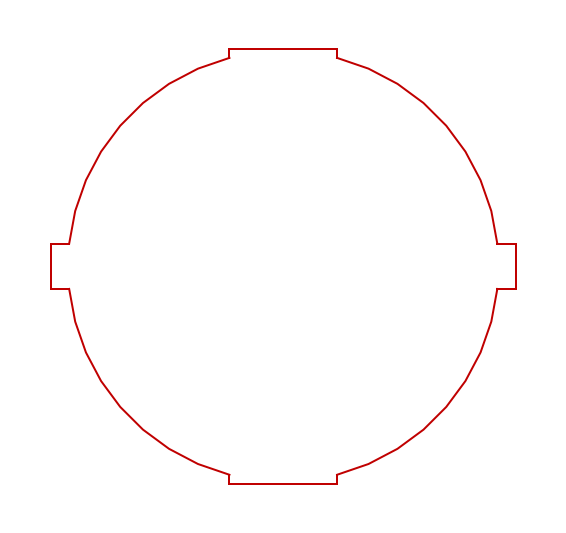
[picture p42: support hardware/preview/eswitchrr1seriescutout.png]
E-Switch RR1 series panel cutout


*One closed profile: a 20 mm bore with two anti-rotation slots and two shallow notches.*

The panel cutout for an **E-Switch RR1 series round rocker switch**, a snap in power rocker. On a fight stick it has two jobs worth doing, and which one you want decides which version of the switch to buy.

> "Round, Illuminated, Power Rocker Switch with PVC Cap"
>
> Panel mount snap in, with a circular **20 mm diameter panel cutout**. Up to 16 A at 125 VAC, SPST or SPDT, off-on / on-off-on / on-on latching, illuminated or not, and IP54 rated with the optional PVC cap.
>
> *E-Switch, [RR1 series product page](https://www.e-switch.com/product/rr1-series-round-illuminated-power-rocker-switch-with-pvc-cap/)*

### What to use it for

Both uses come out of the latching options quoted above. Buy the switch to match the job.

#### SPST, off-on: a lock for the auxiliary buttons

Start, Select, Home and Touchpad are the buttons you never want to catch mid match. Put the switch in their ground path and you can turn them off:

- **one side of the switch** takes the ground wires from Start, Select, Home, Touchpad and anything else you want locked out, tied together
- **the other side** takes a real ground back to the fight board

Switch on and those buttons work normally. Switch off and their ground path is broken, so none of them can register and an accidental press does nothing. Nothing about the signal wiring changes; the switch only ever interrupts the return.

> **Give the auxiliary buttons their own ground chain.** Most sticks daisy chain a single ground around every button on the panel. If your auxiliary buttons sit on that same chain, the switch will cut the action buttons along with them. Split it: action buttons on their own ground straight to the board, auxiliary buttons on a separate chain that runs through the switch.

The switch is carrying button ground, which is a signal level current nowhere near the RR1's 16 A rating. Choose one for the feel, the marking and the illumination rather than for the amps.

#### SPDT, on-off-on: a three position lever mode switch

The same cutout takes the three position version. **If your fight board supports it**, those three positions change what the lever reports: **D-pad**, **left stick** and **analog stick**. That is a mode a lot of players would rather have on the outside of the case than buried in a button combination.

Check your board's documentation before wiring this one. Boards differ on whether they expose a mode input at all and on what they expect to see on it, which is why this is an "if it supports it" rather than a given.

**It snaps in, so there are no mounting holes.** The switch body has retention barbs that grip the panel, which is why the cutout carries notches instead of screws. Check the switch's own panel thickness range against whatever you are cutting: a snap in needs the panel thin enough for the barbs to clear and thick enough to hold.

### What is in the file

One **closed profile**, not a set of separate holes. Every arc and line joins end to end, so a cutter follows it as a single path.

| Feature | Size |
|---|---|
| Bore | 20.0 mm diameter |
| Anti-rotation slots | 2 off, 2.1 mm wide, on the horizontal axis, out to a 21.6 mm span |
| Shallow notches | 2 off, 5.0 mm wide, on the vertical axis, out to a 20.2 mm span |

The two 2.1 mm slots are the ones that stop the switch turning in the hole. The two 5.0 mm notches are much shallower, 0.1 mm past the bore, and clear the body's molding.

**Orientation matters on this one.** The slots and notches are on different axes and different sizes, so the file is drawn the way the switch goes in. Rotating it 90 degrees will not fit. If you want the rocker to throw the other way, rotate the file 180 degrees, not 90.

---

## Using these with the case

The [case](../case/README.md) side walls are the natural home for a pass through. They are 55.0 mm across with a 45.0 mm body between the tab shoulders, so a 24 mm bore centered on that body leaves about 10.5 mm of material above and below it. Check that against your own layout before cutting, and remember that the wall is a **laminate**: the inner layer is 5.6 mm and the outer 3.0 mm, and a D-shape part is specified for a 1 to 3 mm panel.

The case already ships a `Neutrik_CenterSupport` printed part for mounting a D-shape connector on the center support rather than a wall. That is a different approach to the same problem, and which suits you depends on where your cable needs to come out.

The rocker is the easier of the two to place: it is a single 21.6 by 20.2 mm profile with no fasteners, so it drops into a side wall or a blank area of a panel wherever there is room behind it for the switch body and its terminals.

---

## About these files

The DXF is the original, drawn by JasensCustoms.com in SolidWorks, with the `.SLDPRT` source alongside it. The SVG and the preview are derived from that DXF rather than redrawn, and the cut geometry is verified entity for entity as unchanged when they are generated.

**No file here contains text of any kind.** Annotations belong on a drawing, not in a cut file, and a machine will happily engrave one that was left behind.

New hardware is welcome. A cutout needs to be true scale, in millimeters, with its origin on the main bore, and it needs a section here saying what hardware it fits and where the dimensions came from.

---

## License

Same as the rest of this repository: **CC BY-SA 4.0**. See [`../LICENSE`](../LICENSE).

Created by [JasensCustoms.com](https://www.jasenscustoms.com). Neutrik and E-Switch product names, and the specifications quoted above, belong to those manufacturers and are cited here only to identify what each cutout fits. Nothing of theirs is redistributed. Every dimension in these files was drawn by JasensCustoms.com and measured back out of the file itself, not lifted from a manufacturer drawing.

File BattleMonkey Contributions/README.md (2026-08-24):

# BattleMonkey contributions

Parts contributed by **BattleMonkey Custom Arcade Sticks**
([@XBattleMonkeyX](https://x.com/XBattleMonkeyX)). Thank you, BattleMonkey.

Like everything else in this repository, these files are shared under
[CC BY-SA 4.0](../LICENSE) — see [NOTICE.md](../NOTICE.md) for the attribution
register.

---

## Brook cable caddy — `caja brook cables v1.2`

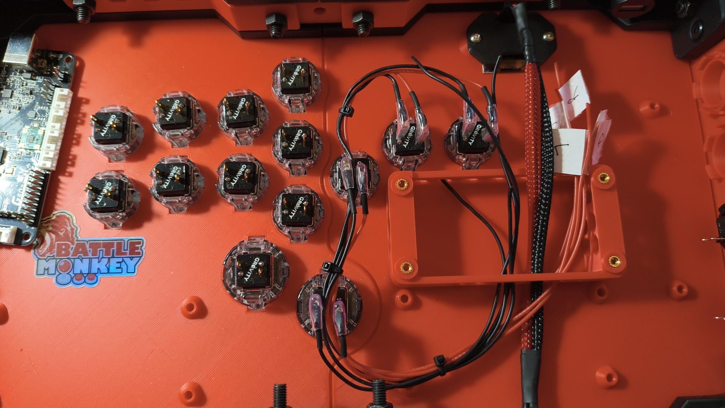
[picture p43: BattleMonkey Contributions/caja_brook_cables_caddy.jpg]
The cable caddy installed in a BattleMonkey build, framing the fight board area with sleeved cables routed past it


*The caddy installed in one of BattleMonkey's builds: the open frame sits on
the fight board mount points and the sleeved cable bundle routes cleanly past
it to the board.*

A 3D printed mounting caddy for a Brook fight board that doubles as cable
management: it holds the PCB on the case's mount points and gives the sleeved
cable bundle a clean, strain free path to the board terminals.

| | |
|---|---|
| Footprint | approx. 107.5 x 50 mm, 21 mm tall |
| Mounts to | the four PCB mount points on the plexi case's inner layer |
| Inserts | 8x M3 x 5 mm heat set inserts |
| Files | [`caja brook cables v1.2.STEP`](caja%20brook%20cables%20v1.2.STEP) (AP203) &middot; [`caja brook cables v1.2.SLDPRT`](caja%20brook%20cables%20v1.2.SLDPRT) (SolidWorks 2022) |

### Printing and installing

1. Print the caddy. No STL is provided yet; export one from the STEP or
   SLDPRT at your slicer's preferred settings.
2. Heat press the eight M3 x 5 mm inserts into the bosses.
3. Bolt the caddy to the four PCB mount points on the inner layer of the
   [plexi case](../case/README.md), then mount the fight board to the caddy.
4. Route the sleeved cables through the frame to the board.

### Planned updates

- A variant that mounts on only the two inner M3 points.
- Boss sizing for standard Ruthex M3 heat set inserts.

If you build with it, photos in the
[issues](https://github.com/JasensCustoms/FightStickLayoutProject/issues) are
always welcome.

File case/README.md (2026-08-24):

# Plexi and 3D printed case

> ## Not yet validated
>
> **As of August 22, 2026, none of these files has been cut, printed or test
> assembled.** The geometry is published as designed, and the numbers in this
> document are measured from the files themselves, but no physical build has
> confirmed that the parts fit together.
>
> Treat everything here as a first release. Cut one of anything before you cut
> six, and expect the tolerances to be the first thing that needs adjusting.
>
> Once a build has been completed this page will be updated to say so, with
> photographs of the assembled case and a list of recommended vendors for the raw
> plexi.

A laser cut acrylic case with 3D printed corner and center supports, sized to take
any of the control panel layouts in the [main repository](../README.md).

Everything here is millimeters. DXF files are the flat cut profiles; STL and STEP
are the printed parts; SLDPRT are the SolidWorks sources.

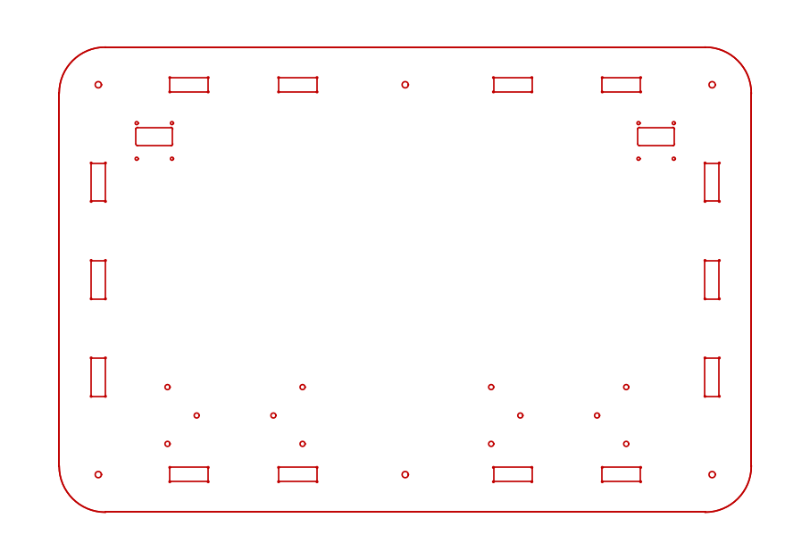
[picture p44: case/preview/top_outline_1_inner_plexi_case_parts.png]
Top outline 1, inner layer
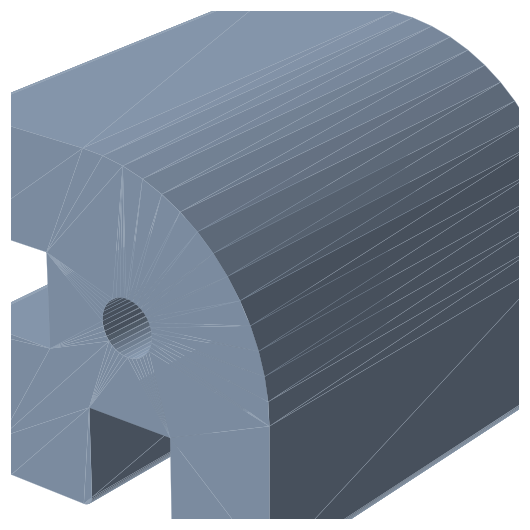
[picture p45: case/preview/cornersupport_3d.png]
Corner support
 

## The case at a glance

| | |
|---|---|
| **Footprint** | **451.0 x 303.0 mm** (17.76 x 11.93 in), 30 mm corner radius |
| **Internal height** | **45.0 mm**, set by the supports and the wall shoulders |
| **Overall height** | **62.2 mm**, being 45 plus an inner and outer layer top and bottom |
| **Inner acrylic** | **5.6 mm** extruded, tolerance +/- 10 to 15 percent (5.2 to 6.0) |
| **Outer acrylic** | **3.0 mm** extruded, tolerance +/- 10 percent (2.7 to 3.30) |
| **Fasteners** | M4, into heat set inserts in the printed supports |

The 451 x 303 mm footprint has room for every layout in this repository several
times over. The largest cut envelope in the library is 278.2 x 151.7 mm.

## Bill of materials

**Acrylic, 16 pieces:**

| Qty | Part | Thickness | File |
|---:|---|---|---|
| 1 | Top, inner layer | 5.6 mm | `Top - Outline N - Inner` |
| 1 | Top, outer layer | 3.0 mm | `Top - Outline N - Outer`, same N |
| 1 | Bottom, inner layer | 5.6 mm | `Bottom - Outline N - Inner` |
| 1 | Bottom, outer layer | 3.0 mm | `Bottom - Outline N - Outer`, same N |
| 4 | Short side, inner | 5.6 mm | `Short Side - JCC`, plain or a button variant |
| 4 | Short side, outer | 3.0 mm | `Short Side - JCC`, plain or a button variant |
| 2 | Long side, inner | 5.6 mm | `Long Side - JCC`, plain or a button variant |
| 2 | Long side, outer | 3.0 mm | `Long Side - JCC`, plain or a button variant |

**Inner and outer are different files for the top and bottom**, and the difference
is the fourteen wall slots. Only the inner layer carries them. See below.

**Printed, 6 pieces:**

| Qty | Part | Files |
|---:|---|---|
| 4 | Corner support | `CornerSupport.STL` / `.STEP` / `.SLDPRT` / `.DXF` |
| 1 | Blank center support | `Blank_CenterSupport.STL` / `.STEP` / `.SLDPRT` / `.DXF` |
| 1 | Neutrik center support | `Neutrik_CenterSupport.STL` / `.STEP` / `.SLDPRT` |
| 0 to 2 | Fight board bracket, optional | `FightBoardBracket.STL` / `.STEP` |

**Each support comes in three fits**, and the file above is the loosest of them.
Measure your acrylic and pick the one that matches before you print; see
[Three fits](#three-fits-because-the-acrylic-has-a-tolerance).

**Hardware:**

| Qty | Item |
|---:|---|
| 12 | M4 brass heat set inserts, [ruthex RX-M4x8.1](https://www.amazon.com/dp/B07YSV66Y5) or equivalent |
| 12 | M4 screws, length to suit your stack |

Per [fight board bracket](#fight-board-bracket), if you print one:

| Qty | Item |
|---:|---|
| 4 | M3 brass heat set inserts, [ruthex RX-M3x5.7](https://www.amazon.com/ruthex-M3-Threaded-Inserts-RX-M3x5-7/dp/B08BCRZZS3) |
| 2 | M3 SHORT brass heat set inserts, [ruthex RX-M3Sx4.0](https://www.amazon.com/ruthex-Threaded-Inserts-Short-RX-M3Sx4-0/dp/B09ZHSGHXD) |
| 2 | M3 flat head screws, **10 mm**, panel down into the bracket base |
| 4 | M3 pan head screws, **8 mm**, board up into the pillars |

Two inserts per support, one in each end of its 5.6 mm through bore, which is why
the panels carry six 4.1 mm clearance holes each: four corners and two centers,
top and bottom.

You will also want flat head screws for whatever you mount to the top inner panel,
a fight board and up to two OLED screens. **Countersink those holes after cutting**
so the heads sit below the surface and the outer layer can lie flat on top.

## Print settings

PETG, **5 wall loops**. The supports carry the whole case and take the insert
heat, so wall count matters more than infill here.

## The parts

### Top and bottom panels

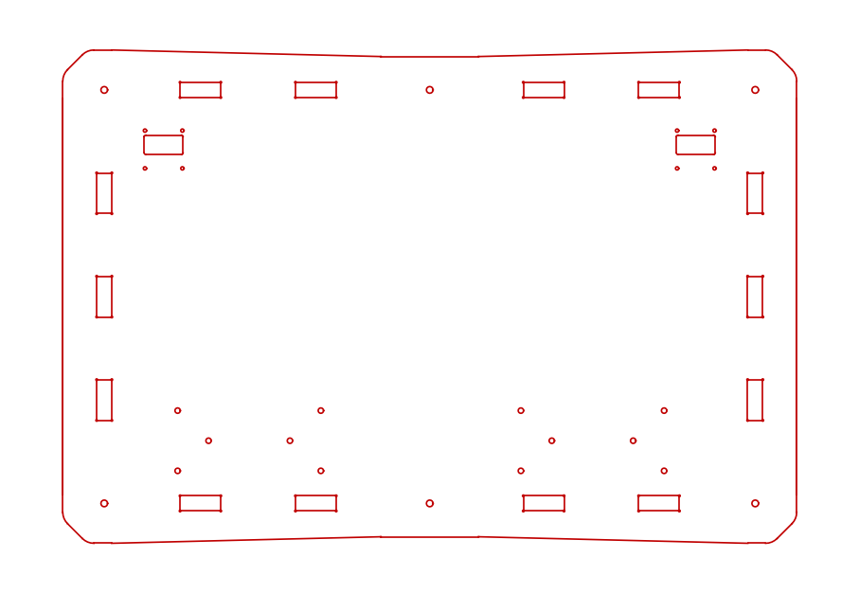
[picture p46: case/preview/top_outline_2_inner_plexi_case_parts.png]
Top outline 2, inner layer
Top outline 1, inner layer 

*Left: Outline 1. Right: Outline 2.*

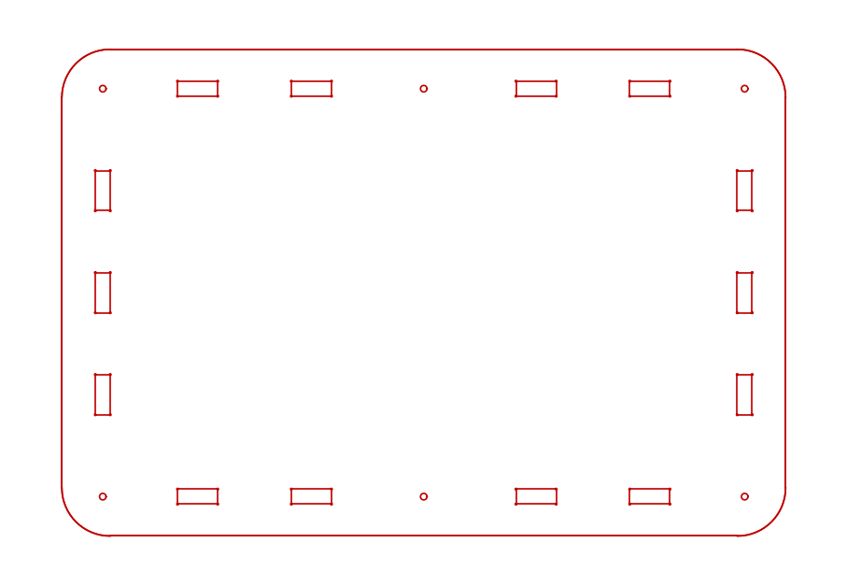
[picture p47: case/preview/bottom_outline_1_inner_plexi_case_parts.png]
Bottom outline 1, inner layer
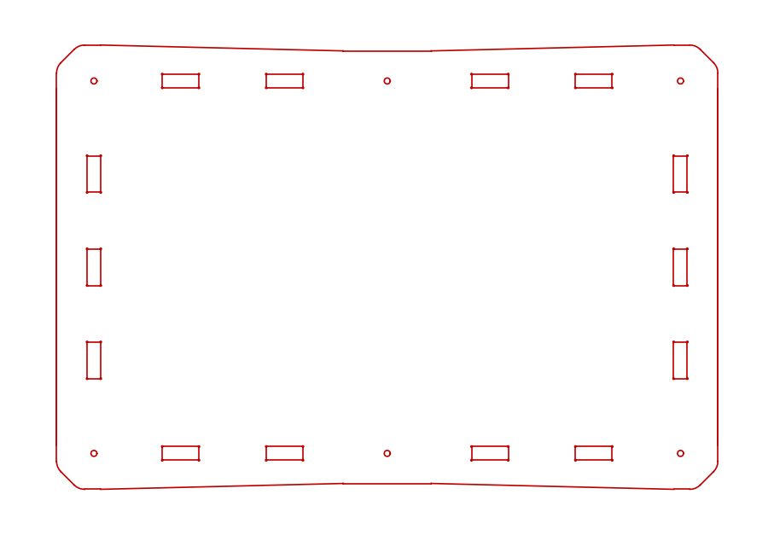
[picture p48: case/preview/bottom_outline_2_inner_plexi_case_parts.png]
Bottom outline 2, inner layer
 

*The matching bottoms. Left: Outline 1. Right: Outline 2.*

**Outline 1 and Outline 2 are the same panel with a different silhouette.** Both
are exactly 451.0 x 303.0 mm with a 30 mm corner radius, and every hole and slot
in them is in the same place to the last decimal. The only difference is the front
and back edge: Outline 1 runs straight across, Outline 2 bows gently outward, so
at 210 mm from center Outline 1 measures 298.285 mm front to back and Outline 2
measures 302.902. Pick the look you want and cut it in both thicknesses.

The bottom inner panel carries the six 4.1 mm mounting holes and the wall slots.
The top inner panel carries those plus:

| Feature | Count | What it is |
|---|---:|---|
| 4.1 mm clearance holes | 6 | the four corner and two center supports |
| 3.3 mm holes | 12 | two fight board mounting clusters of six |
| 2.0 mm holes | 8 | two OLED screen mounts of four |
| 23.9 x 11.9 mm cutouts | 2 | the OLED windows those four fixings surround |

**The cutouts and the 2.0 mm holes take a 0.96 in OLED screen.** There are two
sets, left and right. Cut the side you want and leave the other out, or cut both
if you want a screen at each end.

**The 3.3 mm clusters mount a fight board.** There are two of them for the same
reason: cut both if you like, but only one side is needed. Each cluster is an
**88.0 x 37.0 mm** rectangle of four, with two more **50.0 mm** apart on that
rectangle's centerline, 19.0 mm in from each end. Both clusters are the same
pattern, so anything that fits one fits the other.

The four outer holes are the board's own mounting pattern, for bolting it straight
to the panel on standoffs of your choosing. **The two inner holes are for the
[fight board bracket](#fight-board-bracket) below**, which is the printed
alternative.

All four features are **inner layer only**; see the outer layer note below.

> **Countersink every 2.0 and 3.3 mm hole on the inner panels after cutting**, so
> a flat head screw sits below the surface of the plexi. The outer layer lies
> straight on top of the inner one, and a screw head standing proud will hold the
> two apart.

**Wall slots, and why the outer layer has none.** Three 10.3 x 26 mm slots on each
303 mm edge and four 26 x 10.3 mm slots on each 451 mm edge, fourteen in all. The
10.3 mm width takes the laminated wall, nominally 5.6 plus 3.0 equals 8.6 mm, and
still fits at the worst end of both material tolerances, 6.0 plus 3.3 equals 9.3.

The wall tab is 5.0 mm long and the inner layer is 5.6 mm, so the tab stops 0.6 mm
short of the inner layer's outer face and the outer layer caps it. **The outer
layer therefore must not be cut with those fourteen slots**, which is what the
`- Outer` files are for:

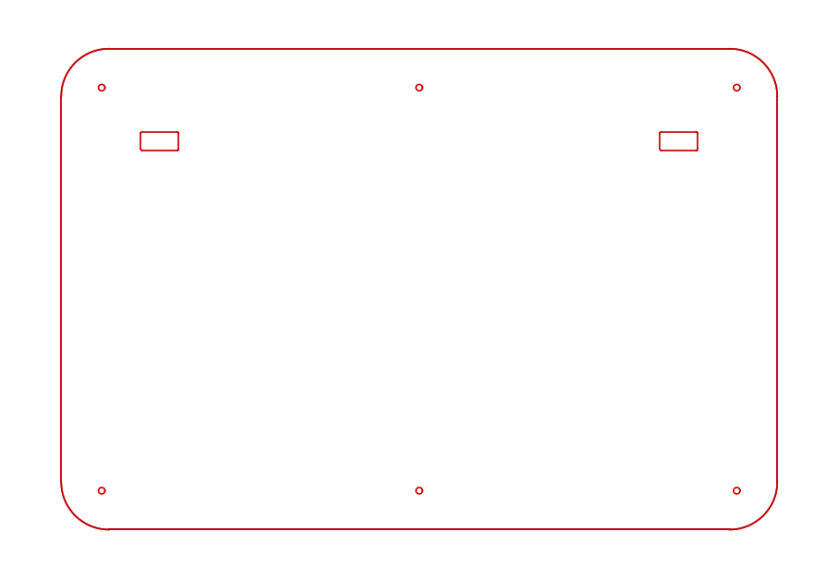
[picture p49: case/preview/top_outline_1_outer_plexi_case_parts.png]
Top outline 1, outer layer
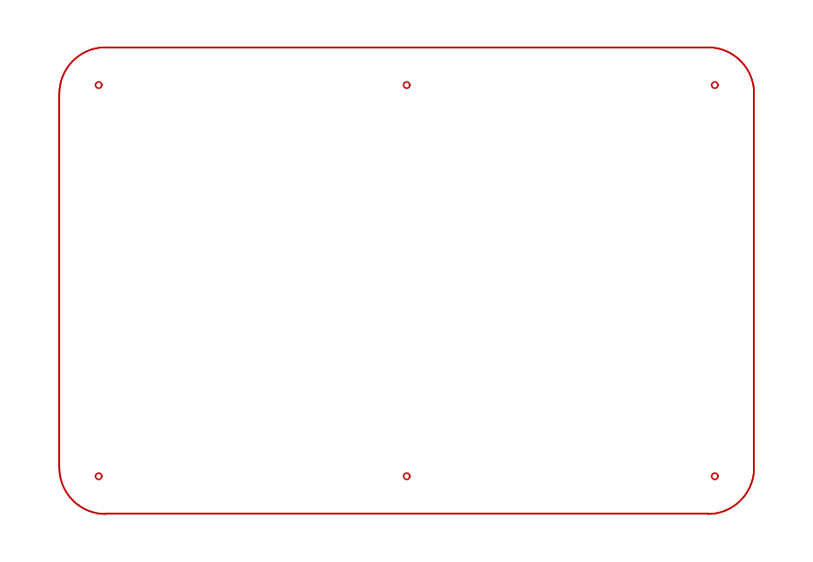
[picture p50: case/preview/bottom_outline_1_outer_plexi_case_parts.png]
Bottom outline 1, outer layer
 

*The outer layers. Left: top. Right: bottom. Same silhouette, the six mounting
holes, and on the top the two connector apertures. Nothing else.*

**The top outer layer also drops the small holes.** The twelve 3.3 mm fight board
mounts and eight 2.0 mm OLED mounts fix hardware to the underside of the top
panel, and their countersunk screw heads sit below the inner layer's surface, so
the 3.0 mm cosmetic layer above them stays solid. Twenty holes plus fourteen slots
come out and the top outer panel goes from 170 entities to 38. The **two
23.9 x 11.9 mm OLED windows stay**, because you have to see the screen.

| Feature | Top inner | Top outer | Bottom inner | Bottom outer |
|---|---:|---:|---:|---:|
| Silhouette | yes | yes | yes | yes |
| Wall slots | 14 | none | 14 | none |
| 4.1 mm mounting holes | 6 | 6 | 6 | 6 |
| 3.3 mm holes | 12 | none | none | none |
| 2.0 mm holes | 8 | none | none | none |
| 23.9 x 11.9 mm OLED windows | 2 | 2 | none | none |

Every outer file is its matching inner with those features deleted and nothing
else touched. Both outlines have an outer version of each panel.

| Layer | Outline 1 | Outline 2 |
|---|---|---|
| Top, inner 5.6 mm | `Top - Outline 1 - Inner - Plexi Case Parts.DXF` | `Top - Outline 2 - Inner - Plexi Case Parts.DXF` |
| Top, outer 3.0 mm | `Top - Outline 1 - Outer - Plexi Case Parts.DXF` | `Top - Outline 2 - Outer - Plexi Case Parts.DXF` |
| Bottom, inner 5.6 mm | `Bottom - Outline 1 - Inner - Plexi Case Parts.DXF` | `Bottom - Outline 2 - Inner - Plexi Case Parts.DXF` |
| Bottom, outer 3.0 mm | `Bottom - Outline 1 - Outer - Plexi Case Parts.DXF` | `Bottom - Outline 2 - Outer - Plexi Case Parts.DXF` |

### Side walls

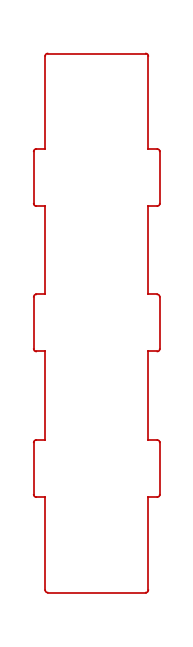
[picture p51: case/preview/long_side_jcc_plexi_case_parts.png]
Long side
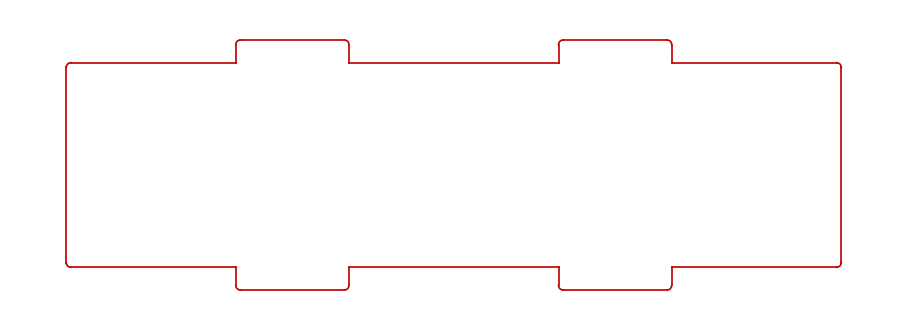
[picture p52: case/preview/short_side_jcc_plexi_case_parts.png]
Short side
 

| Part | Size | Tabs |
|---|---|---|
| Long side | 55.0 x 235.402 mm | 3 per edge, into the 303 mm panel edges |
| Short side | 170.5 x 55.0 mm | 2 per edge, two pieces per 451 mm panel edge |

The plain walls are the same file for both layers: they carry no slots, so the
inner and outer cut identically. The **button variants below** are the exception.

Both walls are **55.0 mm** across, made of a **45.0 mm** body between the tab
shoulders and a **5.0 mm** tab at each end. The 45 mm body is what sets the
internal height, and it matches the printed supports exactly. The 5 mm tab enters
the 5.6 mm inner layer and stops 0.6 mm short of its outer face, where the 3.0 mm
outer layer caps it.

### Side walls with buttons

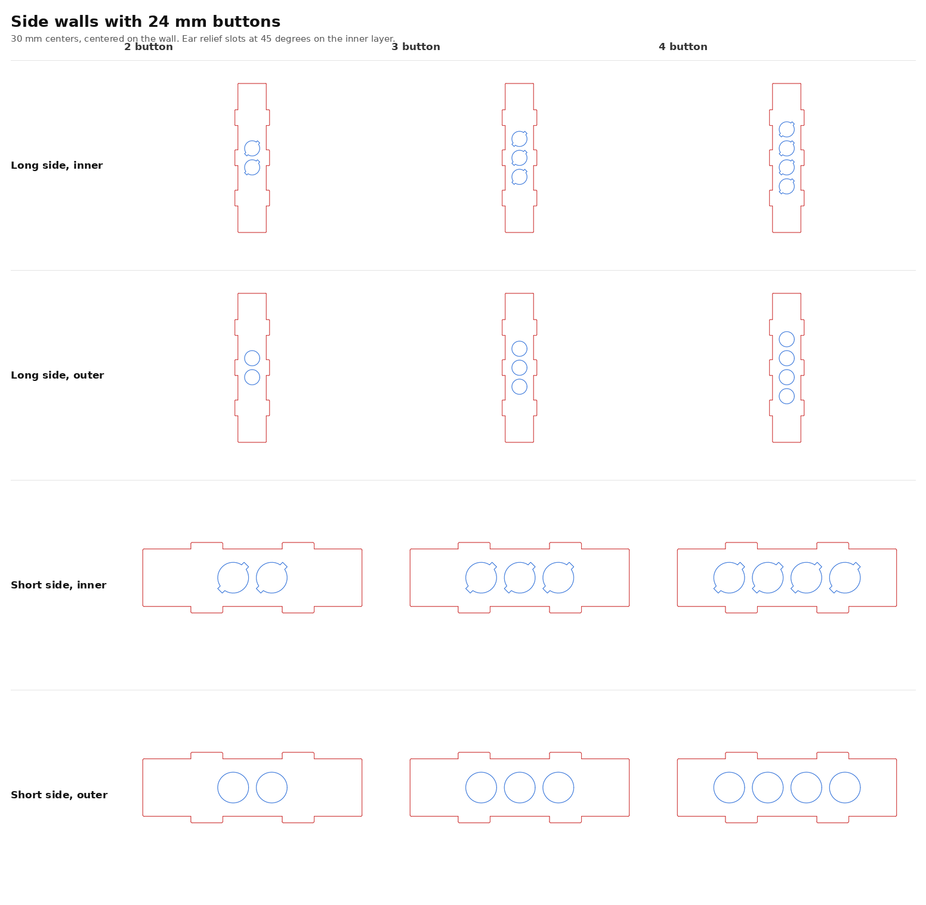
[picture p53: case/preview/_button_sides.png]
Side walls with buttons


Both walls come in variants carrying **24 mm buttons at 30 mm centers**, in twos,
threes and fours, centered on the wall in both directions. Twelve files in all.

| | 2 button | 3 button | 4 button |
|---|---|---|---|
| **Long side, inner** | [dxf](Long%20Side%20-%20JCC%20-%202%20Button%20Inner%20-%20Plexi%20Case%20Parts.DXF) | [dxf](Long%20Side%20-%20JCC%20-%203%20Button%20Inner%20-%20Plexi%20Case%20Parts.DXF) | [dxf](Long%20Side%20-%20JCC%20-%204%20Button%20Inner%20-%20Plexi%20Case%20Parts.DXF) |
| **Long side, outer** | [dxf](Long%20Side%20-%20JCC%20-%202%20Button%20Outer%20-%20Plexi%20Case%20Parts.DXF) | [dxf](Long%20Side%20-%20JCC%20-%203%20Button%20Outer%20-%20Plexi%20Case%20Parts.DXF) | [dxf](Long%20Side%20-%20JCC%20-%204%20Button%20Outer%20-%20Plexi%20Case%20Parts.DXF) |
| **Short side, inner** | [dxf](Short%20Side%20-%20JCC%20-%202%20Button%20Inner%20-%20Plexi%20Case%20Parts.DXF) | [dxf](Short%20Side%20-%20JCC%20-%203%20Button%20Inner%20-%20Plexi%20Case%20Parts.DXF) | [dxf](Short%20Side%20-%20JCC%20-%204%20Button%20Inner%20-%20Plexi%20Case%20Parts.DXF) |
| **Short side, outer** | [dxf](Short%20Side%20-%20JCC%20-%202%20Button%20Outer%20-%20Plexi%20Case%20Parts.DXF) | [dxf](Short%20Side%20-%20JCC%20-%203%20Button%20Outer%20-%20Plexi%20Case%20Parts.DXF) | [dxf](Short%20Side%20-%20JCC%20-%204%20Button%20Outer%20-%20Plexi%20Case%20Parts.DXF) |

**Inner and outer follow the same rule as the layouts in the main repository.**
The button passes through both sheets, so the outer layer gets a plain 24 mm hole
and the inner layer gets that hole merged with a Sanwa OBSF ear relief slot,
5 x 29 mm, as a single closed profile. Cut it as one contour.

**The ear slots sit at 45 degrees**, not the 60 the rest of the library uses, and
that was solved rather than picked. At 45 the slot corners tuck almost inside the
hole's own bounding box in both axes at once, which makes it the only angle in the
15 degree family that holds the full web between neighbors **and** the most
material to the top and bottom edges of the wall:

| Slot angle | Web between buttons | To the wall edge |
|---|---:|---:|
| 0 or 90 degrees | 1.000 mm | 10.500 mm |
| 60 or 120 degrees | 6.000 mm | 8.693 mm |
| **45 or 135 degrees** | **5.958 mm** | **10.479 mm** |

Every variant measures **5.958 mm** between adjacent profiles and **10.479 mm**
from a profile to the long edges of the wall. End clearance is generous
throughout: the tightest is the four button short side at **28.229 mm** from the
outermost profile to the end of the wall, and each end of a short side is buried
about 4.8 mm inside a support, so there is plenty left over.

> **Check your buttons against the stack.** Inner plus outer is 8.6 mm of acrylic.
> The ear relief lets the retention ears pass through and spring out underneath,
> which is the whole point of it, but 8.6 mm is at the deep end for a snap in.
> Cut one wall in scrap and try a button before committing to four.

### Fight board bracket

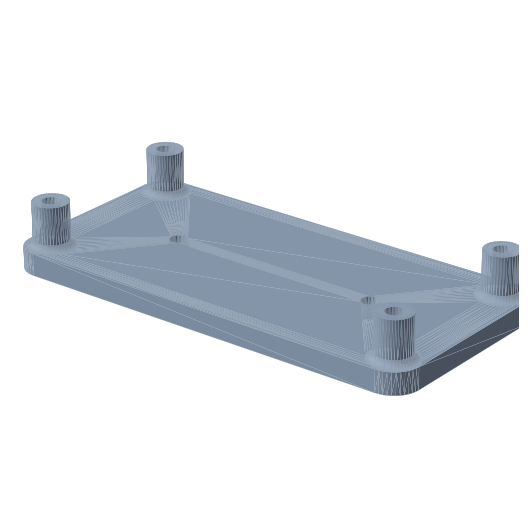
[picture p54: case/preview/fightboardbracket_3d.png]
Fight board bracket


A printed standoff plate that turns one 3.3 mm cluster into a fight board mount.
It bolts to the underside of the top inner panel and holds the board 10 mm clear
of it, so no loose standoffs are needed and nothing shows on the outside of the
case. Optional, and one per board.

| | |
|---|---|
| **Envelope** | 100.0 x 49.0 x 15.0 mm |
| **Base** | 100.0 x 49.0 x 5.0 mm plate, 6 mm corner radius |
| **Pillars** | 4 off, 8.0 mm diameter, 10.0 mm tall, on 88.0 x 37.0 mm centers |
| **Board standoff** | 10.0 mm below the panel |
| **Print** | PETG, 5 wall loops, base down and pillars up, no supports |
| **Files** | `FightBoardBracket.STL`, `FightBoardBracket.STEP` |

**Which panel holes it uses.** The two inner holes of the cluster, the ones
50.0 mm apart. The four outer holes are the alternative, for bolting a board
straight to the panel on standoffs of your own, and they go unused when the
bracket is fitted.

#### Threaded inserts

Both are heat set. The four pillar bores are blind, 7.0 mm deep; the two base
bores go straight through the plate.

| Qty | Insert | Goes in |
|---:|---|---|
| 4 | [ruthex RX-M3x5.7](https://www.amazon.com/ruthex-M3-Threaded-Inserts-RX-M3x5-7/dp/B08BCRZZS3) | the top of each pillar |
| 2 | [ruthex RX-M3Sx4.0 SHORT](https://www.amazon.com/ruthex-Threaded-Inserts-Short-RX-M3Sx4-0/dp/B09ZHSGHXD) | the base, from the face that meets the panel |

Both bores are 4.0 mm. ruthex publishes that figure for the RX-M3x5.7 and does not
publish one for the short insert, so check the short one against your parts before
committing to a print.

#### Screws you need to supply

**4 x M3 pan head, 8 mm**, and **2 x M3 flat head, 10 mm.**

| Qty | Screw | Length | Where it goes |
|---:|---|---|---|
| 2 | M3 flat head, countersunk | **10 mm** | down through the top inner panel into the base |
| 4 | M3 pan head | **8 mm** | up through the board into the pillars |

The **flat heads** are what the countersinks in the top inner panel are for. At
10 mm they take up the full 4.0 mm of the short insert across the whole thickness
tolerance of 5.6 mm plexi, and their heads finish below the panel surface so the
3.0 mm outer layer lies flat on top. 8 mm is too short and only reaches half way
into the insert.

The **pan heads** come up from underneath through a 1.6 mm board and take 6.4 mm
of the 5.7 mm pillar insert. **Do not go longer than 8 mm**: the pillar bore is
7.0 mm deep, so a 10 mm screw bottoms out and holds the board off the pillar
instead of pulling it down.

### Printed supports

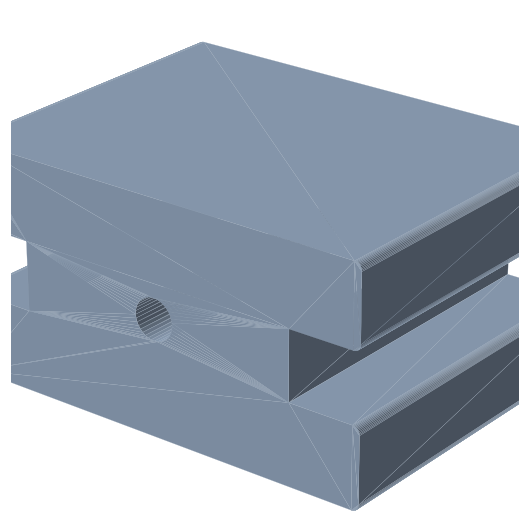
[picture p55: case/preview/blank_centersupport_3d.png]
Blank center support
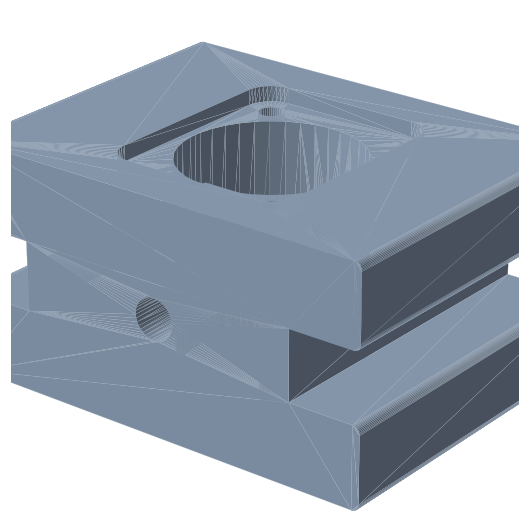
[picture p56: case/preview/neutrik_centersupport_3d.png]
Neutrik center support
Corner support  

*Left to right: corner, blank center, Neutrik center.*

| Part | Size | Notes |
|---|---|---|
| Corner support | 34.599 x 45.0 x 34.599 mm | L shaped, outer corner radiused to match the panel |
| Blank center support | 60.0 x 45.0 x 31.0 mm | mid span on each 451 mm edge |
| Neutrik center support | 60.0 x 45.0 x 31.0 mm | same outside, with a 24 x 24 mm aperture through it |

All three are a straight 45 mm extrusion of a single profile, with one 5.6 mm bore
running the full length for the heat set inserts. The Neutrik version adds a
24 x 24 mm opening for a Neutrik D series panel connector; it is otherwise
identical to the blank.

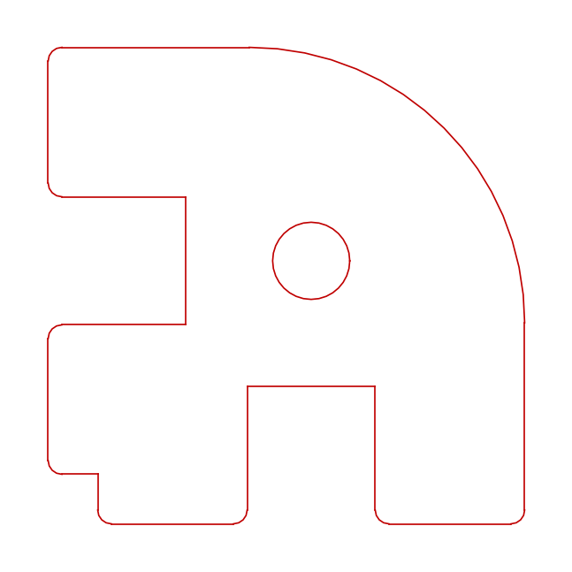
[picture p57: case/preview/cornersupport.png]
Corner support profile
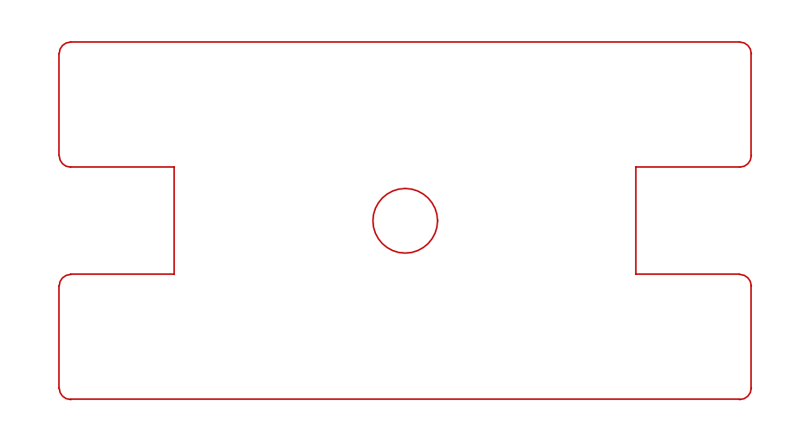
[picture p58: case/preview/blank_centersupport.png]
Blank center support profile
 

*The two profiles that ship as DXF. Left: corner. Right: blank center.*

**The corner and blank center supports also ship as DXF**, because that profile is
all they are. If you would rather laminate them from acrylic offcuts than print
them, cut the profile and stack it to 45 mm. The Neutrik support has no DXF,
because its aperture is an internal feature that a single profile cannot describe.

### Three fits, because the acrylic has a tolerance

The supports grip the wall in a slot, and the wall is a **laminate**: a 5.6 mm
inner layer and a 3.0 mm outer layer, each with its own tolerance. Work the stack
through and the wall can arrive anywhere in a 1.4 mm band:

| | Inner | Outer | Wall |
|---|---:|---:|---:|
| Thinnest | 5.2 | 2.7 | **7.9 mm** |
| Nominal | 5.6 | 3.0 | **8.6 mm** |
| Thickest | 6.0 | 3.30 | **9.3 mm** |

So the supports come in three fits, differing **only** in the width of that slot.
Same envelope, same insert bore, same everything else.

| Fit | Slot opening | Print this when |
|---|---:|---|
| As supplied, no suffix | **9.3 mm** | you do not know what your acrylic measures. Cut for the thickest the stack can be, so it always goes together |
| `_NominalFit` | **8.6 mm** | your acrylic measures on the nominal 5.6 and 3.0 |
| `_TightFit` | **8.2 mm** | your acrylic came in thin, or you want the wall gripped rather than located |

Every one of those numbers is measured back out of the shipped model, and the
slot runs the full 45 mm through the part with a small lead in at each mouth so
the wall starts square.

> **Availability:** `_NominalFit` ships for all three supports. `_TightFit`
> currently ships for the blank center support only; the Neutrik center and
> corner versions will follow.

**Measure your acrylic before you print.** A caliper on an offcut of each layer
takes a moment and tells you which one to run. If you are between two, print the
looser: a support that is a little slack still locates the wall, and one that is
too tight will not seat at all, or will split along the print layers when you
force it.

Which fits ship today:

| Part | As supplied, 9.3 | Nominal, 8.6 | Tight, 8.2 |
|---|---|---|---|
| Corner support | yes | yes | not yet |
| Blank center support | yes | yes | yes |
| Neutrik center support | yes | yes | not yet |

The two missing tight variants are being drawn. Until they are here, print the
nominal and check the fit on a test piece.

## What is not here

Stated plainly so nobody hunts for something that was never in the folder:

- **`Neutrik_CenterSupport.DXF`** does not exist. Its aperture is an internal
  feature, and a single extrusion profile cannot describe it.
- **Countersink depth** is not in the files. It depends on the flat head screws you
  use, and the DXFs carry the through holes only.
- **Assembly order and screw lengths for the case itself** depend on your final
  stack thickness, which moves with the material tolerance, so measure before you
  buy screws. The bracket's screw lengths are given above and do not move.

## About these files

Eight of the DXFs came straight out of SolidWorks and keep their original
filenames exactly as they came. The other sixteen, the four outer panels and the
twelve button walls, are generated from those eight: features are deleted or added
and the rest of the geometry is carried across untouched, so a wall in a button
variant is the same wall, not a redrawn one.

The fight board bracket is the exception, being modeled rather than derived. Its
mounting pattern is measured off `Top - Outline 1 - Inner - Plexi Case Parts.DXF`,
not assumed, and the exported STL is checked for watertightness and consistent
winding, against the solid's own volume, and by firing a ray through every bore to
confirm its position and depth.

**The SolidWorks sources ship too**, five `.SLDPRT` files.
`All Plexi Case Parts.SLDPRT` is the multibody source for the set.
`CornerSupport.SLDPRT`, `Blank_CenterSupport.SLDPRT` and
`Neutrik_CenterSupport.SLDPRT` are the printed parts, each with a neutral STEP and
STL beside it. `Top Panel.SLDPRT` is the one with no neutral companion, so it is
only usable in SolidWorks.

## License

Same as the rest of this repository: **Creative Commons Attribution-ShareAlike 4.0
International**. See [LICENSE](../LICENSE) and [NOTICE.md](../NOTICE.md).

These case files were created by [JasensCustoms.com](https://www.jasenscustoms.com).

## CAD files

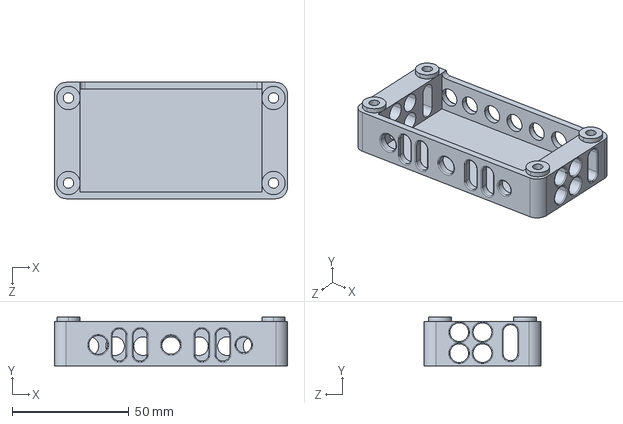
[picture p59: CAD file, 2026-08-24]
BattleMonkey Contributions/caja brook cables v1.2.STEP
100.0 x 21.0 x 50.0 mm

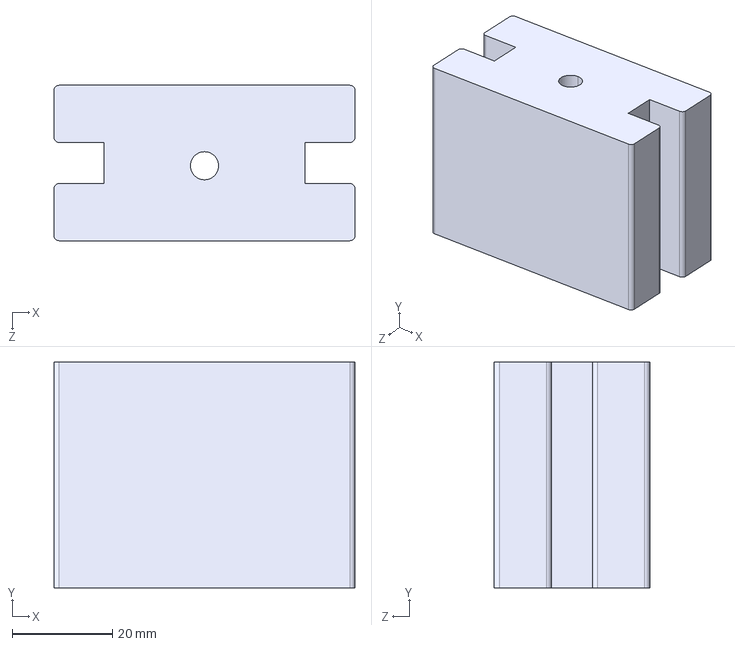
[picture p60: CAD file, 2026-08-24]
case/Blank_CenterSupport_TightFit.STEP
60.0 x 45.0 x 31.0 mm

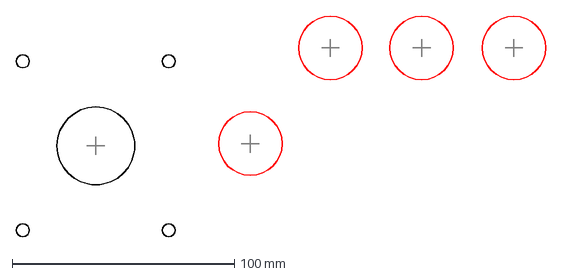
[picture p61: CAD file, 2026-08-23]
dxf/inner_support_neogeo_mvs_type2_american_parts.dxf
238.0 x 99.2 mm

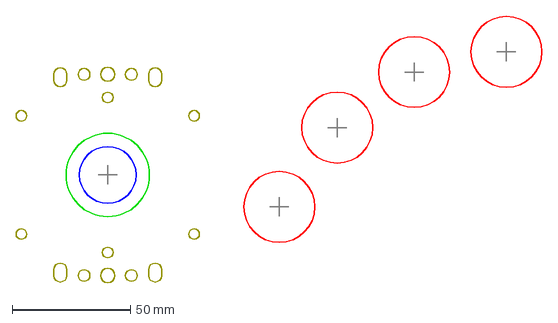
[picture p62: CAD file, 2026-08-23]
dxf/neogeo_mini_japanese_parts.dxf
222.2 x 112.5 mm

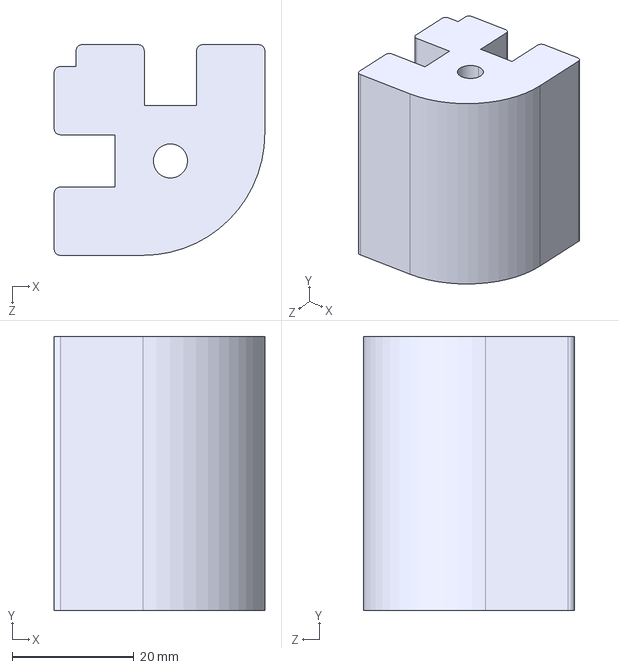
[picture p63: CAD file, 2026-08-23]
case/CornerSupport_NominalFit.STEP
34.6 x 45.0 x 34.6 mm

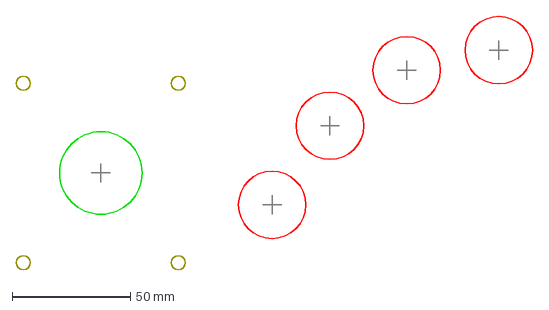
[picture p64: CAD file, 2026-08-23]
dxf/neogeo_mini_american_parts.dxf
218.5 x 107.2 mm

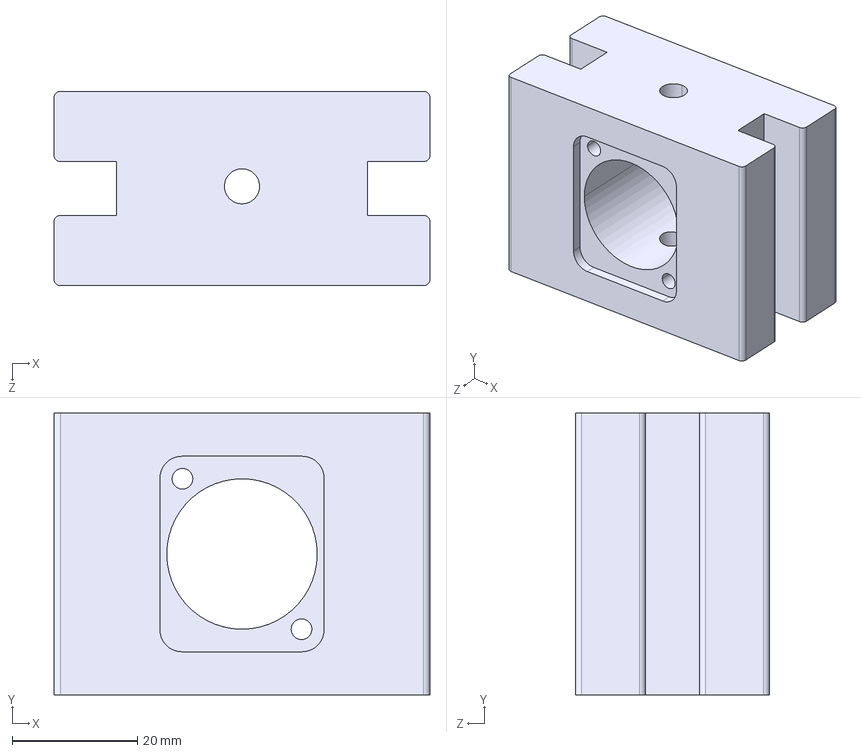
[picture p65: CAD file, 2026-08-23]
case/Neutrik_CenterSupport_NominalFit.STEP
60.0 x 45.0 x 31.0 mm

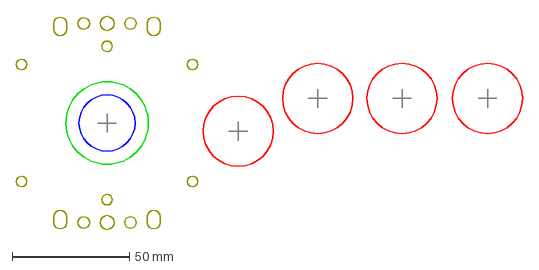
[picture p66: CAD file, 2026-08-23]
dxf/neogeo_mvs_u4_japanese_parts.dxf
216.2 x 91.0 mm

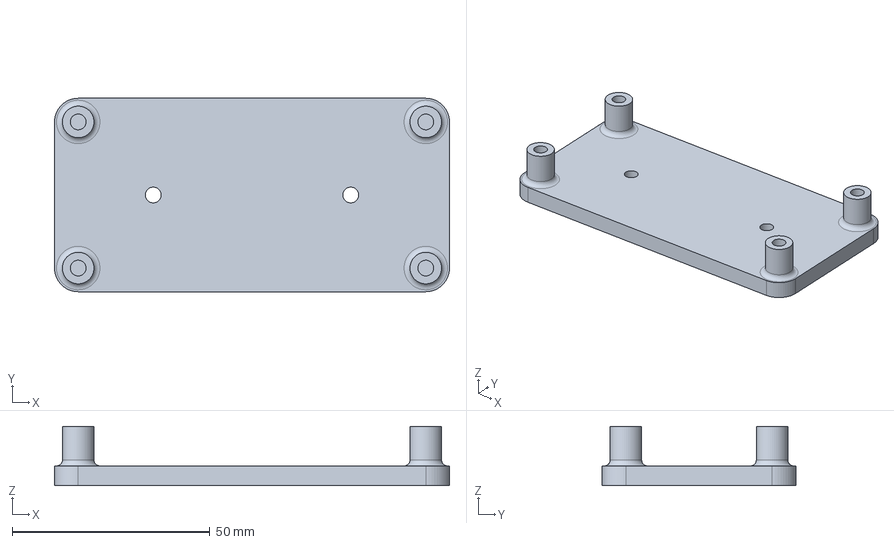
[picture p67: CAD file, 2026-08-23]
case/FightBoardBracket.STEP
100.0 x 49.0 x 15.0 mm

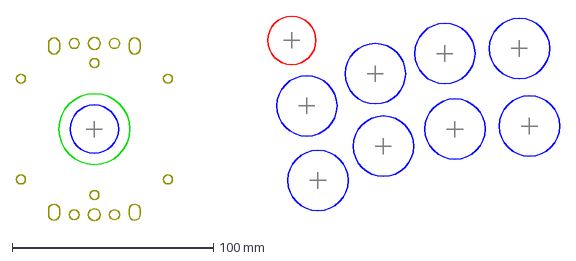
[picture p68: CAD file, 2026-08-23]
dxf/ist_type1_japanese_parts.dxf
269.8 x 101.5 mm

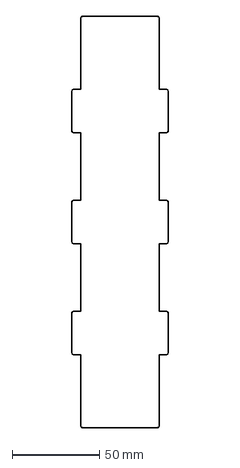
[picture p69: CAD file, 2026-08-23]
case/Long Side - JCC - Plexi Case Parts.DXF
55.0 x 235.4 mm

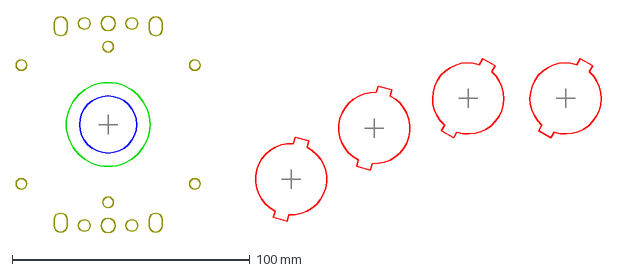
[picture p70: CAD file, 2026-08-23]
dxf/inner_support_neogeo_mvs_type1_japanese_parts.dxf
247.8 x 91.0 mm

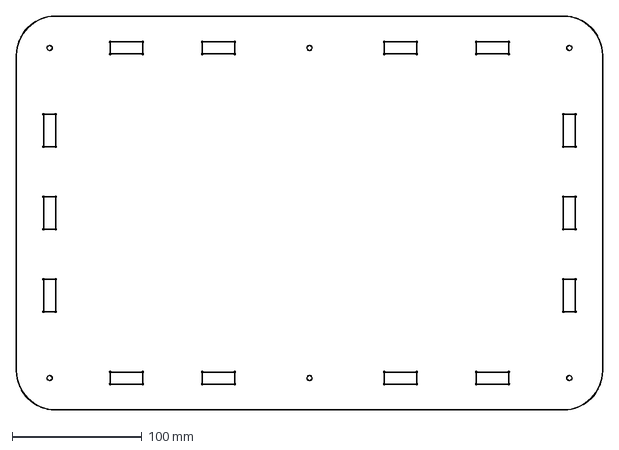
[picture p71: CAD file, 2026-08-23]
case/Bottom - Outline 1 - Inner - Plexi Case Parts.DXF
451.0 x 303.0 mm

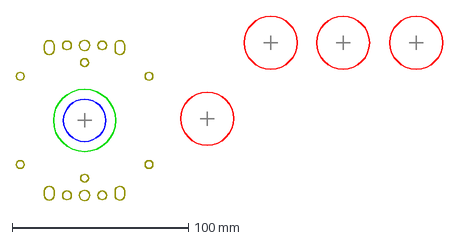
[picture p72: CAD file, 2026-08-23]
dxf/neogeo_mvs_type2_japanese_parts.dxf
241.8 x 104.5 mm

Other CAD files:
support hardware/NeutrikCutout.SLDPRT
case/Blank_CenterSupport_NominalFit.STEP
support hardware/ESwitchRR1SeriesCutout.SLDPRT
case/Short Side - JCC - Plexi Case Parts.DXF
BattleMonkey Contributions/caja brook cables v1.2.SLDPRT
case/All Plexi Case Parts.SLDPRT
case/Blank_CenterSupport.DXF
case/Blank_CenterSupport.SLDPRT
case/Blank_CenterSupport.STEP
case/Blank_CenterSupport.STL
case/Blank_CenterSupport_NominalFit.SLDPRT
case/Blank_CenterSupport_NominalFit.STL
case/Blank_CenterSupport_TightFit.SLDPRT
case/Blank_CenterSupport_TightFit.STL
case/Bottom - Outline 1 - Outer - Plexi Case Parts.DXF
case/Bottom - Outline 2 - Inner - Plexi Case Parts.DXF
case/Bottom - Outline 2 - Outer - Plexi Case Parts.DXF
case/CornerSupport.DXF
case/CornerSupport.SLDPRT
case/CornerSupport.STEP
case/CornerSupport.STL
case/CornerSupport_NominalFit.SLDPRT
case/CornerSupport_NominalFit.STL
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

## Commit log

2026-08-18 Add fight stick panel layouts: DXF, SVG, previews, and docs
    [aegis_all_button.dxf, american_s.dxf, american_s_24mm_buttons.dxf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]
2026-08-19 Add inner support variants with Sanwa OBSF ear relief slots
    Every layout now has an inner_support_ twin where each button hole is
    unioned with a rectangular relief slot for Sanwa OBSF snap-in button
    ears (6x35mm for 30mm buttons, 5x29mm for 24mm, rotated 30deg CW from
    vertical), doubling the set to 266 layouts / 532 files.
    - 133 new DXF and 133 new SVG inner support layouts
    - 53 new preview PNGs, including inner support explainer images
    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
    [inner_support_aegis_all_button.dxf, inner_support_american_s.dxf, inner_support_american_s_24mm_buttons.dxf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]
2026-08-20 Relicense from GPL-3.0 to CC BY-SA 4.0
    CC BY-SA 4.0 is the conventional licence for design files and matches
    this repository's intent directly: attribution is the enforceable core,
    share-alike keeps modified layouts open, and physical panels cut from
    the files carry no obligations beyond credit.
    - LICENSE: replace GPL-3.0 text with the official CC BY-SA 4.0 legal code
    - README: name the licence explicitly in Licence and attribution
2026-08-20 Credit ASI for the GL lever mounting hole pattern
    Thank you to ASI (https://asindo.pro/) for the GL lever layout that the
    GL_PLATE_HOLES joystick mounting pattern is based on.
2026-08-20 Add ASI to the NOTICE.md sources register
    The GL_PLATE_HOLES lever mounting pattern is based on the GL lever
    mounting plate by ASI (https://asindo.pro/).
2026-08-20 Add ASI S24/S30/B30 layouts and solve inner support slot angles
    New manufacturer layouts section, starting with three ASI layouts
    measured by sub pixel circle fitting of ASI's published product renders
    (accurate to roughly a third of a millimetre, not official files):
    asi_s24, asi_s30 and asi_b30 (leverless), each with an inner_support_
    twin, plus verification previews. 272 layouts / 544 files total.
    All inner support files regenerated with per-layout solved slot angles.
    Slots default to 30deg clockwise from vertical but may sit at any 15deg
    multiple; a solver maximises the smallest web between neighbouring
    profiles, then pulls every button it can back to the default. Worst web
    across the l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
    [asi_b30.dxf, asi_s24.dxf, asi_s30.dxf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]
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2026-08-20 Add Mortal Kombat 3 / UMK3 dedicated cabinet panel layouts
    First cabinet layout: one player's half of the dedicated MK3/UMK3
    control panel, from Twistedsymphony's dimensioned drawing on
    classicarcadecabinets.com. Imperial throughout (1.125 in holes, whole
    sixteenth spacings) converted exactly at 25.4, with the Happ lever hole
    replaced by Industrias Lorenzo's Eurojoystick 2 bore and mounting
    pattern (35 mm bore, IL_PLATE_HOLES layer). A _jp twin keeps the same
    button centres with 30 mm Sanwa holes and the standard GL plate.
    276 layouts / 552 files total.
    - mk3_umk3_dedicated and mk3_umk3_dedicated_jp with inner_support
    twins: 4 DXFs, 4 SVGs, 4 previews
    - README: cabinet layouts section, la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
    [inner_support_aegis_all_button.dxf, inner_support_american_s.dxf, inner_support_american_s_24mm_buttons.dxf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]
2026-08-20 Restore licence statement and GL lever credit; fix stale badges
    The regenerated docs again dropped the CC BY-SA 4.0 paragraph and the
    ASI GL lever mounting plate credit (asindo.pro); restored in README and
    NOTICE. Also updated the README badges from 272/544 to 276/552 to match
    the new totals.
2026-08-21 Add Neo Geo MVS cabinet panel layouts
    Second cabinet: the Neo Geo MVS control panel, one player's lever and
    four buttons from Crowquilll's drilling templates (traced from an
    original dedicated 2-25 cabinet CPO, dated 7/07). Two hardware cuts of
    the same hole positions: neogeo_mvs with 30 mm Sanwa holes and the GL
    lever plate, neogeo_mvs_american with the template's own 1.1875 in
    holes and an IL Eurojoystick 2 lever cut. Both with inner_support
    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
    [aegis_all_button.dxf, american_s.dxf, american_s_24mm_buttons.dxf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]
2026-08-21 Rename hardware variants to _parts suffixes; add american_s_american_parts
    Cabinet layout names now say which hardware they carry instead of
    leaving one side implicit:
    - mk3_umk3_dedicated -> mk3_umk3_dedicated_american_parts
    - mk3_umk3_dedicated_jp -> mk3_umk3_dedicated_japanese_parts
    - neogeo_mvs -> neogeo_mvs_japanese_parts
    - neogeo_mvs_american -> neogeo_mvs_american_parts
    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
    [aegis_all_button.dxf, american_s.dxf, american_s_24mm_buttons.dxf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]
2026-08-21 Add Vewlix 12 button modern layout; adjust Neo Geo ear slot angles
    New layout: vewlix_12button_modern in 82 mm and 95 mm lever spacings,
    each with an inner_support twin. 286 layouts / 572 files total.
    Also re-solved the ear relief slot angles on
    inner_support_neogeo_mvs_japanese_parts: two slots rotated, button
    centres unchanged.
    - 4 new DXFs, 4 new SVGs, 4 new previews
    - README: Vewlix 12 button catalogue section, updated counts and badges
    - NOTICE: source entry for the new layout
    - Refresh arcade-panel-layouts-github.zip
    [inner_support_vewlix_12button_modern_82mm_spacing.dxf, inner_support_vewlix_12button_modern_95mm_spacing.dxf, vewlix_12button_modern_82mm_spacing.dxf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]
2026-08-22 Add Vewlix Okayama 10 button layout
    New layout: vewlix_okayama_10button in 82 mm and 95 mm lever spacings,
    each with an inner_support twin, from a panel photographed and posted
    by @GAMING_okayama on Twitter/X. 290 layouts / 580 files total.
    - README: catalogue section, updated counts and badges
    - NOTICE: @GAMING_okayama source entry
    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
    [inner_support_vewlix_okayama_10button_82mm_spacing.dxf, inner_support_vewlix_okayama_10button_95mm_spacing.dxf, vewlix_okayama_10button_82mm_spacing.dxf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]
2026-08-22 Add WASD variants of every lever layout
    Every joystick layout now has a _wasd twin with a four button
    directional cluster in place of the lever; the action buttons do not
    move. Standard and inner support versions both covered.
    568 layouts / 1136 files total.
    - 278 new DXFs, 278 new SVGs, 67 new previews
    - README: WASD layouts section and catalogue entries, updated counts
    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
    [american_s_24mm_buttons_wasd.dxf, american_s_82mm_spacing_24mm_buttons_wasd.dxf, american_s_82mm_spacing_wasd.dxf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]
2026-08-23 Add laser cut acrylic case with 3D printed supports
    New case/ directory: a plexi enclosure, 451 x 303 mm inside a 62.2 mm
    stack, sized to take any layout in the repository. Twenty four DXF cut
    profiles, three printed parts as STL and STEP, SolidWorks sources,
    previews, and its own README - which leads with a disclaimer that no
    physical build has validated the files yet.
    - 50 new files under case/
    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
    [All Plexi Case Parts.SLDPRT, Blank_CenterSupport.DXF, Blank_CenterSupport.SLDPRT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]
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2026-08-23 Add fight board bracket to the case; drop script mentions from NOTICE
    New printed part: FightBoardBracket as STL and STEP, modeled directly
    from the panel's own hole pattern (no SolidWorks source), with a 3D
    preview. Other support previews re-rendered, case README updated.
    NOTICE: the case entry again named internal generation scripts that are
    not part of the repository; reworded to describe the derivation without
    naming them, as before.
    [FightBoardBracket.STEP, FightBoardBracket.STL]
2026-08-23 Add Neo Geo panel family and IST MakeStick layouts from issues 3 and 4
    The Neo Geo section grows from one panel to five, renaming the existing
    MVS files to _type1_ to make room:
    - neogeo_mvs_type1 (was neogeo_mvs): japanese, american and wasd cuts
    - neogeo_mvs_type2: the USA straight-line B/C/D panel, japanese and
    american hardware
    - neogeo_mini: the aggressive AES-style curve, japanese and american
    - neogeo_mvs_u4: the MVS-U4 25 gentle curve, japanese
    - neogeo_sc19_4: the SNK Neo SC19-4 candy cab panel, japanese
    Plus the first two IST MakeStick layouts from issue 4: ist_type1 and
    ist_type3, japanese parts. All with inner_support twins.
    584 layouts / 1168 files total.
    - 22 new DXFs, 22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
    [inner_support_ist_type1_japanese_parts.dxf, inner_support_ist_type3_japanese_parts.dxf, inner_support_neogeo_mini_american_parts.dxf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]
2026-08-23 Add support hardware cutouts and NominalFit printed part variants
    New 'support hardware/' folder: 1:1 panel cutouts for hardware that
    goes around a panel rather than in it, DXF and SVG with the origin on
    the main bore. First two: the Neutrik D-shape 24 mm pass through
    cutout (the industry standard D shell, dimensions from Neutrik's
    published data) and the E-Switch RR1 round rocker cutout. Each with
    SolidWorks source, previews, and a documented README.
    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
    [Blank_CenterSupport_NominalFit.SLDPRT, Blank_CenterSupport_NominalFit.STEP, Blank_CenterSupport_NominalFit.STL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]
2026-08-24 Add BattleMonkey Brook cable caddy; document support fit variants
    First outside file contribution: 'caja brook cables v1.2' by
    BattleMonkey Custom Arcade Sticks (@XBattleMonkeyX), a 3D printed
    Brook fight board caddy that mounts on the case's four PCB points and
    routes the sleeved cable bundle to the board. STEP + SLDPRT + install
    photo, with a documented README in 'BattleMonkey Contributions/'.
    Case supports now come in slot-width fit variants for the acrylic
    tolerance band (as-supplied 9.3 mm, _NominalFit 8.6 mm, _TightFit
    8.2 mm), documented in the case README with an availability note:
    _TightFit ships for the blank center support only so far. The corner
    NominalFit files are renamed hyph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
    [Blank_CenterSupport_TightFit.SLDPRT, Blank_CenterSupport_TightFit.STEP, Blank_CenterSupport_TightFit.STL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]

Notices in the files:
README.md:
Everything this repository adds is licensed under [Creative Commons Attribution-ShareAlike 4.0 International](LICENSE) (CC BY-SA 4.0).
